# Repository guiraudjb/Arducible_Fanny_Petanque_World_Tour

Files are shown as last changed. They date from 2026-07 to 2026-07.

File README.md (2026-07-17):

# Fanny Pétanque World Tour

*An #ARDUCIBLE pétanque game.*

Borne d'arcade de pétanque en Python/Pygame : le joueur vise trois cibles
physiques à capteurs à effet Hall (pilotées par un Arduino Leonardo en
clavier), pendant qu'une webcam avec suivi de pose (MediaPipe) vérifie qu'il
reste dans la zone de tir. Tour du monde à travers 115 pays, chacun avec son
hymne, son portrait et sa réplique.

## Comment ça marche

- **Les cibles sont physiques**, montées sur un socle et équipées de capteurs
  à effet Hall. Elles sont raccordées à un **Arduino Leonardo**, que
  l'ordinateur reconnaît comme un clavier USB : toucher une cible envoie une
  touche (`E`, `R` ou `T`) au jeu.
- **La webcam ne sert pas à viser.** Couplée à un suivi de pose
  ([MediaPipe](https://ai.google.dev/edge/mediapipe)), elle vérifie juste que
  le joueur est bien positionné dans la zone de tir désignée. S'il en sort,
  les cibles sont inhibées (`zoneinterdite`) jusqu'à ce qu'il y revienne.
- **Tour du monde.** Chaque série de tirs réussis (`hits_per_country` dans
  `config.ini`) fait passer au pays suivant parmi 115 : décor, hymne
  national, portrait et réplique de la compagne de route Fanny changent à
  chaque étape (voir `Scripts/dialogues.py`).
- Le jeu reste jouable sans webcam ni cibles physiques (mode clavier seul).

## Les 4 jeux en un coup d'œil

Un seul châssis physique (3 cibles en ligne) sert au jeu de base, un second
châssis (7 cibles en étoile de David, cochonet au centre) sert à Hardcore et
Round the Clock. Quizz ne tire sur aucun châssis.

| Jeu | Fichier | Chassis | Principe | Touches | Modes | High score |
|---|---|---|---|---|---|---|
| **Fanny World Tour** | `main.py` | 3 cibles en ligne | Solo, contre-la-montre, tour du monde | `E R T` | Tour complet ou par continent | `[Score]` |
| **Hardcore** | `main_hardcore.py` | 7 cibles étoile | Identique à Fanny, cochonet = pays suivant | `E R T Y U I O` | Tour complet ou par continent | `[Hardcore]` |
| **Quizz** | `main_quizz.py` | Aucun (pas de tir) | 5 questions par pays (pétanque + culture générale) | `E R T` (choix) | Tour complet ou par continent | `[Quizz]` |
| **Round the Clock** | `main_round_the_clock.py` | 7 cibles étoile | Multijoueur tour par tour, viser la cible imposée dans l'ordre 1→7 | `E R T Y U I O` (+ `Y`/`U`/`O` pour options/aide/valider) | Nombre de joueurs (1-6) et de manches (3-12) réglables en jeu | Aucun (non persistant, absent de l'original) |

Déroulement commun à Fanny World Tour, Hardcore et Quizz (Round the Clock a
son propre menu à cibles, voir plus bas) : **accueil** (`INSERT COIN` ou
`FREEPLAY`) → **choix du mode** (tour complet ou un seul continent, carrousel
`E`/`T`, validation `R`, ou lancement automatique au bout de 60 s sans choix)
→ **décompte `GAME START IN`** → **partie** → **écran de fin**, puis retour à
l'accueil.

## Installation

```bash
pip install -r requirements.txt
python main.py
```

Un `config.ini` est généré automatiquement au premier lancement s'il
n'existe pas.

## Configuration (`config.ini`)

| Section | Clé | Rôle |
|---|---|---|
| `TimeSetting` | `intro_length`, `game_length`, `ending_length`, `splash_length` | Durées (s) des différents écrans |
| `BonusTime` | `time`, `country_change_time` | Bonus de temps par tir réussi / par changement de pays |
| `WorldTour` | `hits_per_country` | Nombre de tirs pour passer au pays suivant |
| `CamActivation` | `Webcam` | Active/désactive la webcam. Tout ce qui décrit la caméra elle-même (index, résolution, cadrage de la zone de tir, cadence d'analyse) est dans `camera_calibration.json`, pas ici — voir plus bas |
| `Screen` | `Fullscreen`, `CRT` | Plein écran, effet de superposition CRT rétro |
| `Audio` | `Music`, `Effects`, `FadeoutTime` | Musique de menu, effets sonores, fondu |
| `Resolution` | `Resolution` | `1080`, `720`, `360`, `240` (sinon 1024x768) |
| `Debug` | `DebugLine`, `FPS`, `ShowFps`, `DebugCam`, `Credit`, `FreePlay` | Grille de repérage, FPS cible/affiché, superposition du squelette MediaPipe sur l'image caméra réelle (au lieu d'un fond noir), crédits de départ, mode freeplay (voir ci-dessous) — section partagée par les 3 jeux |
| `Score` | `high_score` | Meilleur score de Fanny World Tour (jeu de base), sauvegardé automatiquement |
| `Hardcore` | `high_score`, `hits_per_country` | Meilleur score et rythme du tour du monde propres au mode Hardcore (7 cibles) |
| `Quizz` | `high_score` | Meilleur score du Quizz (bonnes réponses sur 575), sauvegardé automatiquement |
| `RoundTheClock` | `targets`, `default_players`, `min_players`, `max_players`, `default_rounds`, `min_rounds`, `max_rounds`, `shots_per_turn`, `hit_cooldown_ms`, `menu_cooldown_ms`, `banner_duration_s` | Réglages propres à Round the Clock (pas de high score persistant) |

### Crédits / mode freeplay

Comportement identique sur les 3 jeux (Fanny World Tour, Hardcore, Round the
Clock) : par défaut, l'écran d'accueil affiche **INSERT COIN** et le nombre
de crédits (`[Debug] Credit`) en bas à droite tant qu'aucun crédit n'est
disponible ; la touche `C` en ajoute un (borne réelle : pièce détectée par
l'Arduino). Sur Hardcore et Round the Clock, les 7 touches de cible
`E R T Y U I O` occupent déjà tout l'alphabet utile du chassis étoile, d'où
le choix de `C`, libre sur les 3 jeux.

Avec `[Debug] FreePlay = True` : "INSERT COIN" et le compteur de crédits
sont remplacés par **"PRESS A TARGET TO PLAY"** / **FREEPLAY**. Presser
n'importe quelle cible physique équivaut alors à insérer un crédit fictif —
Fanny/Hardcore/Quizz lancent leur écran de choix du mode (voir ci-dessous),
Round the Clock débloque directement son menu (`O` pour démarrer).

### Choix du mode (tour complet ou par continent)

Sur Fanny World Tour, Hardcore et Quizz, un crédit disponible ouvre un écran
de sélection avant que la partie ne démarre : un mode à la fois au centre
(tour complet des 115 pays, ou un seul continent), avec le nombre de pays
qu'il contient. Navigation au carrousel — `E` précédent, `T` suivant, `R`
valider — matérialisée par les 3 boules physiques du socle (gauche/centre/
droite), le joueur n'ayant pas de clavier sous les yeux sur la borne. Sans
choix au bout de **60 secondes**, la partie démarre automatiquement sur le
mode affiché (comme un appui sur `R`). Seul le mode "Tour complet" alimente
le high score de sa section (`[Score]`/`[Hardcore]`/`[Quizz]`) — un score sur
un seul continent, moins long, n'est pas comparable et s'affiche à part.

## Contrôles clavier

| Touche | Action |
|---|---|
| `E` / `R` / `T` | Cible gauche / centre / droite (normalement envoyées par l'Arduino) |
| `C` | Ajoute un crédit |
| `M` | Coupe / relance la musique |
| `S` | Active / coupe les effets sonores |
| `Échap` | Quitte le jeu |

## Structure du projet

```
main.py                        Fanny World Tour : boucle de jeu et logique d'écran
main_hardcore.py                Hardcore (7 cibles), fork de main.py
main_quizz.py                   Quizz (sans tir), fork de main.py
main_round_the_clock.py         Round the Clock (7 cibles, multijoueur), indépendant
Scripts/init.py                 Config.ini, polices, couleurs, canaux audio
Scripts/Sprites.py               Sprites (cibles, fonds, Fanny, bulles de dialogue)
Scripts/opencvcam.py             Capture webcam + détection de pose MediaPipe
Scripts/camera_calibration.py    Lecture/écriture camera_calibration.json
Scripts/dialogues.py             Données des 115 pays (généré automatiquement)
Scripts/quiz_questions.py        Questions du quizz par pays (voir main_quizz.py)
Scripts/quiz_audio.py            Retrouve le mp3 TTS correspondant à un texte de quizz
Scripts/round_the_clock/         État et sprites propres à Round the Clock
assets/                          Images, sons, fonts, modèle MediaPipe
```

## Calibration de la caméra

`calibrate_camera.py` est un script autonome (indépendant des deux jeux) pour
régler la webcam et la zone de tir qu'elle analyse : index de la caméra,
résolution de capture (réglage manuel pixel par pixel, ou menu déroulant
"Preset resolution" listant les résolutions courantes — la caméra détectée
est automatiquement sondée pour ne proposer que celles qu'elle supporte
réellement), taille et position (décalage) de la zone recadrée envoyée à
MediaPipe. Deux fenêtres live — l'image caméra complète avec la zone en
surbrillance, et exactement ce que le jeu voit (recadrage + squelette
détecté + statut "ZONE OK"/"HORS ZONE") — permettent d'ajuster les curseurs
jusqu'à ce que le cadrage corresponde à la zone marquée au sol.

```bash
python3 calibrate_camera.py
# ou
./run_calibrate_camera.sh
```

Réglages enregistrés dans `camera_calibration.json` (à la racine du dépôt,
**pas** `config.ini`) : un profil complet par index de caméra, pour ne pas
perdre le calibrage d'une caméra en en recalibrant une autre — changer de
caméra dans le script recharge automatiquement son profil déjà sauvegardé.
`config.ini` garde seulement l'interrupteur `[CamActivation] Webcam`.

Sauvegarde : bouton **SAUVEGARDER** cliquable en haut à gauche de la fenêtre
"Camera complete" (vert = modifications non sauvegardées, gris = déjà à
jour), ou touche `s` — les deux font la même chose : sauvegardent le profil
de la caméra courante et en font la caméra active pour les jeux.

Autres touches : `r` réinitialise aux valeurs sauvegardées, `p` ressonde les
résolutions supportées, `q`/Échap quitte.

## Round the Clock (chassis à 7 cibles)

`main_round_the_clock.py` est un **second jeu**, indépendant de Fanny World
Tour, pour un chassis différent équipé de **7 cibles physiques disposées en
étoile de David** (6 boules sur les pointes de l'étoile, un **cochonet** au
centre). Même principe électronique (capteurs à effet Hall → Arduino →
clavier USB, touches `E R T Y U I O` pour les cibles 1 à 7), mais un jeu très
différent : un **multijoueur au tour par tour (1 à 6 joueurs, 3 à 12
manches)**, porté fidèlement depuis la version Lua/Defold d'origine
(`ressources/Petanque-challenge-Round-the-clock/`).

- Chaque joueur dispose de 3 tirs par passage et doit toucher les cibles
  dans l'ordre 1 à 7 (au-delà, cible aléatoire).
- Toucher une autre cible que celle désignée compte comme un raté — c'est
  aussi le seul moyen de comptabiliser un tir qui n'a touché aucune cible
  physique (pas de capteur dédié à "l'échec total").
- Jouable sans matériel physique : flèches gauche/droite simulent
  respectivement un tir réussi / raté sur la cible active (pas de bouton
  affiché à l'écran, c'est un raccourci clavier discret).
- Reprend le suivi de zone par webcam (MediaPipe) comme Fanny World Tour
  (absent du jeu Defold d'origine, ajouté lors du portage) : même position à
  l'écran (caméra et anneau rouge/vert centrés en haut) et même système de
  double fond par pays (variante `.jpg` pleine si pas de webcam, variante
  `.png` à découpe ovale transparente si webcam active, à travers laquelle
  la caméra apparaît).
- Le décor change de pays (parmi les fonds de `assets/Images/BackgroundWorldTour/`
  déjà utilisés par Fanny World Tour) après chaque tir réussi.
- Menu et écran de fin reprennent l'illustration de fin de Fanny World Tour
  (`assets/Images/EndingScreenWorldTour.jpg`).

```bash
python3 main_round_the_clock.py
# ou
./run_round_the_clock.sh
```

Partage le même `config.ini` que Fanny World Tour (sections `Screen`,
`Audio`, `CamActivation`, `Debug`, `Resolution` communes), avec sa propre
section `[RoundTheClock]` (nombre de joueurs/manches par défaut, tirs par
passage, anti-rebond).

## Hardcore (chassis à 7 cibles)

`main_hardcore.py` est un **troisième jeu** : le principe exact de Fanny
World Tour (solo, contre-la-montre, tour du monde à travers 115 pays, Fanny
en compagne de route) mais joué sur le chassis à **7 cibles en étoile de
David** de Round the Clock, au lieu des 3 cibles en ligne du jeu d'origine.
Réutilise directement `Scripts/init.py` et `Scripts/Sprites.py` (mêmes
fonds, portraits, hymnes, webcam) — seule la gestion des cibles change.

- 7 cibles, touches `E R T Y U I O`. Le tir qui fait passer au pays suivant
  (score+1 multiple de `hits_per_country`) vise systématiquement le
  **cochonet**, au centre de l'étoile ; tous les autres tirs visent une
  boule périphérique tirée au hasard (jamais deux fois de suite la même).
- Pas d'annonce vocale de cible ("gauche/centre/droite" ne correspond plus
  à rien en étoile) : seul le son d'impact joue.
- `high_score` et `hits_per_country` (rythme du tour du monde) propres à
  Hardcore, dans leur propre section `[Hardcore]` de `config.ini`,
  indépendants du jeu de base.

```bash
python3 main_hardcore.py
# ou
./run_hardcore.sh
```

## Quizz (tour du monde + culture générale, sans tir)

`main_quizz.py` est un **quatrième jeu**, quizz uniquement : pas de cibles,
pas de webcam, pas de chrono de partie. Après avoir inséré un crédit, le
joueur enchaîne directement les **115 quizz** (un par pays du tour, 5
questions chacun) dans l'ordre, en répondant avec les touches `E R T`
(choix gauche/centre/droite). Le score final est le nombre total de bonnes
réponses sur l'ensemble du tour (sur 575).

- Décor, hymne et portrait de Fanny changent à chaque pays, comme dans
  Fanny World Tour, mais pilotés directement par pays plutôt que par un
  score de tir.
- Questions dans `Scripts/quiz_questions.py` (généré à partir de
  `Scripts/dialogues.py` + une table de métadonnées pays) : 1 question sur
  la pétanque dans le pays (reconnaître la bonne réplique de Fanny parmi 3),
  4 questions de culture générale (capitale, continent, langue, monnaie).
  Chaque mauvaise réponse est toujours un vrai fait — juste celui d'un
  *autre* pays de la liste — jamais une donnée inventée.
- Questions et réponses affichées à l'écran avec une police pleine à
  accentuation complète (`assets/RoundTheClock/Fonts/DejaVuSans.ttf`) —
  Alfa Slab One n'a pas les glyphes accentués (é, à, ç...) nécessaires en
  français — et **narrées en voix de synthèse** (gTTS) : un mp3 par texte
  unique dans `assets/Sounds/QuizzTTS/`, généré hors-ligne par
  `ressources/utils/generate_quiz_audio.py` et retrouvé à l'exécution via
  `Scripts/quiz_audio.py` (silencieux si un fichier manque plutôt que de
  planter).
- `high_score` propre à Quizz (nombre de bonnes réponses sur 575), dans sa
  propre section `[Quizz]` de `config.ini`, indépendant des autres jeux.

```bash
python3 main_quizz.py
# ou
./run_quizz.sh
```

## Licence

CC BY 4.0 — voir [`LICENSE`](LICENSE).

Fanny Pétanque World Tour © Jean-Baptiste Guiraud. Vous êtes libre de
partager et d'adapter ce travail, y compris à des fins commerciales, à
condition de créditer l'auteur.

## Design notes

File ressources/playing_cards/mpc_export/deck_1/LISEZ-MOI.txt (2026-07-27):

Fanny Pétanque World Tour — Volume 1 (54 cartes)
Export pour MakePlayingCards.com

1. Aller sur makeplayingcards.com -> Design & Print -> Game / Custom Cards
   -> choisir le produit "Custom Game Cards (63 x 88mm)".
2. Quantité : 54 cartes uniques, 1 exemplaire de chaque (1 jeu).
3. Verso ("Card Back") : choisir l'option "same image for all cards" /
   "one card back for the whole deck" et uploader back.png.
4. Recto ("Card Front") : uploader les 54 fichiers du
   dossier fronts/ EN GARDANT L'ORDRE NUMÉRIQUE du préfixe (01_, 02_, ...) -
   c'est l'ordre A,2,3...K de Coeur, Carreau, Trèfle, Pique puis les Jokers.
5. Les fichiers sont déjà au bon format (fond perdu + marge de sécurité
   inclus, 300 dpi) : ne pas les recadrer ni les redimensionner sur le site.

Fichiers : 54 images dans fronts/ + back.png (verso unique).
Tout est aussi disponible pré-zippé : deck_1.zip

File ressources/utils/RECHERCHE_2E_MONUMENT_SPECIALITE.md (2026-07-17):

# Recherche du 2e monument / site touristique / spécialité par pays

Registre des recherches menées pour trouver, pour chacun des 112 pays du
tour (`Scripts/dialogues.py`), un **second** monument, site touristique ou
spécialité locale réel et vérifiable, DIFFÉRENT de celui déjà utilisé dans
`quiz_monuments_facts.py` (question 2 du quizz). Ce second fait remplace
la question "sur quel continent ?" (question 5), jugée trop facile, sans
jamais révéler dans l'énoncé qu'il s'agit d'un monument ou d'une
spécialité (voir `ressources/utils/build_quiz_questions.py`).

Données dans `ressources/utils/quiz_second_monuments_facts.py`
(`SECOND_MONUMENTS`), catégorisées dans
`ressources/utils/quiz_monument_categories.py`
(`SECOND_MONUMENT_CATEGORIES`) pour permettre des distracteurs de la même
catégorie (château face à château, etc.), comme pour la question 2.

**112/112 pays documentés**, aucun "aucune information trouvée".

## Europe

0 Allemagne : la porte de Brandebourg — fr.wikipedia.org/wiki/Porte_de_Brandebourg
1 Andorre : la Casa de la Vall — museus.ad/fr/monuments/casa-de-la-vall2, en.wikipedia.org/wiki/Casa_de_la_Vall
2 Angleterre : Big Ben — fr.wikipedia.org/wiki/Big_Ben
4 Autriche : le Sachertorte — fr.wikipedia.org/wiki/Sachertorte
5 Belgique : l'Atomium — fr.wikipedia.org/wiki/Atomium
6 Bulgarie : la vallée des Roses — fr.wikipedia.org/wiki/Vallée_des_Roses_(Bulgarie)
7 Danemark : les jardins de Tivoli — fr.wikipedia.org/wiki/Jardins_de_Tivoli
8 Écosse : le château d'Édimbourg — fr.wikipedia.org/wiki/Château_d'Édimbourg
9 Espagne : l'Alhambra de Grenade — fr.wikipedia.org/wiki/Alhambra
10 Estonie : le Laulupidu — estonianworld.com, en.wikipedia.org/wiki/Estonian_Song_Festival
11 Finlande : la forteresse de Suomenlinna — fr.wikipedia.org/wiki/Suomenlinna
12 France : le Mont-Saint-Michel — fr.wikipedia.org/wiki/Mont-Saint-Michel
13 Guernesey : Hauteville House — fr.wikipedia.org/wiki/Hauteville_House
14 Hongrie : les bains Széchenyi — fr.wikipedia.org/wiki/Bains_Széchenyi
15 Irlande : Newgrange — fr.wikipedia.org/wiki/Newgrange
16 Italie : la tour de Pise — fr.wikipedia.org/wiki/Tour_de_Pise
17 Jersey : le château de Mont Orgueil — fr.wikipedia.org/wiki/Château_de_Mont_Orgueil
18 Lettonie : la vieille ville de Riga (Art nouveau) — whc.unesco.org/en/list/852
19 Lituanie : la colline des Croix — fr.wikipedia.org/wiki/Colline_des_Croix
20 Luxembourg : le palais grand-ducal — fr.wikipedia.org/wiki/Palais_grand-ducal_(Luxembourg)
21 Monaco : le Grand Prix de Monaco — fr.wikipedia.org/wiki/Grand_Prix_automobile_de_Monaco
22 Norvège : les stavkirker — fr.wikipedia.org/wiki/Stavkirke
23 Pays-Bas : le parc floral de Keukenhof — fr.wikipedia.org/wiki/Keukenhof
24 Pays de Galles : Llanfairpwllgwyngyll... — en.wikipedia.org/wiki/Llanfairpwllgwyngyll
25 Pologne : les mines de sel de Wieliczka — fr.wikipedia.org/wiki/Mine_de_sel_de_Wieliczka
26 Portugal : le palais de Pena — fr.wikipedia.org/wiki/Palais_national_de_Pena
27 Roumanie : le palais du Parlement — en.wikipedia.org/wiki/Palace_of_the_Parliament
28 Russie : la cathédrale Saint-Basile-le-Bienheureux — fr.wikipedia.org/wiki/Cathédrale_Basile-le-Bienheureux
29 Saint-Marin : les timbres-poste saint-marinais — en.wikipedia.org/wiki/Postage_stamps_and_postal_history_of_San_Marino
30 Serbie : le monastère de Studenica — fr.wikipedia.org/wiki/Monastère_de_Studenica
31 Slovaquie : le château de Spiš — fr.wikipedia.org/wiki/Château_de_Spiš
32 Slovénie : les grottes de Postojna — fr.wikipedia.org/wiki/Grottes_de_Postojna
33 Suède : l'Icehotel de Jukkasjärvi — fr.wikipedia.org/wiki/Icehotel
34 Suisse : le Jungfraujoch — fr.wikipedia.org/wiki/Jungfraujoch
35 Tchéquie : l'horloge astronomique de Prague — fr.wikipedia.org/wiki/Horloge_astronomique_de_Prague
37 Ukraine : le bortsch ukrainien — ich.unesco.org/fr/USL/la-culture-de-la-preparation-du-bortsch-ukrainien-01852

## Asie

3 Arménie : le monastère de Guéghard — whc.unesco.org/en/list/960
36 Turquie : Pamukkale — en.wikipedia.org/wiki/Pamukkale
65 Afghanistan : le Minaret de Jam — whc.unesco.org/en/list/211
66 Bangladesh : les Sundarbans — en.wikipedia.org/wiki/Sundarbans
67 Brunei : Kampong Ayer — en.wikipedia.org/wiki/Kampong_Ayer
68 Cambodge : le temple de Preah Vihear — whc.unesco.org/en/list/1224
69 Chine : l'Armée de terre cuite de Xi'an — fr.wikipedia.org/wiki/Armée_de_terre_cuite
70 Corée du Sud : le palais Gyeongbokgung — en.wikipedia.org/wiki/Gyeongbokgung
71 Inde : le Fort Rouge de Delhi — en.wikipedia.org/wiki/Red_Fort
72 Indonésie : le temple de Prambanan — en.wikipedia.org/wiki/Prambanan
73 Iran : la place Naghsh-e Jahan — en.wikipedia.org/wiki/Naqsh-e_Jahan_Square
74 Japon : le château de Himeji — en.wikipedia.org/wiki/Himeji_Castle
75 Kazakhstan : le mausolée de Khoja Ahmed Yasavi — whc.unesco.org/en/list/1103
76 Kirghizistan : le lac Issyk-Koul — islands.com
77 Laos : la Plaine des Jarres — en.wikipedia.org/wiki/Plain_of_Jars
78 Malaisie : les grottes de Batu — en.wikipedia.org/wiki/Batu_Caves
79 Mongolie : le monastère d'Erdene Zuu — en.wikipedia.org/wiki/Erdene_Zuu_Monastery
80 Myanmar : Bagan — en.wikipedia.org/wiki/Bagan
81 Népal : Lumbini — en.wikipedia.org/wiki/Lumbini
82 Pakistan : la mosquée Badshahi — en.wikipedia.org/wiki/Badshahi_Mosque
83 Philippines : les Chocolate Hills — en.wikipedia.org/wiki/Chocolate_Hills
84 Singapour : Gardens by the Bay — en.wikipedia.org/wiki/Gardens_by_the_Bay
85 Taïwan : le bubble tea — taipeitimes.com
86 Thaïlande : le parc historique d'Ayutthaya — en.wikipedia.org/wiki/Ayutthaya_Historical_Park
87 Turkménistan : le cheval Akhal-Teke — en.wikipedia.org/wiki/Akhal-Teke
88 Vietnam : la vieille ville de Hoi An — en.wikipedia.org/wiki/Hoi_An

## Afrique

38 Algérie : Timgad — whc.unesco.org/en/list/194
39 Bénin : la Porte du Non-Retour d'Ouidah — en.wikipedia.org/wiki/Door_of_No_Return,_Ouidah
40 Burkina Faso : la Grande Mosquée de Bobo-Dioulasso — en.wikipedia.org/wiki/Grand_Mosque_of_Bobo-Dioulasso
41 Cameroun : le mont Cameroun — en.wikipedia.org/wiki/Mount_Cameroon
42 Comores : la Grande Mosquée du Vendredi de Moroni — fr.wikipedia.org/wiki/Mosquée_de_Moroni
43 Congo : la basilique Sainte-Anne-du-Congo — fr.wikipedia.org/wiki/Basilique_Sainte-Anne-du-Congo_de_Brazzaville
44 Côte d'Ivoire : Grand-Bassam — whc.unesco.org/en/list/1322
45 Djibouti : le lac Abbé — cityzeum.com
46 Égypte : le temple d'Abou Simbel — fr.wikipedia.org/wiki/Abou_Simbel
47 Gabon : le parc national de Loango — en.wikipedia.org/wiki/Loango_National_Park
48 Guinée : le mont Nimba — whc.unesco.org/en/list/155
49 Libye : la vieille ville de Ghadamès — whc.unesco.org/en/list/362
50 Madagascar : les Tsingy de Bemaraha — whc.unesco.org/en/list/494
51 Mali : la falaise de Bandiagara (pays Dogon) — whc.unesco.org/en/list/516
52 Maurice : Le Morne Brabant — whc.unesco.org/en/list/1259
53 Mauritanie : la structure de Richat — en.wikipedia.org/wiki/Richat_Structure
54 Maroc : le Jardin Majorelle — en.wikipedia.org/wiki/Majorelle_Garden
55 Niger : la réserve naturelle de l'Aïr et du Ténéré — whc.unesco.org/en/list/573
56 Ouganda : les tombeaux des rois du Buganda à Kasubi — whc.unesco.org/en/list/1022
57 République Centrafricaine : le parc national Manovo-Gounda St Floris — whc.unesco.org/en/list/475
58 RD Congo : la réserve de faune à okapis — whc.unesco.org/en/list/718
59 Sénégal : le lac Rose — fr.wikipedia.org/wiki/Lac_Rose
60 Seychelles : l'atoll d'Aldabra — whc.unesco.org/en/list/185
61 Tchad : le parc national de Zakouma — africanparks.org
62 Togo : le marché des féticheurs d'Akodessewa — fr.wikipedia.org/wiki/Marché_des_féticheurs
63 Tunisie : la médina de Tunis — whc.unesco.org/en/list/36
64 Zambie : le parc national de South Luangwa — southluangwa.com

## Amérique

89 Argentine : le glacier Perito Moreno — en.wikipedia.org/wiki/Perito_Moreno_Glacier
90 Bolivie : Tiwanaku — whc.unesco.org/en/list/567
91 Canada : le sirop d'érable — thecanadianencyclopedia.ca
92 Chili : Torres del Paine — en.wikipedia.org/wiki/Torres_del_Paine_National_Park
93 Colombie : Carthagène des Indes — whc.unesco.org/en/list/285
94 Costa Rica : Monteverde — en.wikipedia.org/wiki/Monteverde_Cloud_Forest_Reserve
95 Cuba : La Havane Vieille — whc.unesco.org/en/list/204
96 Équateur : le chapeau « Panama » de Montecristi — ecuadorianhands.com
97 États-Unis : le Grand Canyon — en.wikipedia.org/wiki/Grand_Canyon
98 Guatemala : Antigua Guatemala — whc.unesco.org/en/list/65
99 Haïti : le Palais Sans-Souci — whc.unesco.org/en/list/180
100 Mexique : la tequila — en.wikipedia.org/wiki/Tequila
101 Paraguay : le barrage d'Itaipu — en.wikipedia.org/wiki/Itaipu_Dam
102 Pérou : les lignes de Nazca — whc.unesco.org/en/list/700
103 République Dominicaine : le larimar — en.wikipedia.org/wiki/Larimar
104 Uruguay : Colonia del Sacramento — whc.unesco.org/en/list/747
105 Venezuela : les éclairs du Catatumbo — en.wikipedia.org/wiki/Catatumbo_lightning

## Océanie

106 Australie : la Grande Barrière de Corail — whc.unesco.org/en/list/154
107 Nouvelle-Calédonie : le lagon de Nouvelle-Calédonie — whc.unesco.org/en/list/1115
108 Nouvelle-Zélande : le Hobbiton Movie Set — en.wikipedia.org/wiki/Hobbiton_Movie_Set
109 Tahiti : le marae Taputapuatea — whc.unesco.org/en/list/1529
110 Vanuatu : le saut du Gol — fr.wikipedia.org/wiki/Saut_du_gol_(Vanuatu)
111 Wallis-et-Futuna : le site de Talietumu — easyvoyage.com, archeodyssee.fr

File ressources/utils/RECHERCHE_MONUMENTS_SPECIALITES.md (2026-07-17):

# Recherche monuments / sites touristiques / spécialités locales par pays

Registre des recherches menées pour documenter, pour chacun des 112 pays du
tour (`Scripts/dialogues.py`), un monument, site touristique ou spécialité
locale réel, précis et reconnaissable — utilisé pour la question 3 du
quizz (`Scripts/quiz_questions.py`, voir
`ressources/utils/build_quiz_questions.py` et
`ressources/utils/quiz_monuments_facts.py`).

Contrairement à la recherche pétanque (voir `RECHERCHE_PETANQUE_PAYS.md`),
la plupart de ces faits relèvent de la culture générale bien établie
(Tour Eiffel, Taj Mahal, Machu Picchu...) et n'ont pas nécessité de
recherche web poussée ; une recherche ciblée a été faite pour les pays
moins immédiatement connus (marquée "à vérifier" ci-dessous, avec sources).

**112/112 pays documentés** — aucun "aucune information trouvée" cette
fois (contrairement à la recherche pétanque, la culture générale/tourisme
offre toujours au moins un point d'ancrage réel pour chaque pays).

## Europe

Allemagne : château de Neuschwanstein · Andorre : escudella (à vérifier —
routard.com, grandvalira.com) · Angleterre : Stonehenge · Arménie :
monastère de Khor Virap (à vérifier — nomadays.fr, voyagearmenie.com) ·
Autriche : château de Schönbrunn · Belgique : Manneken-Pis · Bulgarie :
monastère de Rila · Danemark : la Petite Sirène · Écosse : Loch Ness ·
Espagne : Sagrada Família · Estonie : vieille ville de Tallinn (UNESCO,
whc.unesco.org) · Finlande : le sauna · France : tour Eiffel · Guernesey :
la vache Guernesey (à vérifier — fr.wikipedia.org, la-viande.fr) · Hongrie :
Parlement de Budapest · Irlande : falaises de Moher · Italie : Colisée ·
Jersey : la Jersey Royal (à vérifier — en.wikipedia.org, jersey.com) ·
Lettonie : Monument de la Liberté à Riga (à vérifier — cestee.fr,
routard.com) · Lituanie : château de Trakai · Luxembourg : Casemates du
Bock · Monaco : Casino de Monte-Carlo · Norvège : Geirangerfjord · Pays-Bas :
moulins de Kinderdijk · Pays de Galles : château de Caernarfon · Pologne :
château du Wawel · Portugal : tour de Belém · Roumanie : château de Bran ·
Russie : le Kremlin · Saint-Marin : Tre Torri du Mont Titano (vérifié —
whc.unesco.org/en/list/1245/) · Serbie : forteresse de Belgrade
(Kalemegdan) · Slovaquie : château de Bratislava (vérifié —
fr.wikipedia.org) · Slovénie : lac de Bled (vérifié — fr.wikipedia.org) ·
Suède : le Vasa · Suisse : le Cervin · Tchéquie : château de Prague ·
Turquie : Sainte-Sophie · Ukraine : Laure des Grottes de Kiev.

## Afrique

Algérie : Casbah d'Alger · Bénin : palais royaux d'Abomey · Burkina Faso :
ruines de Loropéni (à vérifier — whc.unesco.org/en/list/1225/) · Cameroun :
palais royal de Foumban (à vérifier — ayilaa.com) · Comores : le Karthala
(à vérifier — habarizacomores.com) · Congo : parc national d'Odzala-Kokoua
(à vérifier — fr.wikipedia.org) · Côte d'Ivoire : basilique Notre-Dame de
la Paix de Yamoussoukro · Djibouti : lac Assal (à vérifier —
guide.visitdjibouti.dj) · Égypte : pyramides de Gizeh · Gabon : parc
national de la Lopé (à vérifier — fr.wikipedia.org) · Guinée : massif du
Fouta Djalon (à vérifier — jeuneafrique.com) · Libye : Leptis Magna ·
Madagascar : allée des Baobabs · Mali : Grande Mosquée de Djenné · Maurice :
Terres des Sept Couleurs de Chamarel · Mauritanie : Chinguetti (à vérifier
— voyagemauritanie.com) · Maroc : médina de Fès · Niger : Grande Mosquée
d'Agadez (en.wikipedia.org/wiki/Agadez_Mosque) · Ouganda : parc national
impénétrable de Bwindi · République Centrafricaine : réserve de
Dzanga-Sangha (à vérifier — ambition-journal.org) · République
Démocratique du Congo : parc national des Virunga (fr.wikipedia.org) ·
Sénégal : île de Gorée · Seychelles : Vallée de Mai · Tchad : Guelta
d'Archei (à vérifier — chadvisit.com) · Togo : Koutammakou · Tunisie :
amphithéâtre d'El Jem · Zambie : chutes Victoria.

## Asie

Afghanistan : Bouddhas de Bamiyan (à vérifier — spherama.com) · Bangladesh :
le Jamdani · Brunei : mosquée Sultan Omar Ali Saifuddien (à vérifier —
bruneitourism.com) · Cambodge : Angkor Vat · Chine : Grande Muraille ·
Corée du Sud : le kimchi · Inde : Taj Mahal · Indonésie : Borobudur · Iran :
Persépolis · Japon : Mont Fuji · Kazakhstan : tour Baïterek · Kirghizistan :
tour Bourana (à vérifier — voyagekirghizistan.com) · Laos : That Luang ·
Malaisie : tours Petronas · Mongolie : statue équestre de Gengis Khan (à
vérifier — fr.wikipedia.org) · Myanmar : pagode Shwedagon · Népal :
l'Everest · Pakistan : ruines de Mohenjo-daro · Philippines : rizières de
Banaue · Singapour : le Merlion · Taïwan : Taipei 101 · Thaïlande : Wat
Arun · Turkménistan : Porte de l'Enfer (à vérifier —
fr.wikipedia.org/wiki/Porte_de_l'Enfer_(Turkménistan)) · Vietnam : baie
d'Halong.

## Amérique

Argentine : chutes d'Iguazu · Bolivie : Salar de Uyuni (à vérifier —
voyage-bolivie.com) · Canada : chutes du Niagara · Chili : Moaï de l'île
de Pâques · Colombie : cathédrale de Sel de Zipaquirá · Costa Rica : volcan
Arenal · Cuba : cigares cubains (Habanos) · Équateur : îles Galápagos ·
États-Unis : Statue de la Liberté · Guatemala : Tikal · Haïti : Citadelle
Laferrière (à vérifier — fr.wikipedia.org) · Mexique : Chichén Itzá ·
Paraguay : ruines jésuites de Trinidad (à vérifier — en.wikipedia.org) ·
Pérou : Machu Picchu · République Dominicaine : Zone coloniale de
Saint-Domingue · Uruguay : « La Mano » à Punta del Este · Venezuela : Salto
Ángel.

## Océanie

Australie : Opéra de Sydney · Nouvelle-Calédonie : le bougna (à vérifier —
nouvellecaledonie.travel) · Nouvelle-Zélande : Milford Sound · Tahiti : le
poisson cru au lait de coco (tahititourisme.com) · Vanuatu : volcan Yasur
(vérifié — vanuatu.travel) · Wallis-et-Futuna : cathédrale Notre-Dame de
l'Assomption de Mata-Utu (à vérifier — source unique, cyriljarnias.com).

## Données complètes

Le fait complet (nom + description) pour chaque pays est dans
`ressources/utils/quiz_monuments_facts.py` (dict `MONUMENTS`, clé = index
du pays dans `Scripts/dialogues.py`).

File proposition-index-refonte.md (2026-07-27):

# Fanny Pétanque World Tour

## Tapez la boule. Partez pour le tour du monde.

Posez-vous devant la borne, prenez la boule en main, et lancez. C'est ça, Fanny Pétanque World Tour : les vraies sensations de la pétanque, sur une vraie borne d'arcade — trois cibles physiques à toucher, pas un écran tactile à effleurer.

Chaque tir réussi vous fait avancer un peu plus loin sur la carte. Le décor change, l'hymne national retentit, et Fanny — votre partenaire de route — troque sa tenue pour celle du pays suivant. Un tir, un pays. 115 pays à parcourir, de la France au Japon en passant par Madagascar et les Fidji.

---

### Une vraie borne, de vraies sensations

Oubliez la manette. Ici, on joue avec de vraies boules de pétanque, sur de vraies cibles montées sur ressort. Chaque impact est encaissé, amorti, et transformé en score à l'écran. Le geste est le même que sur le boulodrome — la précision, la force, le petit ajustement du poignet au dernier moment.

### 115 pays, un seul jeu

À chaque série de tirs gagnée, le monde défile sous vos yeux. Nouveau décor, nouvel hymne, nouveau portrait de Fanny — et un petit mot d'histoire sur la pétanque locale, glissé au passage. On dit *petanca* en Espagne, *petong* en Thaïlande : le jeu se souvient de tout.

### Un arbitre numérique toujours à l'œil

Une caméra veille discrètement pendant la partie. Son seul rôle : vérifier que vous restez bien dans votre zone de tir, comme le ferait un arbitre sur un vrai terrain. Sortez de la zone, et le jeu patiente sagement que vous reveniez — jamais de triche possible.

### Les bonus du voyage

Le tour du monde laisse des souvenirs : une collection de cartes postales illustrées pour chacun des 115 pays, un jeu de cartes à l'effigie de Fanny en tenue traditionnelle, et trois petits classiques — solitaire, poker, blackjack — jouables directement dans le navigateur pour patienter entre deux parties.

---

## Sous le capot : construire sa propre borne

Vous avez aimé jouer ? Vous pouvez construire la vôtre. Fanny Pétanque World Tour est un projet **100&nbsp;% open source**, publié sous licence **Creative Commons BY&nbsp;4.0** : plans de découpe, modèles 3D, schémas électroniques et code source, tout est en libre accès — réutilisation libre, y compris commerciale, à condition de citer l'auteur.

La suite de cette page s'adresse aux makers, ingénieurs et bricoleurs curieux de savoir ce qui se cache derrière chaque tir détecté. On y descend d'un cran technique.

---

## Le laboratoire

### Architecture matérielle

Toute la borne repose sur un châssis en tôle pliée : les plis de la tôle lui donnent, à eux seuls, la rigidité nécessaire pour porter les trois articulations sans renfort supplémentaire ni surépaisseur.

Chaque cible encaisse l'impact grâce à une chaîne mécanique pensée pour absorber le choc avant qu'il n'atteigne le châssis :

- **L'axe principal** — une vis à tête creuse **M8×70** — porte l'ensemble du mécanisme et fixe l'amplitude de bascule au moment de l'impact.
- **La rotule GE8C** sert de point de pivot : elle permet au support de basculer librement dans toutes les directions autour d'un seul point fixe.
- **Le tampon en caoutchouc (polychloroprène, dureté 60 SHA)** encaisse l'essentiel du choc par compression, puis restitue l'énergie pour ramener le mécanisme en position — c'est ce mouvement de va-et-vient qui écarte puis réaligne l'aimant face au capteur, déclenchant la détection.

**Notes d'atelier — le choix de la boule :** deux alternatives à la boule en acier standard (∅70&nbsp;mm, ~680&nbsp;g) ont été testées pour un usage en intérieur. La boule souple **Al'Comm** (PVC rempli de microbilles d'acier) reprend exactement le poids et le diamètre d'une boule traditionnelle : elle s'installe sans rien changer au montage. La boule **La Schmolle** (plastique léger, 280&nbsp;g) transmet un impact nettement plus faible à l'axe — un tampon de dureté SHA inférieure au 60 standard est recommandé pour conserver une détection fiable avec ce modèle.

### Électronique

Le signal de chaque cible remonte à une carte **Pro Micro** (puce **ATmega32U4**, brochage compatible Arduino Leonardo — reconnue nativement comme un clavier USB par l'ordinateur). Le firmware embarqué est volontairement minimal : trois entrées numériques lues en boucle, retranscrites en pression/relâchement de touches via la bibliothèque `Keyboard`.

La détection elle-même repose sur un réseau de **capteurs à effet Hall** : chaque cible embarque son propre capteur magnétique, qui détecte le passage d'un aimant sans aucun contact électrique avec la boule. Le câblage suit une topologie simple et robuste : un câble réseau **RJ45** (Cat5/6) par cible ramène signal et alimentation jusqu'à la carte contrôleur, avant une liaison Micro-USB unique vers l'ordinateur.

### Logiciel & vision

Le moteur de jeu est écrit en **Python**, avec **Pygame** pour la boucle de jeu et l'affichage. L'ensemble des paramètres — résolution, plein écran, durées, bonus de temps, nombre de tirs par pays — se règle dans un unique fichier `config.ini`, sans toucher au code.

Le suivi du joueur s'appuie sur **OpenCV** et **MediaPipe Pose Landmarker** : un suivi de posture en temps réel via webcam, utilisé exclusivement pour valider la position du joueur dans sa zone de tir désignée.

Le code source complet est disponible sur un **dépôt Git public**. Sa gestion reste volontairement **manuelle** : pas de pipeline de mise à jour ou de déploiement automatisé — chaque évolution est relue et poussée à la main, au fil des sessions d'atelier.

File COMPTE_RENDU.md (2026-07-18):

# Compte rendu — sessions du 15-18 juillet 2026

Résumé pour reprendre le travail à un autre poste (rappel : la mémoire Claude Code
n'est pas synchronisée entre machines, seul ce dépôt git l'est - voir aussi
`.claude/` pour la config de session). La skill FreeCAD headless mentionnée
plus bas (`~/.claude/skills/freecad-headless/`) est en revanche **locale à
cette machine** : à recréer sur un autre poste si besoin, voir sa description
ci-dessous.

## ✅ Tout est commité et poussé (au 18 juillet)

`git status` est propre sur `main`, à jour avec `origin/main`
(`github.com/guiraudjb/Arducible_Fanny_Petanque_World_Tour` - **dépôt
renommé** depuis `Fanny_P-tanque_World_Tour` le 17 juillet, voir plus bas).
Seuls restent volontairement non versionnés (trop lourds, régénérables, ou
sensibles) :
- `ressources/social_videos/` (~9,6 Go de rendus vidéo), `ressources/playing_cards/`
  (~250 Mo), `ressources/quizz_pdf/_postcards_cache/` (cache d'images
  téléchargées) — tous régénérables via les scripts de `ressources/utils/`.
- `ressources/Petanque-challenge-Round-the-clock/.../.internal/` et
  `x86_64-linux/` (cache/build Defold), `manifest.private.der`/`.public.der`
  (vraie clé privée RSA - **ne jamais commiter**), `social_videos_build.log`.

## Session du 15-16 juillet 2026 (+ suite du 16)

### 1. Écran de choix du continent repositionné
Avant : le décompte "GAME START IN" tournait avant l'écran de choix de mode.
Maintenant : accueil → **choix du continent** → décompte "GAME START IN" →
partie. Nouvel état `start_pregame_countdown()` dans les 3 jeux (gamestate 4
pour `main.py`/`main_hardcore.py`, gamestate 5 pour `main_quizz.py`).

### 2. Police "Neon Glow" abandonnée → Alfa Slab One
Neon Glow n'avait pas les glyphes accentués (« Amérique », « Océanie »
illisibles) et jurait avec le nouveau style. Remplacée partout par **Alfa
Slab One** (`assets/fonts/AlfaSlabOne-Regular.ttf`, licence OFL), choisie
avec l'utilisateur parmi 7 candidats après un vote sur la direction
stylistique (affiche de voyage vintage). `draw_text()` dans les 3 jeux garde
exactement la même signature/dispatch (`fnt`, `col`) : seul le rendu change
(ombre portée au lieu du halo néon superposé), donc aucun site d'appel à
toucher. Les 8 fichiers `NEON GLOW*.otf` ont été supprimés de
`assets/fonts/`.

### 3. Timeout + musique + boules physiques sur l'écran de choix du continent
- **Timeout 60s** : `CONTINENT_SELECT_TIMEOUT` - si le joueur ne choisit pas,
  la partie démarre automatiquement sur le mode affiché (comme un appui sur
  R).
- **Musique de menu maintenue** : le fondu (`channel1.fadeout(9000)`) ne se
  déclenche plus à l'insertion du crédit mais seulement quand le choix est
  validé (`start_pregame_countdown()`) - avant, la musique s'éteignait
  pendant que le joueur choisissait encore.
- **Boules du socle physique au lieu de lettres E/T/R** : le joueur n'a pas
  de clavier sous les yeux. `init_mode_select_cibles()` affiche 3 boules
  (gauche=E, centre=R, droite=T) avec légendes "PRÉCÉDENT/VALIDER/SUIVANT" -
  même principe que les boules déjà utilisées dans l'écran de quizz.

### 4. Palette de couleurs du HUD réajustée
Les couleurs (rouge/orange/jaune/bleu/vert dans `Scripts/init.py`) étaient
calibrées pour l'ancienne police néon - trop vives, elles juraient avec le
nouveau style. Désaturées/réchauffées vers les tons sépia/terracotta de
l'illustration elle-même (échantillonnés par k-means sur les images de
titre/fin), tout en gardant assez de contraste pour rester lisibles sur les
fonds de pays très variés. Choisi avec l'utilisateur parmi 3 options
rendues côte à côte. Un seul point de changement (`Scripts/init.py`), partagé
par les 3 jeux.

**Non touché volontairement** : `Scripts/round_the_clock/state.py` a sa
propre copie indépendante des anciennes couleurs néon (contexte visuel
différent - planches de bois, pas l'affiche vintage) - à voir si l'utilisateur
veut harmoniser un jour.

### 5. Vérification score final / high score + bug trouvé
Vérification demandée par l'utilisateur : la correspondance affichée entre
"YOUR SCORE" et "HIGH SCORE" était **déjà correcte** dans les 3 jeux (testé
cas record et non-record, avec captures d'écran en mode headless). Mais la
vérification a mis en évidence un vrai bug à côté : le test
"score >= high_score → sauver" tournait à **chaque frame** de l'écran de fin
(~10s) au lieu d'une seule fois - mesuré à **283 appels** à
`save_high_score()` pour un seul écran de fin. Corrigé en déplaçant le test
dans `next_gamestate()` (transition 1→2, `main.py`/`main_hardcore.py`) ou
`finish_quiz_tour()` (`main_quizz.py`), au moment exact où le score devient
définitif. Vérifié : 1 seul appel désormais, résultat affiché inchangé.

### 6. Chevauchements HUD corrigés dans `main_hardcore.py`
Sur le chassis à 7 cibles (étoile de David), plusieurs éléments de texte
chevauchaient les sprites des billes/cochonet à l'écran :
- **Score ("POINTS" + valeur)** : décalé de `x=4/20` (chevauchait la cible I,
  la plus haute) → `x=2/20` (rognait le bord gauche de l'écran, trop loin) →
  **`x=LARGEUR_ECRAN/8`**, le compromis qui évite les deux.
- **Temps restant** : recentré à **`(LARGEUR_ECRAN/3, HAUTEUR_ECRAN/3)`** -
  cette position correspond exactement au milieu entre la cible 6/I (la plus
  haute de l'étoile) et la cible 7/O (cochonet, cible centrale), qui
  partagent le même x (`TARGET_LAYOUT` dans `main_hardcore.py`).
- **"Go to the shooting zone"** : d'abord réduit de taille et calé dans
  l'étroit espace libre entre le cochonet et la rangée E/T/R (police custom
  `fnt=3`), mais l'utilisateur a préféré un texte **plus grand** repositionné
  **à droite du cochonet**, dans la zone libre à droite de l'étoile
  (`LARGEUR_ECRAN*4/5`, même hauteur que le cochonet via
  `TARGET_LAYOUT[COCHONET_INDEX][1]`) - la police custom `fnt=3` a été
  retirée (redevenue inutile) et `fnt=2` (Fontsize2) réutilisée telle quelle.
- **"CHOISIS TON MODE"** (écran de choix du continent) : remonté de `y=4/20`
  à `y=2/20`.
- **"GAME START IN" + décompte** (écran d'intro) : bloc des 3 lignes
  recentré verticalement sur l'écran - "GAME START" à `y=8/20`, "IN" pile au
  centre (`y=10/20`), le décompte à `y=12/20` (avant : `6/20`, `8/20`,
  `10/20`, décalé vers le haut de l'écran).

Méthode de vérification : script Python autonome (hors dépôt, dans le
scratchpad de session) import direct de `Scripts.init`/`Scripts.Sprites`
avec `SDL_VIDEODRIVER=dummy`, qui recrée les 7 cibles + le texte aux
nouvelles coordonnées et sauvegarde un PNG (`pygame.image.save`) - permet de
vérifier au pixel près l'absence de chevauchement sans lancer le vrai jeu
(webcam/Arduino absents de ce poste). Différent de la technique
d'exec-injection habituelle ([[feedback_headless_testing_technique]]) : ici
pas besoin de faire tourner `main_hardcore.py` lui-même, juste reproduire le
rendu des éléments concernés.

### 7. Sensibilité de la détection MediaPipe réduite
Signalé : la détection de pose (utilisée pour vérifier que le joueur reste
dans la zone de tir) détectait parfois des "corps" qui n'en étaient pas
(faux positifs). Deux correctifs dans `Scripts/opencvcam.py` (module caméra
partagé par les 3 jeux à cibles) :
- Seuils de confiance MediaPipe relevés de **0.5 à 0.7**
  (`min_pose_detection_confidence`, `min_pose_presence_confidence`,
  `min_tracking_confidence`).
- **Filtre de visibilité par point** : les 6 repères de pied (index 27 à 32,
  chevilles/talons/orteils) ne sont désormais pris en compte pour la
  décision "dans/hors zone" que si `landmark.visibility >= 0.5` chacun ; si
  aucun n'est fiable, la zone est considérée interdite (comportement
  conservateur, identique au cas "aucune pose détectée du tout"). Avant, la
  position d'un point était utilisée même quand MediaPipe n'était pas sûr de
  le voir.

**Non testé en conditions réelles** (pas de caméra sur ce poste) - à valider
sur la borne physique, et à retoucher le seuil 0.7 (à la hausse ou à la
baisse) selon ce qui est observé sur place.

### 8. Textes de post TikTok (hors code, pas dans le dépôt)
Rédaction de légendes/hashtags pour un post TikTok présentant le jeu, angle
final retenu : **refonte graphique + gameplay, premiers essais, appel aux
retours des viewers** (pas un simple teaser hardware). Texte fourni dans la
conversation Claude Code, pas encore posté, pas enregistré dans le dépôt (à
redemander si besoin - non conservé ailleurs que dans l'historique de
session).

## Session du 17-18 juillet 2026

### 1. Tout commité et poussé (9 commits par sujet)
Le vrac non commité des sessions précédentes a été trié en 9 commits
thématiques (licence, CAD/BOM matériel, calibration caméra, Round the Clock,
Quizz, Hardcore + système crédit/freeplay partagé, pays ajoutés, outils
marketing, docs) puis poussé. Au passage : identité git configurée sur ce
poste (`guiraudjb <guiraudjb@gmail.com>`), remote basculé en SSH (HTTPS sans
identifiants stockés ne fonctionnait pas). Plusieurs pièges évités en cours
de route : un dépôt git imbriqué (`ressources/Petanque-challenge-Round-the-clock/`
avait son propre `.git` pointant vers un repo GitHub séparé - `.git` retiré,
contenu vendored tel quel), 251 Mo de cache de build Defold, une vraie clé
privée RSA (`manifest.private.der`), et 9,6 Go de vidéos render exclus du
dépôt (bien trop gros, régénérables).

### 2. Dépôt GitHub renommé
`Fanny_P-tanque_World_Tour` → `Arducible_Fanny_Petanque_World_Tour` (correction
du nom du projet, cohérent avec #ARDUCIBLE partout ailleurs). Fait via un
renommage GitHub classique (historique/stars/issues conservés, redirect
automatique sur les pages du dépôt et les remotes git) plutôt qu'un nouveau
dépôt vide. **Piège** : ce redirect ne couvre PAS GitHub Pages - l'ancienne
URL (`guiraudjb.github.io/Fanny_P-tanque_World_Tour/`) renvoie un 404 pur et
simple. Nouvelle URL : `guiraudjb.github.io/Arducible_Fanny_Petanque_World_Tour/`.
Toutes les références internes (`index.html`, `robots.txt`, `sitemap.xml`,
`README.md`) mises à jour et vérifiées à la fois en local et sur le site
déployé.

### 3. Référencement Google (SEO) de `index.html`
La page n'avait **aucune structure HTML réelle** (pas de `<!doctype>`, `<html>`,
`<head>`, `<body>` - juste des balises nues) ni de `<h1>` nulle part sur toute
la page (tout partait de `<h2>`). Corrigé, plus canonical/Open
Graph/Twitter Card/JSON-LD (`schema.org/VideoGame`), `robots.txt` et
`sitemap.xml` créés (n'existaient pas). Ajout mots-clés multilingues
réfléchis (pas de bourrage) : `alternateName` JSON-LD + une phrase visible
citant les noms locaux vérifiés de la pétanque (Petanque, Petanca,
Petong/เปตอง, петанк - sourcés depuis les recherches déjà faites sur
l'écosystème pétanque, pas inventés). Volontairement **pas** de
`hreflang`/`og:locale:alternate` : la page n'existe qu'en français, en
ajouter aurait été factuellement faux.

### 4. Corrections diverses trouvées en vérifiant le contenu
- 3 mentions "111 pays" oubliées dans `index.html` lors du passage à 115
  (README avait déjà été corrigé une session plus tôt).
- `main.py`/`main_quizz.py` : écran "CHOISIS TON MODE" et bloc "GAME START
  IN" pas alignés sur les positions déjà réajustées dans `main_hardcore.py`
  - synchronisés.
- README enrichi d'un tableau récapitulatif des 4 jeux et d'une section
  "Choix du mode" qui n'était documentée nulle part ; découverte au passage
  que la narration TTS du Quizz (`assets/Sounds/QuizzTTS/`) est bien câblée
  alors que le README affirmait encore "aucun fichier audio".
- PCB détection v3 (ajout d'un connecteur JST-XH) : fichiers de commande
  JLCPCB récupérés depuis `ressources/archives/PCB pour détection/last pcb/`,
  copiés dans `hardware/pcb/`, liés depuis `index.html`/`BOM.md`.

### 5. Vérifications high-score et score Round the Clock
Revérifié (technique headless habituelle, voir plus bas) que
`save_high_score()`/`_hardcore()`/`_quizz()` ne s'exécutent bien qu'une
seule fois par partie pour les 3 jeux à score, et que le score de Round the
Clock (sans persistance, volontairement fidèle à l'original) s'accumule
correctement en session et repart bien à zéro entre deux parties. Aucun bug
trouvé cette fois - juste une re-confirmation après les changements
récents.

### 6. FreeCAD piloté en headless (nouvelle capacité, voir la skill)
Nouveaux rendus 3D (plusieurs angles) de l'articulation complète et de ses
3 plaques (`hardware/renders/articulation/`), et export des **plans cotés**
qui existaient déjà dans les `.FCStd` mais n'avaient jamais été exportés
(`hardware/plans/plaque-{sup,inf,milieu}.pdf`, liés depuis `index.html` et
`BOM.md`). Deux bugs trouvés dans les fichiers CAD sources (pas introduits
cette session) :
- Cartouches copiés-collés sans être renommés : `plaque-inf.FCStd` affichait
  "Plaque supérieure", `plaque-milieu.FCStd` affichait "Plaque inférieure" -
  **corrigés**.
- 3 cotes corrompues sur le plan de `plaque-inf` (2D references corrompues/
  pointant vers une ligne au lieu d'un cercle) - **les 3 corrigées et
  vérifiées** (session suivante) :
  - Diamètre : rattaché au cercle du 4ᵉ trou du losange central, affiche
    Ø4,5 comme les 3 autres trous identiques.
  - Les 2 cotes d'espacement X/Y : une première tentative (référencer les
    arêtes de 2 cercles directement) donnait 7,32 mm pour les deux au lieu
    des 14 mm attendus - en creusant, TechDraw mesure entre le **bord** des
    cercles référencés, pas leurs centres (confirmé par un test sur une
    paire de trous alignés : 28 mm de centre à centre, 23,5 mm mesurés =
    28 − 2×2,25 de rayon). Solution : référencer les **Vertex** du centre de
    chaque cercle plutôt que les Edge du cercle lui-même (chaque cercle a un
    vertex de centre discret dans la vue TechDraw, en plus de son edge de
    circonférence - repéré en comparant aux coordonnées du sketch). Donne
    bien 14 mm pour les deux, confirmé par export.

Toute la démarche (AppImage, Xvfb, piège `freecadcmd` qui corrompt les
fichiers avec pages TechDraw, attente réelle nécessaire après `recompute()`,
addon A2plus...) est documentée dans une skill réutilisable :
`~/.claude/skills/freecad-headless/SKILL.md` (locale à cette machine, à
recréer ailleurs si besoin - son contenu peut servir de base).

## Repères utiles pour la suite

- Numéros de gamestate : `main.py`/`main_hardcore.py` — 0 accueil, 3 choix du
  continent, 4 décompte, 1 partie, 2 fin. `main_quizz.py` — 0 accueil, 4 choix
  du continent, 5 décompte, 3 quizz, 2 fin.
- Technique de test headless utilisée tout du long : lancer une copie du
  script avec `SDL_VIDEODRIVER=dummy`/`SDL_AUDIODRIVER=dummy`, état injecté
  directement dans une copie du fichier (pas le vrai `main*.py`), captures
  via `pygame.image.save()`. Toujours restaurer `config.ini` après (des
  écrans de fin de partie y écrivent le high score).
- Détails complets, choix de conception et justifications : voir la mémoire
  Claude Code (memory) de ce projet - fichiers `project_continent_select_*`,
  `project_neon_glow_replaced`, `project_hud_palette_muted`,
  `project_score_highscore_verification`, `project_hardcore_hud_layout`,
  `project_mediapipe_sensitivity_fix`, `reference_site_and_repo_urls`,
  `reference_freecad_headless_skill`. Ce compte-rendu en est un résumé
  condensé, pensé pour être lisible sans Claude Code (autre poste, autre
  outil).
- Nouvelle URL du dépôt/site : voir section "Dépôt GitHub renommé" plus haut.

## Points de vigilance pour une prochaine session

- `index.html` (page marketing) embarque toujours "Neon Glow" en base64 pour
  le style décoratif des compteurs de stats (typo volontairement différente
  du HUD du jeu, une police vintage néon pour l'affiche) - ce n'est **pas**
  un oubli du remplacement par Alfa Slab One, juste un choix graphique
  distinct pour cette page marketing ; à ne pas "corriger" par réflexe.
- Le correctif de sensibilité MediaPipe (session du 15-16) n'a toujours pas
  été testé avec une vraie caméra sur ce poste - à vérifier en priorité sur
  la borne physique à la reprise.
- L'ancienne URL GitHub Pages (`.../Fanny_P-tanque_World_Tour/`) est morte
  (404 permanent, pas de redirect) - si elle traîne quelque part en externe
  (bio TikTok, post, favori...), il faut la mettre à jour à la main.
- Gros dossiers volontairement non versionnés (voir section "Tout est
  commité et poussé" en haut) - ne pas s'étonner de leur absence après un
  clone frais, ils sont régénérables via `ressources/utils/`.

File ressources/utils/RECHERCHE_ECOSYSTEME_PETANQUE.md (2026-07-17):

# Recherche : écosystème pétanque — influenceurs, sponsors, événementiel, fabricants

Registre de recherches web menées pour cartographier l'écosystème commercial/médiatique autour de la pétanque en France : influenceurs, sponsors/partenaires des instances officielles, sociétés d'événementiel (team building, animations d'entreprise), fabricants de boules de compétition, et fabricants de boules souples/mousse pour le loisir en intérieur. Utile pour d'éventuels partenariats, sponsoring ou opérations de communication autour de Fanny Pétanque World Tour.

Principe : chaque fait doit être vérifiable et sourcé. Recherche menée le 2026-07-15, non exhaustive (écosystème mouvant, vérifier les infos avant tout contact commercial).

---

## Influenceurs pétanque

**Tanguy Penin** — se présente comme "le premier influenceur pétanque au monde", freestyleur et organisateur d'événements. Fait notamment un enchaînement de 19 tirs en une minute, vidéos virales sur TikTok/Instagram (32K abonnés Instagram, revendique 720M+ vues cumulées dans 37 pays) — sources : tanguypenin.fr ; instagram.com/tanguypenin ; actu.orange.fr (portrait "à 21 ans, il cartonne sur TikTok et devient influenceur... pétanque")

**Findly (plateforme d'influence marketing)** — liste 20 comptes Instagram taggés "pétanque" (18,6K à 204,6K abonnés : @florian.bompan, @eskimo.one, @eleonore_lluna, @cedric_schell, @cinqalaventure, @astegiano.remi, @les_compagnons_explorateurs, @voyagesfetiches, @labengale, @florian.roc, @lio_steel_legendary, @decathlon_outdoor, @maxime_lullo, @lemondedechloe.974, @auvergnedamour, @clolenae, @explora_project, @thesunnyblondie, @vert_de_gris, @leroutard). **Mise en garde** : la liste sent le tag automatique peu fiable — plusieurs comptes sont manifestement des influenceurs voyage/lifestyle génériques (@leroutard "le routard" 204K abonnés, @explora_project, @voyagesfetiches, @auvergnedamour = tourisme régional) ou une marque (@decathlon_outdoor), probablement tagués "pétanque" pour une seule story/publication de vacances plutôt que par spécialisation. À vérifier compte par compte avant tout contact — source : findly.co/meilleurs-influenceurs/instagram/petanque

Correction (voir cluster Royal Fodera / Le Roi Solaire ci-dessous, ajouté après une relecture manuelle du 2026-07-15) : **Tanguy Penin est représenté par l'agence Royal Fodera Events**, qui gère aussi l'image de Dylan Rocher — les deux plus gros noms médiatiques de la discipline sont donc liés à la même agence, un point de contact unique potentiellement stratégique.

### Chaînes YouTube pétanque (contenu/enseignement, pas influenceurs individuels au sens réseaux sociaux)
**Petanque Academy** — chaîne pédagogique complète (formations en ligne payantes aussi via petanqueacademy.fr), stages officiels filmés — source : youtube.com/@petanqueacademy

**Petanque Coach** — par un coach à 42 ans d'expérience compétitive (prénom Kevin), conseils technique/stratégie — source : youtube.com/@PetanqueCoach

**Horizon Pétanque** — émissions, compétitions, championnats, contenu régulier façon "magazine" — source : youtube.com/@horizonpetanque

**FF Pétanque et Jeu Provençal (FFPJP officiel)** — chaîne institutionnelle de la fédération, retransmissions en direct — source : youtube.com/@ffpjpofficiel

**PPF Pétanque** — chaîne officielle du circuit Passion Pétanque Française (cf. cluster ci-dessous) — source : youtube.com/channel/UCyQAL0ZOE9YLXfkndhlgJMQ

Nombres d'abonnés non trouvés via recherche (nécessite de visiter chaque chaîne directement pour un chiffre à jour).

### Autres figures/comptes notables (TikTok)
**Génézio Hoarau ("Hoarau Pétanque")** — triple champion du monde de pétanque en fauteuil électrique (pétanque assise) en 2017, 2018 et 2022, présent sur TikTok. Angle intéressant pour Fanny World Tour : représentation du handisport, sous-exploré dans le reste de cette recherche — source : recherche TikTok "Hoarau Petanque"

**Atelier Pétanque** (@atelierpetanque.familly) — compte familial actif sur TikTok (entraînement au tir pour débutants, souvenirs d'événements 2023) et sur Facebook (facebook.com/atelierpetanque). Profil plus modeste que Tanguy Penin mais contenu régulier et pédagogique — sources : tiktok.com/@atelierpetanque.familly ; facebook.com/atelierpetanque

**Autres comptes TikTok pétanque repérés** (audience/activité non qualifiées, à explorer si besoin d'une liste plus large) : @live.ptanque ("Live pétanque"), @petanquefans, @rachid.petanque (contenu compétition, ex. "Philippe Suchaud"), @kadour.petanque (contenu ciblant explicitement le public maghrébin : Maroc/Algérie/Tunisie, hashtag #creatorsearchinsights) — piste intéressante si Fanny World Tour vise une audience nord-africaine, cohérent avec les pays du tour (Algérie, Tunisie déjà dans `Scripts/dialogues.py`).

### Notre propre compte : @arducible (TikTok)
**Ce projet a déjà une présence active sur TikTok sous `#arducible`**, compte `@arducible` : au moins 2 vidéos repérées, dont "je construis un jeu de pétanque électromécanique, un stand de tir pour défier tes amis" (hashtags multilingues #pétanque #เปตอง #bocce #петанк #petanca #bocceball #boccia — ciblage clairement international/multi-marché) et une vidéo taguée **#alcomm** (la marque de boules souples Al'Comm déjà identifiée plus haut dans ce document — contact ou usage produit déjà établi ?). Impossible d'extraire abonnés/nombre total de vidéos via recherche (TikTok bloque le scraping simple) — à vérifier en se connectant directement sur le compte — sources : tiktok.com/@arducible/video/7479818387380522262 ; tiktok.com/@arducible/video/7476149384380665110 ; create.arduino.cc/projecthub/guiraudjb/arducible-a4a337 (projet Arduino Hub associé)

---

## Cluster Royal Fodera Events / Le Roi Solaire / PPF

Ensemble d'acteurs liés entre eux, découvert après une recherche manuelle ciblée (absent des recherches génériques précédentes) — regroupe à lui seul de l'événementiel, du sponsoring et des influenceurs, donc probablement le point d'entrée le plus stratégique de tout l'écosystème pour Fanny World Tour.

**Royal Fodera Events** — agence événementielle haut de gamme spécialisée pétanque ("création d'expériences uniques et fédératrices autour de la pétanque"), conçoit/produit des événements sur-mesure pour entreprises, institutions, collectivités et marques. Gère notamment l'image de **Tanguy Penin** (freestyleur/influenceur) et travaille avec **Dylan Rocher** (meilleur joueur mondial actuel, cf. `RECHERCHE_ATHLETES_PETANQUE.md`) comme ambassadeur. Existence légale vérifiée : SAS, SIREN 921 086 955, créée le 20/10/2022, siège 70 Impasse de la Zone Artisanale, 26790 Suze-la-Rousse (Drôme), code NAF 82.30Z — sources : royalfodera.com ; annuaire-entreprises.data.gouv.fr/entreprise/royal-fodera-events-921086955

**Le Roi Solaire** — entreprise familiale de panneaux photovoltaïques/énergies renouvelables, basée elle aussi à Suze-la-Rousse (Drôme) — même commune que Royal Fodera Events, +50 salariés, 6 agences dans le Sud-Est. Entrée remarquée dans la pétanque : a d'abord sponsorisé Dylan Rocher (invité au 1er Trophée des Célébrités en 2021), puis est devenu **sponsor titre du circuit Passion Pétanque Française (PPF)** et partenaire des Championnats du Monde (Dijon 2024). Dirigeant : **Damien Fodera**, qui a pris la tête de l'association du circuit PPF en février 2024 — le nom "Fodera" reliant directement Le Roi Solaire à Royal Fodera Events (probablement la même famille/groupe) — sources : leroisolaire.fr/Actualites/petanque ; leroisolaire.fr/notre-histoire ; sportmag.fr/le-roi-solaire-met-la-petanque-en-lumiere ; sportmag.fr/petanque-le-roi-solaire-et-ppf-main-dans-la-main ; petanque-dijon2024.fr/le-roi-solaire-devient-partenaire-des-championnats-du-monde ; linkedin.com/in/damien-fodera-17a6a917b

**Passion Pétanque Française (PPF)** — circuit national créé en 2013 à Draguignan, aujourd'hui un rendez-vous incontournable reconnu internationalement : 17 étapes masculines, 12 féminines, 9 vétérans en 2026, de mai à novembre partout en France, culminant à la Grande Finale (48 meilleurs joueurs de l'année, ouverte aux femmes depuis 2017). Structuré en association (PASSION PETANQUE FRANÇAISE, statut loi 1901 via HelloAsso) — sources : petanquefrancaise.com/a-propos-de-ppf ; sportmag.fr/petanque-17-villes-au-menu-le-circuit-ppf-2026-fait-son-tour-de-france ; helloasso.com/associations/passion-petanque-francaise-p-p-f

**Piste à explorer** : Royal Fodera Events (agence) + Le Roi Solaire (sponsor/famille Fodera) + PPF (circuit) forment un pôle unique très actif et médiatisé — un contact avec Royal Fodera Events pourrait potentiellement ouvrir sur l'ensemble du cluster (influenceurs, sponsor, circuit officiel) en un seul point d'entrée.

---

## Sponsors / partenaires officiels

### FFPJP (Fédération Française de Pétanque et Jeu Provençal)
- **OBUT** — partenaire historique, 1er fabricant de boules, associé à tous les événements fédéraux (Championnats de France, Coupe de France, Pétanque Tour) et aux tenues des Équipes de France.
- **MMA** — assureur officiel de la FFPJP (partenariat historique, couverture de 310 000 licenciés), lié jusqu'à fin 2025.
- **ELDERA** — équipementier officiel des Équipes de France et de la FFPJP pour les saisons 2025 à 2028.
- **Crédit Mutuel** — partenaire bancaire de la FFPJP.
- **MS Pétanque** — fabricant 100% français, partenaire officiel de la FFPJP (annoncé partenaire 2026).
- **King Matériaux** — partenaire officiel FFPJP et Équipe de France, fournisseur de sable pour terrains de pétanque.
- sources : home.ffpjp.org/partenariats/nos-partenaires ; home.ffpjp.org (article "MS Pétanque partenaire 2026") ; facileacomprendre.fr/zoom-sur-les-partenaires-de-la-ffpjp

### Mondial la Marseillaise à pétanque (65e édition)
- **TGV INOUI** — transporteur officiel (liaison directe Marseille depuis 43 gares France/Europe).
- Autres partenaires cités : CPMM, Colas, Villa M, Rent a Car, Tesla, Azur et Constructions, Groupe Pernod Ricard France.
- source : mondiallamarseillaiseapetanque.com/partenaires

### Contexte marché
Un article franceinfo souligne que **la pétanque manque de sponsors** malgré un fort nombre de licenciés et une reconnaissance croissante — signal que le secteur est probablement plus ouvert/accessible à de nouveaux partenariats que des sports plus saturés en sponsoring — source : franceinfo.fr/sports/petanque/la-petanque-fait-le-plein-de-licencies-et-de-reconnaissance-mais-manque-de-sponsors

---

## Sociétés d'événementiel / team building pétanque

**Les PétanCœurs** — anime événements d'entreprise (team building, séminaires, soirées, salons pro) avec terrains éphémères et animateurs professionnels partout en France, y compris déclinaisons locales (ex. Lille) — source : lespetancoeurs.fr

**Autour d'un But** — animations team building pétanque en indoor ou outdoor via boulodromes éphémères, intervient à Lyon, Paris, Marseille, Cannes — source : autourdunbut.com

**TREIZECINQ** — animation pétanque entreprise clé en main, intervient partout en France — source : treizeetcinq.com/petanque

**La Pause Pétanque** — basée en Nouvelle-Aquitaine à l'origine, sollicitée dans toute la France et jusqu'en Espagne — source : lapause-petanque.fr

**Creashow** — location de terrain de pétanque événementiel sur Paris — source : animation-evenement-entreprise.fr/projet/location-terrain-petanque

**Madiba** — propose l'activité incentive "apéro pétanque" — source : madiba.fr/activite-incentive-196-Apero-Petanque

**Locarcade** — article/prestataire sur l'activité pétanque en team building — source : locarcade.fr/articles/activite-petanque-team-building

**Sportcom Consulting** — créateur d'événements pétanque ET rugby pour entreprises/CE, fondée par 3 passionnés (Rémy Galleau, Thierry Louvet, Aubin Hueber), basée à Toulon (83000). Existence légale vérifiée à l'Annuaire officiel des entreprises (SIREN 881011522) — sources : sportcom-consulting.com ; annuaire-entreprises.data.gouv.fr/entreprise/sportcom-consulting-881011522

**Envol** — location de terrain de pétanque éphémère, montage/démontage par équipe dédiée — source : envol-fr.com/catalogue-envol/animation-petanque

**Comptoir du Mobilier** — location de boulodrome mobile (davantage location de mobilier événementiel généraliste que spécialiste pétanque) — source : comptoirdumobilier.fr/product/terrain-de-petanque

**Boogle** — location de terrain de pétanque (Belgique) — source : boogle.eu/location

**La Boulisterie** — location de terrain de pétanque longue — source : laboulisterie.com/location-terrain-de-petanque-longue

**Boutae Events** — pétanque éphémère en Haute-Savoie (74), positionnement régional — source : boutaeevents.fr/fr/petanque-mobile

**KV Events** (Lyon) — location de matériel événementiel généraliste, cité en lien avec les recherches boulodrome mobile mais spécialisation pétanque non confirmée — source : kvevents.fr

Argument commercial récurrent chez ces prestataires : la pétanque est accessible à tous niveaux/âges/conditions physiques, et un terrain éphémère s'adapte à de nombreux lieux (intérieur, terrasses, rooftops, cours d'hôtel particulier) — utile pour un angle de pitch si Fanny World Tour approche ces sociétés.

### Couverture géographique (recherche croisée par ville)
**Les PétanCœurs** — spécialiste communication événementielle pétanque depuis 2017 pour de grandes marques françaises, présent à Paris, Lyon, Marseille, Bordeaux, Lille, Strasbourg, Nantes, Toulouse — sources : lespetancoeurs.fr/page/animation-petanque-bordeaux ; jai-un-pote-dans-la.com/petanque-outil-marketing-evenements-les-petancoeurs

**Autour d'un But** — antennes à Paris, Lyon, Bordeaux, Toulouse, Marseille — source : autourdunbut.com

**TREIZECINQ** — intervient partout en France et jusqu'au Maroc — source : treizeetcinq.com/petanque

**La Pause Pétanque** — basée à Saint-Vincent-de-Tyrosse, active sur Bordeaux/Mérignac/Pessac/Arcachon et au-delà — source : lapause-petanque.fr

### Outils de recherche annuaire officiels (pour vérifications futures)
**annuaire-entreprises.data.gouv.fr** — annuaire officiel gratuit (données Sirene/INPI), permet de vérifier l'existence légale, le SIREN et l'activité (code NAF) de toute entreprise française avant contact commercial. Codes NAF pertinents identifiés : **82.30Z** (organisation de foires, salons professionnels et congrès — inclut agences événementielles) et **93.29Z** (autres activités récréatives et de loisirs — inclut animation d'événements culturels/festifs) — sources : annuaire-entreprises.data.gouv.fr ; sidecare.com/code-ape-naf/9329z-autres-activites-recreatives-et-de-loisirs ; pole-autoentrepreneur.com/liste-code-ape/activite/evenementiel

**societe.com** / **Kompass** / **Infogreffe** — annuaires professionnels complémentaires (RCS, Kbis, bilans) utiles pour qualifier un prospect avant approche commerciale — sources : societe.com ; fr.kompass.com ; infogreffe.fr

---

## Fabricants de boules de compétition

**Obut** — leader du marché (~80% de part de marché sur les boules de compétition), fondé en 1955 à Saint-Bonnet-le-Château (Loire), gamme la plus complète du marché — sources : universpetanque.com/blogs/infos/obut-et-ms-petanque-2-fabricants-francais-de-boules-de-petanque ; gazette-petanque.com/zoom-sur-les-marques-de-boules-de-petanque

**La Boule Bleue** — créée en 1903 à Marseille (berceau de la pétanque), doyenne des marques (100+ ans), boules en acier inoxydable ou carbone toujours fabriquées à Marseille — source : laboulebleue.fr

**MS Pétanque** — créée en 1995 (à l'origine "VMS Plot") par MM. Marles, Henri Salvador (le chanteur) et Vartan Barberian ; seule marque utilisant un procédé de fabrication par forgeage ; 100% fabriqué en France ; partenaire officiel FFPJP 2026 — sources : ms-petanque.com ; universpetanque.com (article cité ci-dessus)

**JB Pétanque** — longtemps principal concurrent d'Obut, également basé à Saint-Bonnet-le-Château — source : boulipedia.com/marque (recherche croisée)

**Géologic** — marque Decathlon créée en 2008, boules fabriquées en Thaïlande, gamme grand public/loisir-compétition via Decathlon — sources : synonyme-du-mot.com/les-articles/qui-fabrique-les-boules-de-petanque-geologic ; decathlon.fr/tous-les-sports/petanque/boules-de-petanque-geologic

**Boulenciel** — marque née en 2008 près de Turin (Italie), pionnière des boules de pétanque colorées homologuées compétition, précision d'équilibrage revendiquée ≤0,1% du poids de la boule — source : boulipedia.com/marque/boulenciel

Autres marques citées en recherche croisée mais non détaillées ici : Okaro, JOKO — à creuser si besoin (source générale : petanquestock.com, revendeur multimarques).

---

## Fabricants de boules souples / mousse pour loisir en intérieur

**Bon Tir** — 10 ans de R&D pour reproduire les caractéristiques d'une boule classique (diamètre et poids moyens équivalents) en version souple — source : petanqueshop.com (page produit Bon Tir)

**Al'Comm** — jeu de pétanque souple développé sur 10 ans par Jean-Pierre Albertini (Carpentras), adapté à tous types de sols — source : alcommpetanque.fr

**La Schmolle** — boules de pétanque molles fabriquées en France, positionnement "jouer à la pétanque toute l'année" (usage intérieur) — source : laschmolle.com

**Les PétanCœurs Store** — vend aussi des boules souples en marque propre (pack de 6), probablement du marquage/revente plutôt que fabrication — source : lespetancoeurs.store/product-page/6-boules-souples

Caractéristiques générales du segment : intérieur PVC amortissant les chocs, pas de traces d'impact sur mobilier, certains modèles en mousse ou tissu rempli de granulés pour un usage enfant sans risque de casse — pertinent pour un futur produit dérivé "boules souples Fanny World Tour" si envisagé — source : petanquestock.com/76-boules-de-petanque-d-interieur-et-souple-molle-jeu-de-boule-plastique ; agoralude.com/125-boules-de-petanque-d-interieur

---

## Asie — approfondissement réseaux sociaux (2026-07-15)

La pétanque est massivement implantée en Asie du Sud-Est (héritage colonial français), au point d'être un sport populaire à part entière dans plusieurs pays du tour (`Scripts/dialogues.py`) — angle stratégique fort pour Fanny World Tour au-delà de la seule France. Aucun contact pris, recherche seulement.

### Instance régionale officielle
**Asian Petanque and Sports Boules Confederation (APSBC / ABSC)** — fondée en 1997, 10 pays membres fondateurs : Cambodge, Israël, Japon, Laos, Malaisie, Maurice, Seychelles, Singapour, Thaïlande, Vietnam (la plupart déjà présents dans le tour). Reconnue par l'Olympic Council of Asia (OCA). Page Facebook "Asian Boules Sport Confederation" (~3 864 mentions J'aime), site officiel asianboulessport.org — sources : ocasia.org/sports/federations/94-asian-petanque-and-sports-boules-confederation.html ; facebook.com/AsianBoulesSportConfederation ; asianboulessport.org

### Thaïlande
Décrite comme **"l'un des plus grands pays de pétanque au monde"**. Événement majeur à venir : la **52e édition du Championnat du Monde de pétanque (triplette hommes)** se tiendra à **Khon Kaen, Thaïlande, du 20 au 25 novembre 2026**, organisée par l'Université de Khon Kaen — site officiel kkupetanqueworld2026.com, page Facebook "KKU2026.Pétanque World Championship" — sources : kkupetanqueworld2026.com ; facebook.com/KKU2026PetanqueWorldChampionship ; siambeyond.com/petanque-en-thailande-pourquoi-le-mondial-2026-en-novembre-est-un-evenement-a-ne-pas-rater

Comptes TikTok thaïlandais repérés (niche, non qualifiés en audience) : @marathonpetanqueofficial, @patanque8 ("PETANQUE CHRRT THAI"), @thanpicha.choowong — contenu autour du hashtag #เปตองไทย ("pétanque thaïlandaise") et de l'équipe nationale #เปตองทีมชาติ — source : recherche TikTok croisée "เปตอง"

**Piste calendrier** : le Mondial de novembre 2026 à Khon Kaen est probablement le meilleur point d'ancrage temporel pour toute opération de communication Fanny World Tour ciblant l'Asie (couverture médiatique garantie sur la période).

### Cambodge
Le Cambodge est une **véritable puissance mondiale de la pétanque** : près de 400 médailles internationales au compteur. Fédération officielle **FBPC (Fédération de Boules et de Pétanque du Cambodge)**, créée en 1992, reconnue FIPJP en 1993, membre fondateur de l'APSBC (1997), basée à Phnom Penh. Plusieurs pages Facebook actives : FBPC officielle (facebook.com/Campetanque), "Pétanque Cambodia" (facebook.com/petanque.cam), "Global Petanque Cambodia" (facebook.com/cambodiapetanqueclub) — sources : cambodiasportsreview.com/global-petanque-powerhouse ; phnompenhpost.com/post-in-depth/fbpc-revitalising-boules-and-petanque ; facebook.com/Campetanque

### Laos
La pétanque (localement **"Petong"**) est l'un des sports les plus populaires du Laos, avec un terrain devant quasiment chaque école/bâtiment public — source : aseantourism.travel/petong-sports-heritage-in-laos ; en.wikipedia.org (article Pétanque, section pays francophones/ex-coloniaux)

### Vietnam
Présence confirmée comme membre fondateur de l'APSBC (1997) ; pas de compte social media dédié identifié lors de cette recherche — **AUCUNE INFORMATION SUPPLÉMENTAIRE TROUVÉE** au-delà de l'appartenance à la confédération régionale.

### Tanguy Penin déjà actif en Asie
Confirmation que **Tanguy Penin (cf. cluster Royal Fodera Events plus haut) tourne déjà en Asie** : reportage "Tanguy Penin à Hong Kong : je fais rayonner la pétanque dans le monde". Chiffres d'audience trouvés dans cette recherche complémentaire : jusqu'à 400M de vues cumulées et ~300K abonnés tous réseaux confondus (TikTok/Facebook/Instagram) selon millavois.com — légèrement différent des chiffres trouvés précédemment (720M+ vues/37 pays selon tanguypenin.fr, 32K abonnés Instagram seuls) : sources non alignées entre elles, chiffres à re-vérifier directement auprès de l'intéressé/agence avant tout usage commercial — sources : lepetitjournal.com/hong-kong/tanguy-penin-hong-kong-je-fais-rayonner-la-petanque-dans-le-monde-434195 ; millavois.com/2021/07/29/tanguy-penin-linfluenceur-petanque-le-plus-connu-au-monde

**Piste à explorer** : Tanguy Penin/Royal Fodera Events ayant déjà une stratégie de tournée en Asie, un contact avec cette agence (déjà identifiée comme point d'entrée stratégique) pourrait aussi couvrir l'angle Asie du projet, plutôt que de démarcher séparément chaque pays.

---

## Océanie — approfondissement réseaux sociaux (2026-07-15)

Aucun contact pris, recherche seulement. Les pays du tour en Océanie (Australie, Nouvelle-Calédonie, Nouvelle-Zélande, Tahiti, Vanuatu, Wallis-et-Futuna) correspondent quasi exactement aux membres de la confédération régionale ci-dessous — bon signe de cohérence pour une éventuelle opération ciblée sur cette zone.

### Instance régionale officielle
**Confédération de Pétanque de l'Océanie (CPO)** — regroupe Australie (PFA), Nouvelle-Calédonie, Nouvelle-Zélande, Polynésie (Tahiti & Îles) et Wallis-et-Futuna. Site oceaniapetanque.com — source : oceaniapetanque.com/index.php/fr/membres/federation-de-la-polynesie-tahiti-iles

### Tahiti / Polynésie française
**Fédération Polynésienne de Pétanque** — membre FIPJP depuis 2004, **2 181 licenciés** (1 067 à Tahiti répartis sur 13 clubs + 1 114 dans 38 autres clubs des îles) — chiffres qui en font une des fédérations les plus actives de toute la zone Pacifique rapporté à la population. Page Facebook active, rattachée au Comité Olympique de Polynésie Française (COPF) — sources : copf-tahiti.com/federations-3/petanque ; facebook.com/p/Fédération-Polynésienne-de-Pétanque-100068697894059 ; fipjp.org/images/pdf/nations/tahiti.pdf

### Nouvelle-Calédonie
**Ligue Calédonienne de Pétanque et de Jeu Provençal** — organise la discipline sur tout le territoire selon les règles FFPJP ; existe aussi un **Comité de Pétanque de la Province des Îles Loyauté** dédié à la détection/formation des jeunes licenciés. Un article de La 1ère (France Info Nouvelle-Calédonie) évoque les ambitions calédoniennes pour les "Océanias" (jeux régionaux) — sources : assoce.fr/departement/988/NOUVELLE-CALEDONIE/categorie/11035 ; la1ere.franceinfo.fr/nouvellecaledonie/province-sud/mont-dore/petanque-les-oceanias-dans-le-viseur-des-boulistes-caledoniens-1608414.html

### Wallis-et-Futuna
**Ligue de pétanque de Wallis-et-Futuna** (aussi référencée comme "Comité de pétanque du département Wallis et Futuna") — promeut la pétanque et le jeu provençal sur le territoire selon les règles FFPJP — source : petanque-generation.fr/club/comite-petanque-departement/986

### Vanuatu
**Fédération de Pétanque du Vanuatu** — présidée par **M. Jerry Moli**, basée à Port-Vila — source : fipjp.org/images/pdf/nations/vanuatu.pdf (fiche officielle FIPJP)

### Australie
**Petanque Australia** — organisme national reconnu par l'Australian Sports Commission, page Facebook "Petanque Australia" (1 600+ abonnés) — sources : petanqueaustralia.org.au ; facebook.com/PetanqueAustralia ; asf.org.au/campaigns/petanque-federation-australia

### Nouvelle-Zélande
**Petanque New Zealand (PNZ)** — site petanque.nz, page Facebook dédiée — source : facebook.com/PetanqueNZ ; petanque.nz

**AUCUNE INFORMATION TROUVÉE** sur des comptes TikTok/Instagram dédiés (influenceurs individuels) pour la zone Océanie lors de cette recherche — présence essentiellement institutionnelle (fédérations sur Facebook), contrairement à l'Asie où quelques comptes TikTok niche existent déjà.

---

## Amériques — approfondissement réseaux sociaux (2026-07-15)

Aucun contact pris, recherche seulement.

### Instance régionale officielle
**Pan American Confederation of Pétanque (Pan-Am Petanque)** — couvre Argentine, Brésil, Bolivie, Canada, Colombie, Chili, États-Unis, Haïti, Mexique, Paraguay, Pérou, République Dominicaine, Uruguay, Venezuela. **Correspondance quasi parfaite avec la liste des pays "Amériques" du tour** (`Scripts/dialogues.py`) à l'exception du Costa Rica et du Guatemala, non listés comme membres trouvés. Chaque pays membre a une page dédiée sur le site avec liens vers site web national et réseaux sociaux — sources : panampetanque.org ; panampetanque.org/mexico.html ; panampetanque.org/canada.html

### États-Unis
**FPUSA (Federation of Petanque USA)** — organisme à but non lucratif, **plus de 50 clubs** (~56), environ **2 100 membres** à travers le pays. Présence sociale : Facebook "FPUSA Federation of Petanque USA" (3 404 mentions J'aime), compte Instagram **@petanqueamerica** (517 abonnés) — pas de compte TikTok dédié trouvé — sources : usapetanque.org/about-us.html ; facebook.com/FPUSA.Official ; instagram.com/petanqueamerica

### Canada / Québec
**Pétanque Canada** et **Fédération de Pétanque du Québec** — organismes à but non lucratif dédiés à la promotion/organisation de la pétanque. La communauté la plus forte est à **Montréal/Québec**, portée par l'héritage culturel francophone. Présence Facebook : "Pétanque Canada" (4 593 mentions J'aime), "Pétanque Québec" (2 036 mentions J'aime) — sources : petanquecanada.ca ; petanque.qc.ca ; facebook.com/p/Pétanque-Canada-100021537022585 ; facebook.com/p/Pétanque-Québec-100063767314806

Plus de 100 clubs/terrains ouverts recensés à travers les États-Unis, le Canada et le Mexique combinés — source : petanquecentral.com

### Mexique / Argentine / autres pays d'Amérique du Sud
**AUCUNE INFORMATION DÉTAILLÉE TROUVÉE** sur des comptes réseaux sociaux nationaux spécifiques pour le Mexique ou l'Argentine au-delà de leur page dédiée sur le site Pan-Am Petanque (panampetanque.org/mexico.html) — à consulter directement pour les liens sociaux à jour si besoin d'aller plus loin.

**Constat général zone Amériques** : écosystème très institutionnel (fédérations nationales rattachées à Pan-Am Petanque), aucun influenceur individuel de type Tanguy Penin identifié sur le continent lors de cette recherche — la pétanque y reste une pratique de niche/communauté (souvent liée à l'héritage francophone : Québec, Louisiane potentiellement) plutôt qu'un phénomène médiatique.

---

## Afrique — approfondissement réseaux sociaux (2026-07-15)

Aucun contact pris, recherche seulement. La pétanque est un sport majeur dans plusieurs pays africains du tour, avec un paysage institutionnel plus disputé/politisé qu'ailleurs (à noter avant tout contact officiel).

### Instances régionales officielles — attention, gouvernance disputée
**Confédération Africaine de Pétanque (CAP)**, aussi référencée **CASP (Confédération Africaine du Sport de la Pétanque)** — basée à Rabat, Maroc. Nouveau président élu en mai 2026 lors d'une Assemblée Générale à Abidjan : **Mahmoud Archane**, ex-président de la Fédération Royale Marocaine de Pétanque (FRMP) — sources : facebook.com/p/Confédération-Africaine-de-Pétanque-CAP-100066932258484 ; maroc-hebdo.com/article/mahmoud-archane-elu-president-de-la-confederation-africaine-du-sport-de-la-petanque ; afriquinfos.com/la-federation-panafricaine-de-petanque-bientot-en-afrique-du-nord-avec-un-nouveau-patron

**Point d'attention** : en mai 2019, **15 pays (dont Côte d'Ivoire, Sénégal, Algérie, Mali) ont annoncé la création d'une confédération africaine concurrente**, jugeant la gouvernance de la CASB (l'instance historique) "autoritaire et non-démocratique". La structure panafricaine de la pétanque a donc connu une scission/tentative de dissidence — à vérifier laquelle des instances est aujourd'hui reconnue par la FIPJP avant tout contact officiel — sources : fipjp.org/index.php/fr/8-informations-fr/222-tentative-de-dissidence-en-afrique ; fipjp.org/index.php/fr/federations/confederation-afrique

**10e Championnat d'Afrique de pétanque** — tenu à Nouakchott, Mauritanie, du 22 au 28 novembre 2025, sous l'égide de la FIPJP — source : fipjp.org (10e Championnats d'Afrique 2025)

### Madagascar
Pays présenté comme une véritable **"terre de champions du monde de pétanque"**, en croissance rapide, porté par la qualité de ses artisans bouliers et une communauté passionnée. Fédération officielle : **Fédération Sport Boules Malagasy (FSBM)**, organise les championnats nationaux (triplette, doublette, tête-à-tête) et la Coupe de Madagascar (270 doublettes engagées lors d'une récente édition) — page Facebook active (FSBMalagasy). Existe aussi un site vitrine communautaire, **AS Pétanque Gasy** (as-petanquegasy.com) — sources : midi-madagasikara.mg/madagascar-terre-de-champions-du-monde-de-petanque ; midi-madagasikara.mg/petanque-championnat-de-madagascar-270-doublettes-lancent-la-course-au-titre ; facebook.com/FSBMalagasy ; as-petanquegasy.com

Note de prudence : je n'ai trouvé aucun nom vérifié de champion du monde individuel malgache lors de cette recherche (mes premières pistes de noms se sont révélées être des athlètes d'autres disciplines) — à re-creuser spécifiquement si un ambassadeur malgache est envisagé, plutôt que de supposer un nom.

### Maghreb (Maroc, Algérie, Tunisie)
Les trois pays sont des poids lourds historiques de la pétanque africaine : en 2011, **Algérie et Maroc comptaient chacun plus de 10 000 licenciés**, parmi les plus grosses fédérations au monde. Le **Maroc a été sacré champion d'Afrique** à plusieurs reprises (dont une édition avec l'Algérie sur le podium), et la **Tunisie détient le meilleur palmarès historique** en championnat d'Afrique. Championnat d'Afrique 2025 tenu à Tunis (16-22 juin) avec participation marocaine — sources : franceinfo.fr/monde/afrique/societe-africaine/la-petanque-se-porte-bien-en-afrique ; h24info.ma/petanque-le-maroc-sacre-champion-dafrique ; afrik.com/petanque-le-maroc-champion-d-afrique-l-algerie-sur-le-podium ; faapa.info/blog/le-championnat-dafrique-de-petanque-du-16-au-22-juin-a-tunis-avec-la-participation-du-maroc

### Autres pays du tour actifs en championnat continental
Sénégal, Côte d'Ivoire, Bénin, Mali confirmés comme participants réguliers aux championnats d'Afrique de pétanque (ex. Bénin et Madagascar dans la même poule lors d'une récente édition) — source : fraternitebj.info/sport/article/championnat-d-afrique-de-petanque-6732 ; faapa.info/en/petanque-16-pays-au-championnat-dafrique-a-ouagadougou-pour-le-ticket-du-mondial (16 pays au championnat à Ouagadougou, Burkina Faso)

**AUCUNE INFORMATION TROUVÉE** sur des influenceurs individuels (TikTok/Instagram) dédiés à la pétanque en Afrique lors de cette recherche — comme pour l'Océanie et les Amériques, l'écosystème africain identifié est presque exclusivement institutionnel (fédérations, confédération continentale, championnats), pas média/influence. Le contraste avec l'Asie du Sud-Est (qui a au moins quelques comptes TikTok niche) est net.

---

## Moyen-Orient — approfondissement réseaux sociaux (2026-07-15)

Aucun contact pris, recherche seulement. Zone où la pétanque reste clairement de niche (aucun pays du tour n'y est directement rattaché à l'exception de l'Iran, présent côté Asie dans `Scripts/dialogues.py`), mais quelques structures réelles existent.

**Iran** — **Boules & Pétanque Association of Iran (BPAI)**, basée à Hamedan, membre FIPJP ; opère aussi sous son nom persan (انجمن بولس و پتانك ج.ا.ايران) ; organise les championnats nationaux et sert de centre de détection/développement de talents pour l'Asie centrale et occidentale. Page Facebook active (facebook.com/PETANQUEIRAN) — sources : fipjp.org/images/pdf/nations/iran.pdf ; facebook.com/PETANQUEIRAN

**Liban** — **Fédération Libanaise de Pétanque**, ~400 membres et 11 clubs à travers le pays (Beyrouth, Deir el-Qamar, Aïntoura el-Metn, Beit Chabab, Feytroun, Sin el-Fil, Abbassiyé, Cana, Deir Yahoun) ; joueurs libanais ayant représenté le pays en France, Madagascar, Laos, Bangkok, Tunisie, Turquie, Thaïlande — profil international actif malgré la taille modeste de la fédération — sources : lorientlejour.com/article/1130600/quand-des-ferus-libanais-de-petanque-sillonnent-le-monde ; lfldp.com

**Turquie** — confirmée membre FIPJP, mais **AUCUNE INFORMATION DÉTAILLÉE TROUVÉE** sur une présence réseaux sociaux dédiée lors de cette recherche.

**Israël** — cité comme membre fondateur de l'APSBC (confédération asiatique, cf. section Asie) mais **AUCUNE INFORMATION SUPPLÉMENTAIRE TROUVÉE** sur son écosystème national.

---

## Europe de l'Est — approfondissement réseaux sociaux (2026-07-15)

Aucun contact pris, recherche seulement.

### Instance régionale
**Confédération Européenne de Pétanque (CEP)** — couvre toute l'Europe, page Facebook "Confédération Européenne de Pétanque" et compte Instagram actif (@cep.petanque, section Reels) — sources : facebook.com/EuropeanPetanque ; instagram.com/cep.petanque ; cep-petanque.com

### Roumanie — encore Tanguy Penin
**Fait marquant** : la Roumanie est devenue le **102e pays reconnu par la FIPJP le 13 août 2024**, et **Tanguy Penin (cf. cluster Royal Fodera Events, sections précédentes) a directement contribué à cette reconnaissance officielle** en popularisant le sport via ses réseaux sociaux pendant la période Covid — un article le décrit comme "l'influenceur qui a offert à la pétanque son passeport roumain". Ça confirme, pour la troisième région d'affilée (après la France et l'Asie/Hong Kong), que **Royal Fodera Events/Tanguy Penin est un acteur quasi omniprésent dès qu'un pays développe sa pétanque via les réseaux sociaux** — renforce la piste "point de contact unique" déjà notée. Existe aussi une page Facebook locale "Pétanque Romanaise" — sources : france3-regions.franceinfo.fr/occitanie/aveyron/rodez/de-tiktok-a-bucarest-l-influenceur-qui-a-offert-a-la-petanque-son-passeport-roumain-ma-mission-ici-que-le-sport-soit-enfin-reconnu-3201909.html ; facebook.com/p/Pétanque-Romanaise-100008575637399

### Ukraine — angle humanitaire fort
La pétanque est utilisée en Ukraine comme **outil de rééducation officiellement reconnu par le Ministère de la Santé ukrainien depuis 2023** pour les soldats blessés au combat : sport de précision demandant coordination/concentration sans effort physique intense, adapté aux blessures de guerre, avec un bénéfice psychologique documenté (gestion du traumatisme, cadre social structurant). **Plus de 400 soldats blessés** déjà pris en charge dans **10+ hôpitaux ukrainiens**, objectif d'étendre à 50 établissements supplémentaires d'ici fin 2025. Parrain de l'initiative : **Philippe Quintais** (17 fois champion du monde, déjà documenté dans `RECHERCHE_ATHLETES_PETANQUE.md` pour la France). Financement via collecte FIPJP/HelloAsso reversée à la Fédération Ukrainienne de Pétanque — sources : petanquesanteukraine.com/en ; helloasso.com/associations/federation-internationale-de-petanque-et-de-jeu-provencal/collectes/petanque-sante-ukraine ; sportmag.fr/petanque-la-petanque-au-service-des-soldats-ukrainiens-blesses ; france3-regions.franceinfo.fr/provence-alpes-cote-d-azur/bouches-du-rhone/marseille/la-petanque-m-aide-a-mieux-vivre-avec-mon-corps-mutile-des-soldats-ukrainiens-retrouvent-gout-a-la-vie-grace-aux-boules-3180873.html

**Piste à explorer** : cet angle humanitaire ukrainien est un narratif fort et distinct de tout ce qui a été trouvé jusqu'ici dans cette recherche — pourrait justifier une communication dédiée si Fanny World Tour souhaite s'associer à une cause plutôt qu'à du pur marketing/sponsoring.

**Autres pays d'Europe de l'Est du tour** (Arménie, Bulgarie, Estonie, Hongrie, Lettonie, Lituanie, Pologne, Russie, Serbie, Slovaquie, Slovénie, Tchéquie) — **AUCUNE INFORMATION SPÉCIFIQUE SUPPLÉMENTAIRE TROUVÉE** sur leur présence réseaux sociaux individuelle lors de cette recherche, au-delà de leur rattachement à la CEP (déjà documentée dans `RECHERCHE_ATHLETES_PETANQUE.md` pour les résultats sportifs). À creuser pays par pays si un ciblage précis est envisagé.

---

## Sous-continent indien — approfondissement réseaux sociaux (2026-07-15)

Aucun contact pris, recherche seulement. Couvre Inde, Pakistan, Bangladesh, Népal, Afghanistan (tous dans le tour, `Scripts/dialogues.py`).

### ⚠️ Point critique pour la stratégie TikTok du projet
**TikTok est totalement bloqué en Inde, au Bangladesh et en Afghanistan** (interdiction nationale, pas juste une restriction partielle) — donc le compte `@arducible` (cf. recherche précédente) et toute vidéo TikTok Fanny World Tour **ne peuvent tout simplement pas atteindre ces trois publics**, quel que soit le contenu ou le budget. Le Pakistan, en revanche, a un accès TikTok complet en 2026. À anticiper si une stratégie de diffusion par pays est envisagée un jour : privilégier Instagram/YouTube/Facebook pour cibler l'Inde, le Bangladesh et l'Afghanistan — source : demandsage.com/tiktok-banned-countries

### Inde — Pondichéry, un narratif culturel unique
**Pondichéry (Puducherry)**, ancien comptoir colonial français (17e siècle, rétrocédé à l'Inde en 1954), a conservé la pétanque comme véritable institution locale : **plus de 3 000 joueurs ("boulistes")** répertoriés, des pêcheurs qui se retrouvent chaque soir pour jouer. Le sujet a même fait l'objet d'articles académiques ("négociation postcoloniale des identités nationales et culturelles") décrivant la pétanque comme un cas d'étude d'hybridation culturelle post-coloniale plutôt que d'uniformisation — un narratif nettement plus riche que "juste un sport importé", potentiellement un angle de contenu fort pour l'épisode Inde de Fanny World Tour — sources : journals.openedition.org/gc/1362 ; hal.science/hal-01681876v1 ; franceinfo.fr (reportage "Pondichéry conserve la culture française qui l'a façonnée")

**Petanque India Association (PIA)** — organe dirigeant officiel de la pétanque en Inde, basé à Delhi, affilié à la fois à la WPBF, la FIPJP et l'ABSC (confédération asiatique, cf. section Asie). Présence sociale confirmée : Instagram **@indiapetanque** (582 abonnés), page Facebook, compte X/Twitter — sources : instagram.com/indiapetanque ; facebook.com/indiapetanque ; x.com/indiapetanque

### Pakistan, Bangladesh, Népal, Afghanistan
Les quatre confirmés membres FIPJP via la confédération asiatique, référencée ici sous le nom **CASB (Confédération Asiatique du Sport Boule)** — **attention, acronyme homonyme mais organisation différente** de la CASB africaine ("Confédération Africaine de Bowls Sports") mentionnée dans la section Afrique : deux structures continentales distinctes qui partagent par coïncidence le même sigle, à ne pas confondre. La confédération asiatique (CASB/APSBC/ABSC selon les sources — nommage instable, cf. aussi section Asie) regroupe 26 fédérations au total — source : recherche croisée FIPJP/boule-petanque.fr/petanque.wordpress.com/organizations

**AUCUNE INFORMATION TROUVÉE** sur des comptes réseaux sociaux ou influenceurs dédiés pour le Pakistan, le Bangladesh, le Népal ou l'Afghanistan lors de cette recherche — probablement des fédérations existantes mais peu actives en communication digitale, ou simplement en dessous du seuil de visibilité des moteurs de recherche généralistes.

---

## Europe (pays restants)

Recherche complémentaire couvrant les pays d'Europe occidentale/du nord/du sud du tour non encore traités (France, Roumanie et le reste de l'Europe de l'Est sont déjà couverts ailleurs dans ce document). Aucun contact pris, recherche seulement.

### Allemagne, Autriche, Suisse (zone germanophone)
**Deutscher Pétanque Verband (DPV)** — fédération allemande officielle, site deutscher-petanque-verband.de — source : deutscher-petanque-verband.de

**Österreichischer Pétanque Verband** — fédération autrichienne officielle — source : recherche croisée (nom confirmé, pas de détail social media trouvé)

**Fédération Suisse de Pétanque (FSP)** — fédération suisse officielle. La Suisse est un **membre fondateur de la FIPJP** (fondée à Marseille en 1958 par France, Belgique, Italie, Monaco, Espagne, Suisse et Tunisie) — sources : en.wikipedia.org/wiki/P%C3%A9tanque ; recherche croisée FIPJP

**AUCUNE INFORMATION TROUVÉE** sur des comptes Facebook/Instagram/TikTok dédiés pour ces trois fédérations lors de cette recherche — présence en ligne limitée aux sites web institutionnels.

### Belgique, Pays-Bas, Luxembourg (Benelux)
**Belgique** — membre fondateur de la FIPJP (1958, cf. ci-dessus), fédération belge active en compétition (CEP) mais **AUCUNE INFORMATION SOCIAL MEDIA TROUVÉE** spécifiquement.

**Pays-Bas, Luxembourg** — **AUCUNE INFORMATION TROUVÉE** (ni fédération détaillée, ni réseaux sociaux) lors de cette recherche — à re-creuser avec des requêtes en néerlandais/luxembourgeois si besoin d'aller plus loin.

### Angleterre, Écosse, Pays de Galles, Irlande, Guernesey, Jersey (îles britanniques)
Historiquement structurées sous la **British Pétanque Federation (BPF)**, dissoute en 2004 au profit d'associations nationales séparées (Angleterre, Écosse, Pays de Galles, Irlande) ; le **British Pétanque Umpires Board** a été conservé pour uniformiser la formation des arbitres dans toute la Grande-Bretagne — source : petanque.wordpress.com/organizations

**Pétanque England** — fédération active, page Facebook "@petanqueengland" — source : facebook.com/petanqueengland ; petanque-england.uk

**Jersey Pétanque Association** — organe dirigeant de l'île, page Facebook "@Jsypetanque" — source : facebook.com/Jsypetanque ; petanque.je

**Guernsey Pétanque Club** — existe (référencé via guernseysports.com) mais **AUCUNE PAGE RÉSEAU SOCIAL DÉDIÉE TROUVÉE**.

**Compétition régionale** : le **Home Nations Championship**, tournoi annuel de 2 jours organisé en rotation par l'Angleterre, l'Écosse, le Pays de Galles et Jersey ; Jersey affronte aussi Guernesey chaque année lors de l'"Inter-Insular" — source : petanque-england.uk/home-nations-2023

**Écosse, Pays de Galles, Irlande** — fédérations nationales confirmées existantes (cf. dissolution BPF ci-dessus) mais **AUCUNE INFORMATION SOCIAL MEDIA DÉTAILLÉE TROUVÉE** individuellement.

### Espagne — fédération notablement forte
**Federación Española de Petanca** — basée à Madrid, page Facebook **"@feppetanca" avec plus de 41 000 mentions J'aime** — nettement la présence sociale la plus forte trouvée parmi tous les pays de cette recherche complémentaire, à noter comme point d'intérêt — source : facebook.com/feppetanca ; fipjp.org/images/pdf/nations/spain.pdf

**Piste à explorer** : avec 41K+ abonnés Facebook, la fédération espagnole a un rayonnement disproportionné par rapport aux autres pays européens (hors France) traités ici — potentiel relais de visibilité si un contenu Fanny World Tour Espagne est produit.

### Italie, Monaco, Portugal, Saint-Marin
**Italie** et **Monaco** — membres fondateurs de la FIPJP (1958, cf. ci-dessus) — pas de détail social media trouvé au-delà de cette appartenance historique.

**Portugal** — fédération référencée sur petanque-world.com mais **AUCUNE INFORMATION SOCIAL MEDIA TROUVÉE**.

**Saint-Marin** — **AUCUNE INFORMATION TROUVÉE** (ni fédération détaillée ni réseaux sociaux) lors de cette recherche.

### Danemark, Norvège, Suède, Finlande (zone nordique)
Tous les quatre confirmés comme membres de la **Confédération Européenne de Pétanque (CEP)**, participant à la CEP European Cup au niveau clubs : Meadow PC (Danemark), Groruddalen PK (Norvège), Club la Boule de Trix/Skövde (Suède), Riemukaari Kärkölä (Finlande) — source : cep-petanque.com/eurocup.html ; cep-petanque.com/survey.html

Le **Dansk Petanque Forbund** (fédération danoise) est référencé sur la plateforme petanque.world — source : petanque.world/associations/61b7a87937f3416f147bfab1

**AUCUNE INFORMATION SOCIAL MEDIA DÉDIÉE TROUVÉE** (Facebook/Instagram/TikTok propres à chaque fédération nordique) lors de cette recherche — présence essentiellement au niveau clubs locaux, pas de compte national visible.

### Andorre
**AUCUNE INFORMATION TROUVÉE** — ni fédération nommément identifiée, ni présence réseaux sociaux, lors de cette recherche. Pays le moins documenté de tout ce lot ; à re-creuser en catalan/espagnol si besoin.

**Constat général sur ce lot de pays** : contrairement à la France (écosystème riche : influenceurs, sponsors, cluster Royal Fodera) et à l'Espagne (fédération à forte audience Facebook), la plupart des autres pays d'Europe occidentale/du nord/du sud ont un écosystème pétanque **purement institutionnel et peu visible en ligne** — fédérations existantes mais sans stratégie de communication digitale forte identifiable par recherche généraliste. Cohérent avec le constat déjà fait pour l'Afrique et les Amériques dans ce document.

---

## Asie (pays restants)

Recherche complémentaire pétanque/réseaux sociaux pour les pays d'Asie restants du tour (Thaïlande, Cambodge, Laos, Vietnam déjà couverts ailleurs). Aucun contact pris, recherche seulement.

**Chine** — la pétanque (法式滚球, "boule roulante à la française") s'y développe avec championnats nationaux, universitaires, et une compétition "France Méditerranée Ball Rolling Tour" citée. Aucun compte de fédération/réseau social dédié identifié précisément lors de cette recherche — sources : zh.wikipedia.org/zh-cn/法式滚球 ; baike.baidu.com/item/法式滚球/1785161

**Corée du Sud** — **Korea Boules Sport Federation (KBSF)**, seule organisation coréenne affiliée à la WPBF, la FIPJP et l'ABSC. Chaîne YouTube active, page Facebook "Petanque Korea" (565 mentions J'aime) — sources : youtube.com/channel/UCGjoTv9MtQwfkI4U7fi4WpA ; facebook.com/PetanqueKorea ; petanque-world.com/country/federation/south-korea-kr

**Japon** — **CIEP Japan** fait la promotion de la pétanque pour tous âges/milieux sociaux ; a organisé des stages de formation réunissant des candidats de Chine, Thaïlande, Corée du Sud et Malaisie — angle intéressant de hub régional de formation — source : sites.google.com/view/ciepenglish

**Taïwan** — page Facebook "Pétanque Taiwan" active ; fédération également listée au Comité Olympique de Taïwan (滾球, boules incluant pétanque) — sources : facebook.com/p/Pétanque-Taiwan-100010499347127 ; tpenoc.net/sport/boules-petanque

**Indonésie** — **Indonesia Petanque Federation**, Instagram @pbfopiofficial (1 147 abonnés, 78 publications) — source : instagram.com/pbfopiofficial

**Malaisie** — **Persekutuan Petanque Malaysia (PPM)**, présence double : Instagram @persekutuan_petanque_malaysia (1 405 abonnés, 549 publications) et Facebook (2 318 mentions J'aime) — fédération asiatique la plus active en volume de contenu trouvée dans ce lot — sources : instagram.com/persekutuan_petanque_malaysia ; facebook.com/persekutuanpetanquemalaysia

**Singapour** — **Pétanque Singapore**, Instagram @petanquesg_official, se présente comme "the home of pétanque in Singapore" ; plusieurs clubs actifs sur Facebook dont l'Admiralty Pétanque Club (fondé 2005) ; le sport est aussi référencé sur le portail sportif public ActiveSG — sources : instagram.com/petanquesg_official ; facebook.com/SingaporePetanque ; facebook.com/petanquesingapore ; activesgcircle.gov.sg/learn/petanque

**Philippines** — **Philippine National Petanque Team**, basée à Angeles City, supervisée par la Philippine Lawn Bowls Association Inc., page Facebook active — sources : facebook.com/ThePhilippinePetanque

**Brunei** — fédération de pétanque membre FIPJP depuis 2007. **AUCUNE INFORMATION TROUVÉE** sur une présence réseaux sociaux dédiée — source : petanque.wordpress.com/organizations

**Myanmar** — **Myanmar Petanque Federation**, basée à Yangon, page Facebook active avec du contenu vidéo/Reels — source : facebook.com/MyanmarPetanque

**Kazakhstan, Kirghizistan, Turkménistan, Mongolie** — **AUCUNE INFORMATION TROUVÉE** sur une fédération de pétanque ou une présence réseaux sociaux pour ces quatre pays lors de cette recherche (plusieurs requêtes ciblées, y compris en anglais, n'ont renvoyé que du contenu géographique générique sans rapport). Zone d'ombre complète de l'écosystème pétanque identifié jusqu'ici — à re-tenter avec des termes en langue locale (kazakh/kirghize/turkmène/mongol) si une couverture exhaustive est nécessaire.

**Piste à explorer** : la Malaisie et Singapour ressortent comme les deux fédérations asiatiques (hors Thaïlande/Cambodge déjà documentées) avec la présence réseaux sociaux la plus riche et professionnelle de ce lot — candidats naturels si Fanny World Tour cherche un point d'entrée en Asie du Sud-Est au-delà du cluster Royal Fodera Events déjà identifié.

---

## Afrique (pays restants)

Recherche complémentaire couvrant Cameroun, Comores, Congo, Djibouti, Égypte, Gabon, Guinée, Libye, Mauritanie, Niger, Ouganda, RCA, RDC, Maurice, Seychelles, Tchad, Togo, Zambie (Madagascar, Maroc, Algérie, Tunisie, Sénégal, Côte d'Ivoire, Bénin, Mali déjà couverts). Aucun contact pris.

### Championnats du monde 2023 à Cotonou (Bénin) — plusieurs pays du tour engagés
Les Championnats du Monde de pétanque se sont tenus à **Cotonou (Bénin) du 8 au 17 septembre 2023**. Plusieurs pays du tour y ont aligné des joueurs de bon niveau : **Togo** (8 participants, **médaille de bronze en tir de précision**), Burkina Faso, **Congo**, Côte d'Ivoire, Sénégal cités comme ayant présenté des joueurs de "grande classe" — sources : mondial-petanque-benin.fipjp.com ; boulistenaute.com/les-actualites-de-la-petanque-et-du-monde-bouliste/i/75273258/cotonou-changement-d-ere ; republicoftogo.com/toutes-les-rubriques/sport/le-togo-decroche-le-bronze

### Togo
En plus du bronze mondial 2023 ci-dessus, la pétanque est répertoriée comme discipline officielle au **Comité National Olympique du Togo** (page dédiée) — source : cnodutogo.org/petanque

### Cameroun, Congo, Gabon, Tchad
Les quatre confirmés membres FIPJP via la CASB (Confédération Africaine de Bowls Sports). **AUCUNE page Facebook ou compte réseau social fédéral TROUVÉ** pour ces quatre pays — sources : fipjp.org/index.php/en/federations/africa-confederation ; mbolocameroon.com/2020/12/08/petanque-les-presidents-deroulent

### République Centrafricaine (RCA), République Démocratique du Congo (RDC), Guinée, Niger
**AUCUNE INFORMATION TROUVÉE** sur une fédération nommée, un championnat national ou une présence réseaux sociaux dédiée pour ces quatre pays — RDC et Guinée en particulier ne remontent que des résultats hors-sujet (football). Angle mort de cette recherche plutôt qu'absence de pratique confirmée.

### Égypte, Libye, Mauritanie, Ouganda
Les quatre confirmés membres FIPJP via la CASB parmi les 23 fédérations africaines affiliées. **Libye et Mauritanie faisaient partie des 15 pays ayant initié la confédération dissidente en 2019** (cf. section Afrique principale). La **Mauritanie a accueilli le Championnat d'Afrique de pétanque à Nouakchott en novembre 2025** (déjà documenté plus haut). **AUCUNE page Facebook/réseau social fédéral TROUVÉ** pour les quatre pays — sources : fipjp.org/index.php/fr/federations/confederation-afrique ; rimsport.net/node/5757 ; cafonline.com/fr/a-propos-de-la-caf/associations-membres/mauritania

### Maurice, Seychelles
Déjà identifiés dans la section Asie de ce document comme **membres fondateurs de l'APSBC (1997)**. Une **Fédération de Pétanque de Maurice** existe (calendrier de compétitions actif sur petanque-world.com) mais sans présence réseaux sociaux identifiée — source : petanque-world.com/country/federation/mauritius-mu

### Comores, Djibouti, Zambie
**AUCUNE INFORMATION TROUVÉE** sur une fédération, un championnat national ou une présence réseaux sociaux pour ces trois pays — ni sur FIPJP/CASB, ni via recherche générale. Probable pratique existante mais non documentée en ligne dans les sources indexées.

**Constat global (pays restants)** : confirme le diagnostic de la section Afrique principale — écosystème quasi exclusivement institutionnel quand il existe, **aucun influenceur individuel ni compte réseau social actif trouvé** pour aucun des 18 pays de ce lot. Togo (bronze mondial 2023) et Mauritanie (hôte championnat continental 2025) sont les deux points d'ancrage les plus solides pour un futur contenu ; les 8 autres pays restent des angles morts à re-creuser en langue locale si besoin.

---

## Amériques (pays restants)

Recherche complémentaire couvrant Argentine (approfondi), Bolivie, Chili, Colombie, Costa Rica, Cuba, Équateur, Guatemala, Haïti, Mexique (approfondi), Paraguay, Pérou, République Dominicaine, Uruguay, Venezuela (USA/Canada déjà couverts). Aucun contact pris.

**Correction au constat précédent** — confirmation que le **Costa Rica et le Guatemala sont bien membres du Pan American Confederation of Pétanque** : liste complète = Argentine, Brésil, Bolivie, Canada, Colombie, Chili, Costa Rica, États-Unis, Guatemala, Haïti, Mexique, Paraguay, Pérou, République Dominicaine, Uruguay, Venezuela — sources : panampetanque.org ; new.panampetanque.org

**Mexique** — le pays le plus actif de la zone après USA/Canada. **Federación Mexicana de Petanca** (fedmexpetanca.org), basée à Ensenada (Baja California), Facebook et Instagram @federacionmexicanadepetanca (419 abonnés). 2025 décrite comme année historique : première équipe féminine mexicaine à un Championnat du Monde (Thaïlande), une triplette masculine engagée au Bénin. Au moins **7 clubs actifs rien qu'à Mexico** (Petanca Capital, Club Petanca Roma, Club de Petanca Coyoacán...) ; Club Petanca León Haz Hilo (12 terrains) présenté comme "épicentre de la petanca au Mexique" ; Club Mérida Petanca actif sur Instagram (@club_merida_petanca, 1 106 abonnés) — sources : fedmexpetanca.org ; facebook.com/federacionmexicanadepetanca ; instagram.com/federacionmexicanadepetanca ; instagram.com/club_merida_petanca ; petanquecentral.com/petanque-mexico

**Argentine** — **AUCUNE INFORMATION TROUVÉE** sur une fédération ou un compte social dédié lors de cette recherche (piste "FPPBA" écartée : c'est la Fédération de Pelote basque de la Province de Buenos Aires, sport différent, à ne pas confondre). Confirmée uniquement comme membre du Pan-Am Petanque.

**Chili** — a accueilli un événement panaméricain à **Limache** ; aucun compte social dédié trouvé au-delà de cette mention de tournoi.

**Pérou** — doit accueillir la **classification panaméricaine de double senior en novembre 2026** ; aucun compte social dédié trouvé.

**Bolivie, Colombie, Costa Rica, Cuba, Équateur, Guatemala, Haïti, Paraguay, République Dominicaine, Uruguay, Venezuela** — **AUCUNE INFORMATION TROUVÉE** sur une fédération nationale, un club ou un compte réseaux sociaux dédié pour l'un de ces 11 pays, au-delà de leur appartenance déclarée au Pan-American Confederation of Pétanque (Cuba n'apparaît même pas de façon certaine dans la liste des membres confirmés). Zone la moins documentée socialement de toute la recherche menée sur l'écosystème pétanque.

**Piste à explorer** : le Mexique se distingue nettement du reste de l'Amérique latine (fédération active, plusieurs clubs avec présence Instagram propre) — si Fanny World Tour cherche un point d'entrée en Amérique latine hispanophone, c'est clairement le pays le mieux structuré socialement, loin devant les 13 autres pays du sous-groupe.

---

## Bilan de couverture — les 112 pays du tour

Avec les sections ci-dessus, les 112 pays de `Scripts/dialogues.py` ont maintenant tous été passés en revue au moins une fois (fédération et/ou présence réseaux sociaux recherchées), avec un niveau de détail très inégal selon les pays — certains ont un écosystème riche et sourcé (France, Espagne, Mexique, Malaisie, Singapour, Thaïlande, Madagascar...), d'autres n'ont renvoyé **AUCUNE INFORMATION TROUVÉE** malgré la recherche (à ne pas confondre avec "n'existe pas" : angle mort de recherche généraliste en français/anglais, probablement à re-creuser en langue locale si un pays précis devient prioritaire). Ne pas prendre le silence d'un pays dans ce document comme la preuve qu'aucune communauté pétanque n'y existe.

---

## Pays absents du tour à considérer (2026-07-15)

**MISE À JOUR (2026-07-15, plus tard le même jour) : Brésil, Israël et Liban ont été intégrés au tour** (tiers 112-114 dans `Scripts/dialogues.py`, `COUNTRY_MAX_TIER` passé à 114, 115 pays au total). Contenu quiz complet généré (faits pétanque sourcés, monuments, personnalités) et hymnes ajoutés. **Il manque encore les portraits de Fanny** (`assets/Images/FannyWorldTour/113_bresil.png`, `114_israel.png`, `115_liban.png`) — aucun outil de génération d'image disponible pour Claude dans ce projet, à fournir séparément avant que les jeux de cartes/vidéos sociales/PDF puissent inclure ces 3 pays. Voir aussi le choix éditorial : la question quiz "capitale" est volontairement évitée pour Israël (statut disputé de Jérusalem), remplacée par une question pétanque supplémentaire.

En croisant l'ensemble des recherches ci-dessus avec la liste des 112 pays de `Scripts/dialogues.py`, plusieurs nations avec un véritable écosystème pétanque n'y figurent pas. Liste à garder pour une éventuelle extension du tour ou pour du contenu annexe.

### Oublis nets (vraies nations, absentes, écosystème confirmé)

**Brésil** — absent du tour. Membre confirmé du Pan American Confederation of Pétanque (14 territoires listés dans sa direction, dont le Brésil). Structure nationale propre : **Confederação Brasileira de Bocha e Bolão (CBBB)** et **Liga Brasileira de Zerbin, Petanca e Rafa (LBZP)** — la petanca y est pratiquée comme l'une des trois disciplines de bocha reconnues par le CIO (avec zerbin et rafa). Pays le plus peuplé absent du tour, candidat le plus évident à une extension — sources : panampetanque.org/about-us ; cbbocha.com.br ; cbbochas.com.br ; ludopedio.org.br/arquibancada/petanca-voce-ja-ouviu-falar

**Israël** — absent du tour. Membre fondateur de l'**APSBC** (confédération asiatique, 1997), fédération reconnue au Congrès FIPJP de Rome en 1992. ~500 licenciés (dont 75 femmes, 68 jeunes), 26 clubs répartis en 4 secteurs. Financée en partie par le Ministère des Sports israélien et la société AYLET (financement des sports non-olympiques) ; reconnue "sport de haut niveau" avec suivi médical sportif dédié. Décrite par le Times of Israël comme "un sport populaire en Israël" — sources : fipjp.org/images/pdf/nations/israel.pdf ; fr.timesofisrael.com/la-petanque-un-sport-populaire-en-israel ; educnaute-infos.com/article-la-petanque-en-israel-119151668

**Liban** — absent du tour. Fédération Libanaise de Pétanque, ~400 membres, 11 clubs à travers le pays, joueurs ayant représenté le Liban à l'international (France, Madagascar, Laos, Bangkok, Tunisie, Turquie, Thaïlande) — déjà documenté dans la section Moyen-Orient plus haut.

### Cas à trancher consciemment (pas des nations séparées, mais des scènes notables)

**La Réunion, Martinique, Guadeloupe, Guyane** — départements/régions françaises d'outre-mer, rattachées directement à la FFPJP (pas de fédération nationale séparée, donc pas des "pays" au sens où le tour définit ses entrées). Pourtant, **La Réunion compte à elle seule 3 000 licenciés et 97 clubs** — davantage que plusieurs pays déjà présents dans le tour (ex. Nouvelle-Calédonie) — Martinique (1 350 licenciés/45 clubs), Guadeloupe (700/28 clubs), Guyane (150/6 clubs). Chiffres 2019 FFPJP, tendance à la baisse depuis (Covid, exode des jeunes vers la métropole) — sources : gazette-petanque.com/les-chiffres-de-la-petanque-2019 ; blogpetanque.com/lareunion ; la1ere.franceinfo.fr/guadeloupe/les-boulistes-des-antilles-et-de-la-guyane-renouent-avec-la-competition-1291700.html

Différence de traitement avec la Nouvelle-Calédonie/Tahiti/Wallis-et-Futuna (déjà dans le tour) : ces trois territoires ont chacun leur **propre fédération distincte** (Ligue Calédonienne, Fédération Polynésienne, Ligue de Wallis-et-Futuna), rattachées à la confédération régionale Océanie plutôt qu'à la FFPJP directement — c'est ce qui justifie leur statut de "pays" séparé dans la logique actuelle du tour, alors que La Réunion/Martinique/Guadeloupe/Guyane n'ont pas cette autonomie fédérale. Si le critère venait à changer (poids réel de la pratique plutôt que statut fédéral), La Réunion serait le candidat le plus fort du lot.

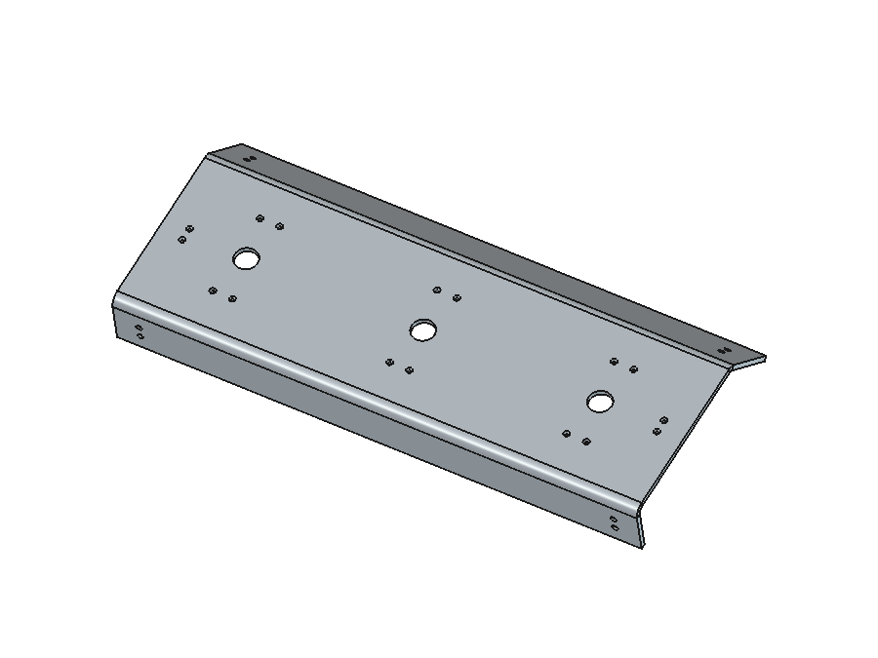
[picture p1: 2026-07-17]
hardware/renders/chassis/plateau-v7.png

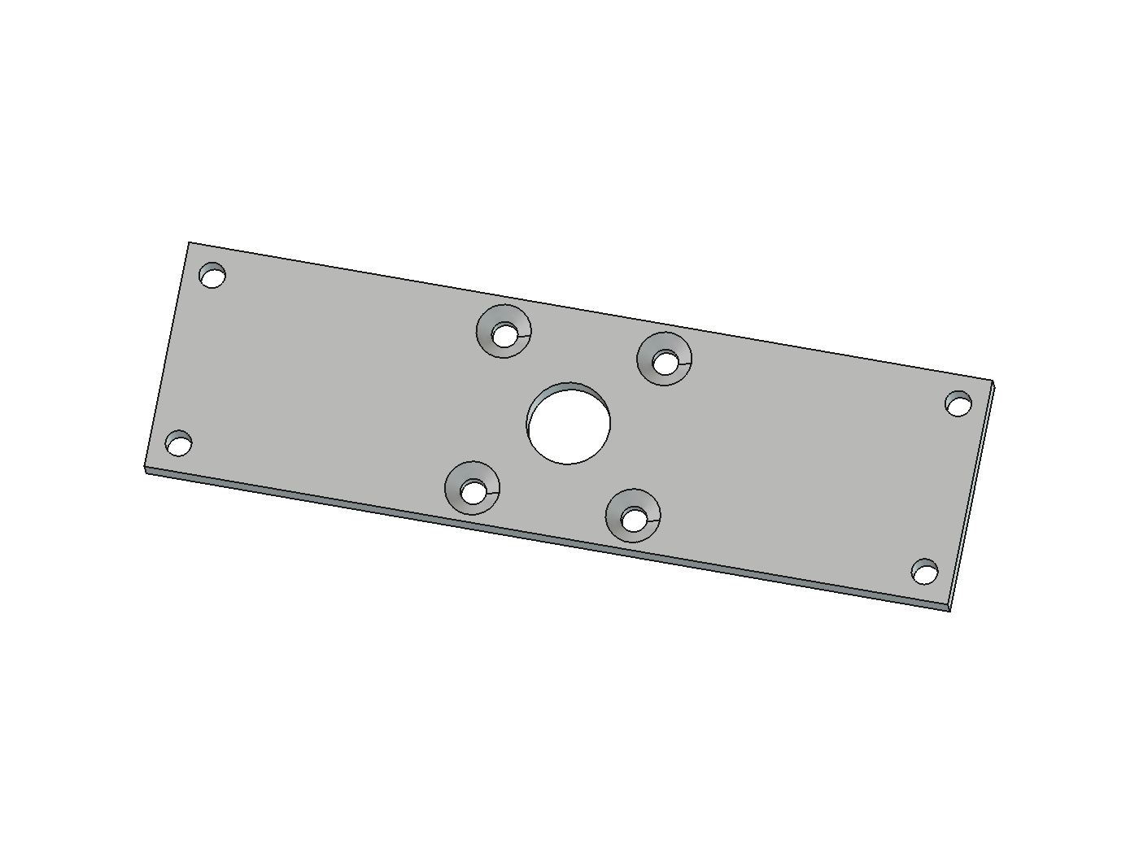
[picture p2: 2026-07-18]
hardware/renders/articulation/vues-supplementaires/plaque-sup-top.png

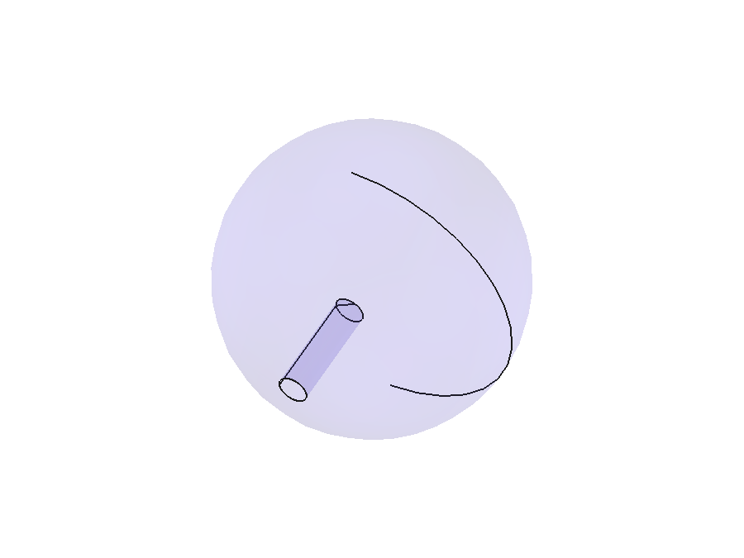
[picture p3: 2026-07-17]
hardware/renders/articulation/boule-petanque-pleine.png

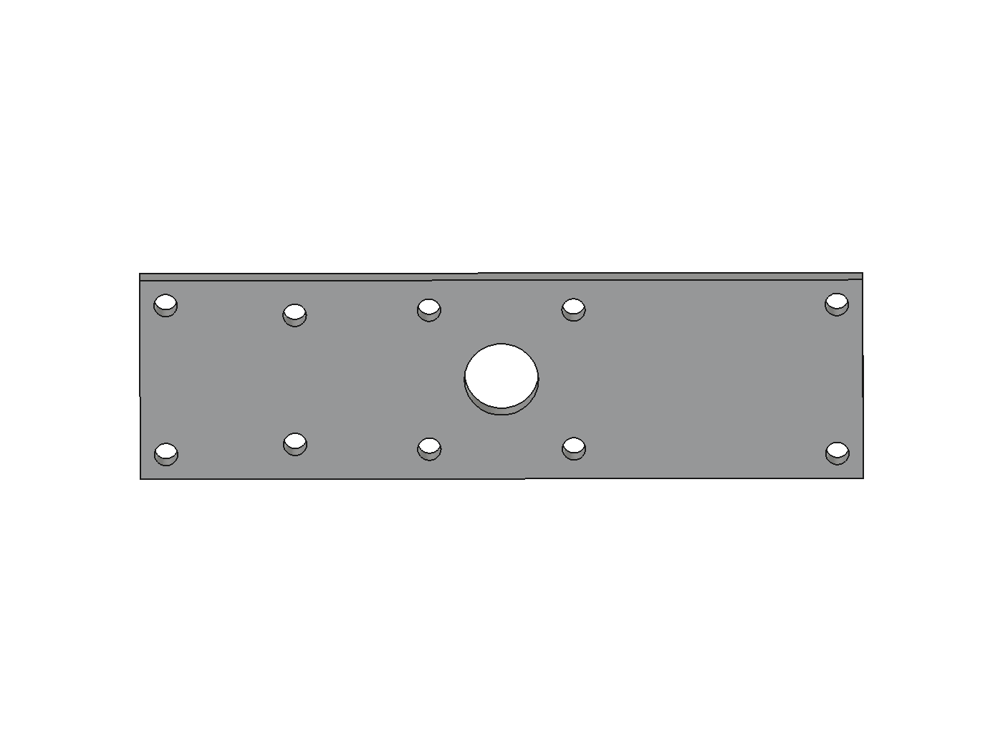
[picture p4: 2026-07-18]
hardware/renders/articulation/vues-supplementaires/plaque-inf-bottom.png

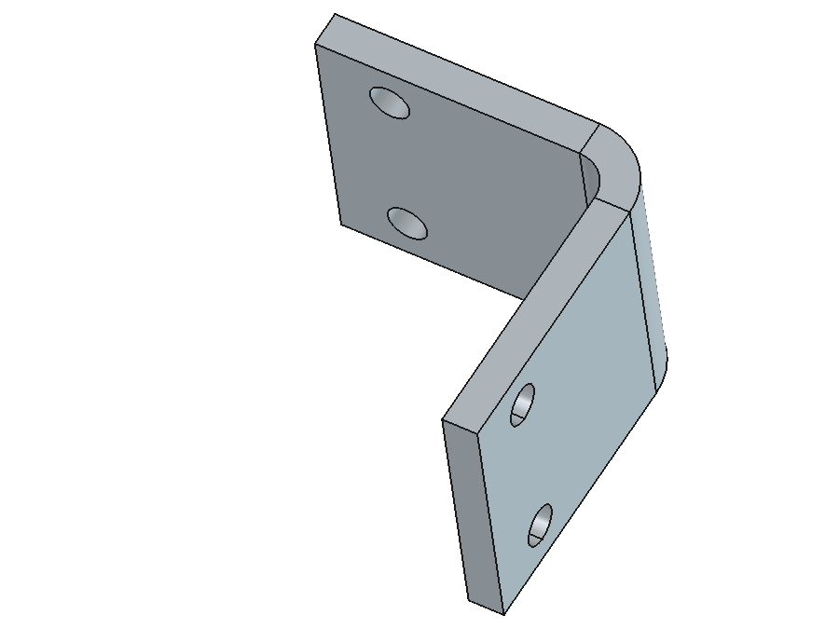
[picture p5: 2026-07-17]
hardware/renders/chassis/equaire-v7.png

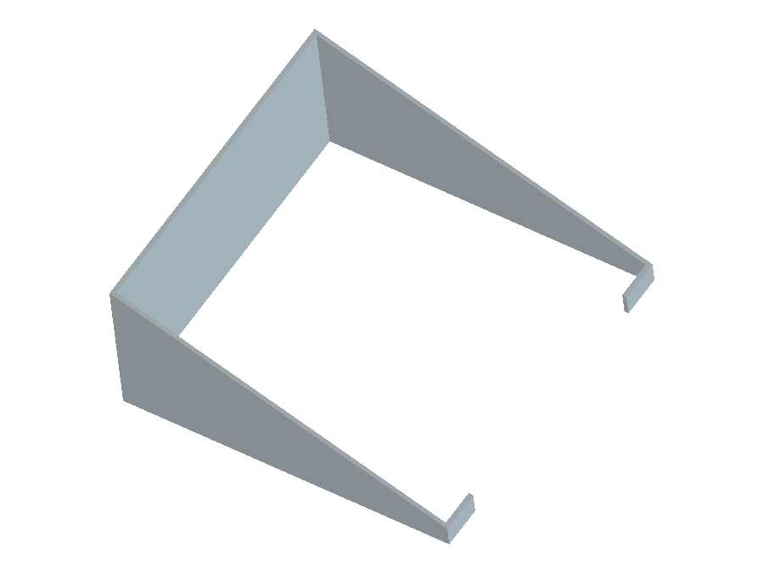
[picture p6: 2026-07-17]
hardware/renders/enclosure/boitier-casquette.png

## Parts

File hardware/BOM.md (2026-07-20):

# Nomenclature (BOM) — Fanny Pétanque World Tour

Borne à 3 cibles physiques. Quantités données **par cible** puis **totales pour
les 3 cibles**, plus les pièces du châssis (non dupliquées) et le contrôleur
central. Les pièces mécaniques et leurs quantités sont extraites directement
de l'assemblage FreeCAD (`ressources/modélisation/Doc final/ChassisV7/`), pas
estimées.

## Électronique — par cible (×3)

| Réf. | Composant | Qté/cible | Qté totale | Fichier |
|---|---|---|---|---|
| U1 | Capteur à effet Hall **OH37** (Nanjing Ouzhuo Tech, SOT-23) | 1 | 3 | [BOM JLCPCB](pcb/bom-jlcpcb-v3.csv) |
| R1 | Résistance **10 kΩ** (CMS 0603) | 1 | 3 | [BOM JLCPCB](pcb/bom-jlcpcb-v3.csv) |
| J1 | Connecteur **JST-XH 3 points** (DATA/-/+, LCSC C2316) | 1 | 3 | [BOM JLCPCB](pcb/bom-jlcpcb-v3.csv) |
| — | PCB détection v3 (Gerber `arduciblesmdv3`, 2 couches) | 1 | 3 | [Gerber](pcb/gerber-pcb-detection-v3.zip) · [BOM](pcb/bom-jlcpcb-v3.csv) · [Pick & Place](pcb/pick-and-place-v3.csv) · [modèle 3D](pcb/OBJ_arduciblesmdv3_2026-07-19.zip) · [FCStd](cad/detection-pcb-v3.FCStd) · [Fritzing](fritzing/PetanqueDetection_Board_v3.fzpz) |
| — | Aimant néodyme cylindrique **∅4×2 mm, grade indiqué N80** (solidaire de la boule, déclenche le capteur) | 1 | 3 | [FCStd](cad/aimant-neodyme-4x2.FCStd) · [Fournisseur](https://www.supermagnete.fr/aimants-disques-neodyme/disque-magnetique-diametre-4mm-hauteur-2mm-neodyme-n45-nickele_S-04-02-N) — voir note grade N80 en section Mécanique — articulation |

*Fichiers de commande JLCPCB (Gerber/BOM/Pick & Place, prêts à l'import)
générés le 2026-07-17, à jour dans `pcb/*-v3.*`. Connecteur JST-XH replacé en
face arrière le 2026-07-19 (voir `pcb/pcb.readme`). Source des
quantités de lot (pas la consommation réelle de 1/cible) : capture
"Bill of Material" JLCPCB (`ressources/archives/PCB pour détection/composantssmd.png`)
— OH37 commandé ×25, résistance 10k ×30.*

## Électronique — contrôleur central (×1)

| Composant | Détail | Fichier |
|---|---|---|
| Carte Pro Micro (ATmega32U4) | Même puce qu'un Arduino Leonardo, dont elle reprend le brochage — reconnue comme tel par l'ordinateur (USB HID natif, clavier). Reçoit les 3 signaux de cible et envoie les touches `E`/`R`/`T`. | [Photo fournisseur](renders/vendor/pro-micro-board.png) · [Pièce Fritzing](fritzing/pro-micro-jeremylee-sparkfun.fzpz) |
| Sketch Arduino | Boucle de lecture des 3 broches cible + retranscription clavier via `Keyboard.h`. | [littlepromicro.ino](firmware/littlepromicro.ino) |
| Boîtier de protection (prototype) | Petit boîtier imprimé en 3D pour la carte nue, antérieur au boîtier de la borne ci-dessous. | [FCStd](enclosure/promicrousbcv1.FCStd) |
| Connecteurs RJ45 (×3) + câble Ethernet Cat5/6 | Un câble réseau par cible ramène le signal du capteur + alimentation vers la carte Pro Micro. | [Schéma Fritzing](schematics/pro-micro-wiring.png) ([source](fritzing/cablage-pro-micro.fzz)) · [Pièce Fritzing RJ45](fritzing/rj45-8-jack-sparkfun.fzpz) (déjà incluse nativement dans Fritzing : Core Parts → « RJ45 Jack ») · [Ancien schéma Leonardo](schematics/arduino-leonardo-rj45-wiring.png) |
| Câble Micro-USB | Liaison Leonardo ↔ PC. | — |
| Boîtier imprimé en 3D (façade, fermeture, casquette, support WS2812) | Réutilise le design du contrôleur Pro Micro, adapté pour loger le Leonardo. | [FCStd](enclosure/boitierJeufreecad020.FCStd) · [Façade STL](enclosure/boitierJeu-facade.stl) · [Fermeture STL](enclosure/boitierJeu-fermeture.stl) · [Casquette STL](enclosure/boitierJeufreecad020-casquette.stl) · [Support WS2812 STL](enclosure/boitierJeu-supportws2812.stl) |

> Le schéma de câblage montre aussi 4 boutons "Key up/left/right/down" :
> **obsolètes**, hérités d'un prototype antérieur — le jeu actuel n'utilise
> que les 3 cibles (`E`/`R`/`T`).

## Mécanique — par cible / articulation (×3)

Nomenclature exacte de `assemblageArticulation.FCStd` :

| Pièce | Qté/cible | Qté totale | Fichier |
|---|---|---|---|
| Plaque d'articulation milieu (découpe laser 140×40×5 mm) | 1 | 3 | [STEP](cad/plaque-milieu.step) · [FCStd](cad/plaque-milieu.FCStd) · [Plan coté](plans/plaque-milieu.pdf) |
| Plaque d'articulation sup (idem) | 1 | 3 | [STEP](cad/plaque-sup.step) · [FCStd](cad/plaque-sup.FCStd) · [Plan coté](plans/plaque-sup.pdf) |
| Plaque d'articulation inf (idem) | 1 | 3 | [STEP](cad/plaque-inf.step) · [FCStd](cad/plaque-inf.FCStd) · [Plan coté](plans/plaque-inf.pdf) |
| Vis métaux tête fraisée TF Pozi M4×50, acier zingué blanc | 2 | 6 | [FCStd](cad/vis-m4x50-tf-pozi.FCStd) · [Fournisseur](https://www.vis-express.fr/vis-metaux-tete-fraisee-tf-pozi-din-965/26698-vis-metaux-tete-fraisee-tf-pozi-2-m4x50-acier-zingue.html) |
| Écrou frein M4 (nylstop, DIN 985, acier zingué blanc) | 6 | 18 | [FCStd](cad/ecrou-frein-m4.FCStd) · [Fournisseur](https://www.vis-express.fr/ecrou-frein-din-985-din-985vs4325/31291-ecrou-frein-m4-acier-zingue.html) |
| Vis métaux M4×30 (tête fraisée Pozi n°2, DIN 965, acier zingué blanc) | 4 | 12 | [FCStd](cad/vis-m4x30.FCStd) · [Fournisseur](https://www.vis-express.fr/vis-metaux-tete-fraisee-tf-pozi-din-965/26679-vis-metaux-tete-fraisee-tf-pozi-n2-m4x30-acier-zingue.html) |
| Rotule radiale **GE8C** (rotule à rotule, alésage 8 mm) | 1 | 3 | [FCStd](cad/rotule-ge8c.FCStd) · variante articulée (chape + bille réelles, utilisée dans l'assemblage) : [FCStd](cad/rotule-ge8-articulee.FCStd) · [Fournisseur](https://www.lebonroulement.com/rotule-serie-ge-gek-gedo-geuk/147702-rotule-radiale-ge8c-kml.html) |
| Entretoise carte électronique (H31, sur-mesure) | 1 | 3 | [FCStd](cad/entretoise-h31.FCStd) |
| Rondelle plate épaisse M8×21×4 série L (DIN 7349) | 2 | 6 | [FCStd](cad/rondelle-epaisse-din7349-m8.FCStd) · [Fournisseur](https://www.vis-express.fr/rondelle-plate-serie-l-large-din-7349/5153-rondelle-plate-m8x21x4-serie-l-large-acier-zingue-blanc.html) |
| Rondelle 8×22×1,5 mm | 1 | 3 | [FCStd](cad/rondelle-8x22x1-5.FCStd) · [Fournisseur](https://www.vis-express.fr/rondelle-plate-l-nfe-25513-nfe-25513vs-nfe25513-grade-c/29545-rondelle-plate-m8x22x15-l-acier-zingue.html) |
| Tampon ressort **polychloroprène (CR) 60 SHA, ∅20, 8,5×15 mm** (amortisseur de rebond) | 1 | 3 | [FCStd](cad/tampon-ressort-cr60.FCStd) · [STL](cad/tampon-ressort-cr60.stl) · variante déformable (utilisée dans l'assemblage) : [FCStd](cad/tampon-ressort-cr60-deformable.FCStd) |
| Vis métaux CHC BTR (clé de 6) M8×70, filetée sur 28, classe 12.9, acier brut | 1 | 3 | [FCStd](cad/vis-chc-m8x70.FCStd) · [Fournisseur](https://www.vis-express.fr/vis-metaux-chc-btr-filetage-total-classe-129-hexagonal-creux-din-912-din-912-iso-4762/14889-vis-metaux-chc-btr-cle-de-6-hc6-m8x70-filetee-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) |
| Écrou frein M8 (nylstop, DIN 985, acier zingué blanc) | 1 | 3 | [FCStd](cad/ecrou-frein-m8.FCStd) · [Fournisseur](https://www.vis-express.fr/ecrou-frein-din-985-din-985vs4325/31317-ecrou-frein-m8-acier-zingue.html) |
| Boule de pétanque (∅70 mm — modélisée pleine par simplification CAO ; une vraie boule est toujours une coque creuse) | 1 | 3 | [FCStd](cad/boule-petanque-pleine.FCStd) · [Ébauche testée (Décathlon)](https://www.decathlon.fr/p/jeu-de-3-boules-de-petanque-100-loisir-lisses/324055/c231c5m8579726) — perçage/taraudage M8 validé malgré la coque fine ; remplissage terre/gravier → corrosion de l'axe, graissage recommandé ; piste non résolue pour une meilleure coque perçable/taraudable : [boule inox ∅60×2 mm insert M8](https://www.metalenstock.fr/boules-et-bagues-en-inox/542-boule-decorative-inox-creuse-diametre-60-epaisseur-2-mm-insert-m8.html) · [boule inox ∅80×2 mm insert M8](https://www.metalenstock.fr/boules-et-bagues-en-inox/543-boule-decorative-inox-creuse-diametre-80-epaisseur-2-mm-insert-m8.html) (non testées) ; recherche d'un ∅70 mm prêt-à-l'emploi (percé+taraudé M8) infructueuse chez les fournisseurs inox spécialisés (Metalenstock, Esse, Oxynov — gamme standard 60→80 mm, rien à 70 mm) ; piste la plus proche : [boule acier brut ∅70×3 mm non taraudée (decoferforge.com)](https://www.decoferforge.com/rubrique/boules-acier/boules-creuses), à percer/tarauder soi-même et non inox (anticorrosion à ajouter) ; Metalenstock propose sinon un devis sur mesure |
| Interface axe-aimant (sur-mesure, ∅4 mm) | 1 | 3 | [FCStd](cad/interface-axe-aimant-4mm.FCStd) |
| Aimant néodyme ∅4×2 mm, grade indiqué N80 | 1 | 3 | *(doublon avec la ligne électronique ci-dessus — même aimant, à ne compter qu'une fois)* · [Fournisseur](https://www.supermagnete.fr/aimants-disques-neodyme/disque-magnetique-diametre-4mm-hauteur-2mm-neodyme-n45-nickele_S-04-02-N) — **N80 n'est pas un grade néodyme standard** (grades réels : N35 à N52), probable confusion avec la température de fonctionnement max. (80 °C) ; la référence la plus proche en ∅4×2 mm est un grade N45 |

Sous-assemblage complet : [assemblage-articulation.FCStd](cad/assemblage-articulation.FCStd).

*Depuis le 2026-07-20, `assemblage-articulation.FCStd` affiche les variantes
articulée/déformable de la rotule GE8 et du tampon ressort (géométrie réelle
en deux corps pour la rotule — chape fixe + bille solidaire de l'axe — et
profil de révolution pour le tampon) au lieu des pièces figées d'origine.
Les objets d'origine (`RotuleGE8_001`, `tamponressort_001`) sont conservés
dans le fichier mais masqués, pour ne pas casser les contraintes A2plus qui
s'y réfèrent. Achat/nomenclature inchangés — même rotule GE8C, même tampon
CR60 du commerce ; seule la représentation CAD change.*

## Mécanique — châssis (×1, non dupliqué)

Nomenclature exacte de `ChassisAssemblageV7.FCStd` :

| Pièce | Dimensions | Qté | Fichier |
|---|---|---|---|
| Plateau V7 (base, tôle pliée) | 800×343×86 mm | 1 | [STEP](cad/plateau-v7.step) |
| Équerre V7 (fixation plateau ↔ supports/articulations) | ~38×30–48×30–48 mm | 6 | [STEP](cad/equaire-v7.step) |
| Support V7 (rail de maintien) | 8×328,7×77,8 mm | 2 | [STEP](cad/support-v7.step) |
| Sous-assemblage articulation (voir tableau ci-dessus) | 70×140×136,3 mm | 3 | [FCStd](cad/assemblage-articulation.FCStd) |

Assemblage complet : [chassis-assemblage-v7.FCStd](cad/chassis-assemblage-v7.FCStd).

## Sources

- Assemblages FreeCAD inspectés directement (FreeCAD 1.0.2, mode console) :
  `ChassisAssemblageV7.FCStd` (82 objets) et `assemblageArticulation.FCStd`
  (110 objets), dans `ressources/modélisation/Doc final/ChassisV7/`.
- BOM électronique : `ressources/archives/PCB pour détection/composantssmd.png`
  (export JLCPCB).
- Schéma de câblage : `ressources/archives/Contrôleurs de jeu/arduino leonardo/arducibleLeonardoschéma_bb.png`.

*Les quantités "hors châssis" (visserie de fixation plateau/équerre/support,
si non modélisée dans l'assemblage) ne sont pas incluses ici : l'assemblage
FreeCAD ne modélise pas de pièce de fixation explicite à ce niveau.*

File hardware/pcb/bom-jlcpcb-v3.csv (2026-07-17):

ID | Name | Designator | Footprint | Quantity | Manufacturer Part | Manufacturer | Supplier | Supplier Part | Price
1 | CONN-TH_XH-3A | DATA/-/+ | CONN-TH_XH-3A | 1 | XH-3A | BOOMELE(博穆精密) | LCSC | C2316 | 0.011
2 | SOT-23-3_L2.9-W1.6-P1.90-LS2.8-BR-CW | OH37 | SOT-23-3_L2.9-W1.6-P1.90-LS2.8-BR-CW | 1 | OH37 | 南京欧卓 | LCSC | C174064 | 0.257
3 | R0603 | 10K | R0603 | 1 | SCR0603J10K | VO(翔胜) | LCSC | C3017715 | 0.001

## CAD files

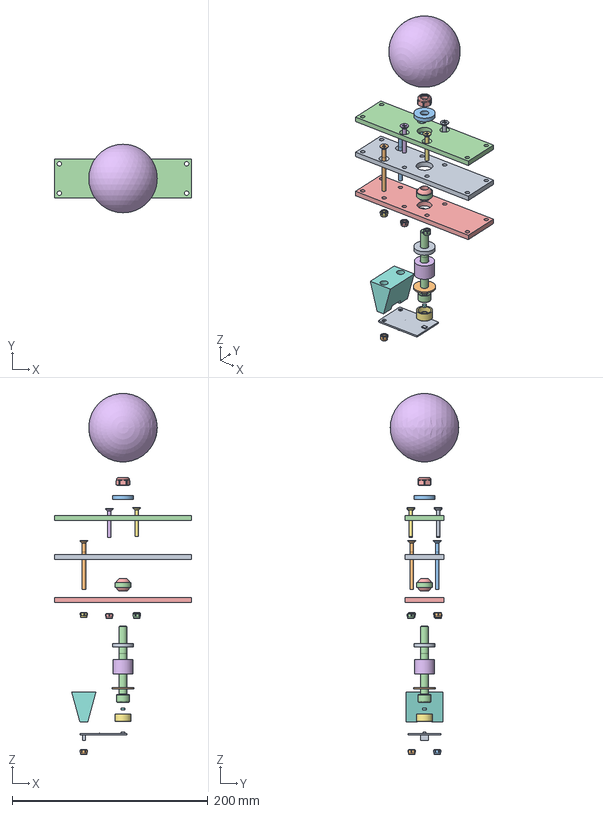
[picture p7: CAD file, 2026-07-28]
hardware/cad/assemblage-articulation-eclate-manuel.FCStd
140.0 x 70.0 x 368.5 mm
plaquearticulationMilieu_001
Vis métaux Tête fraisée TF Pozi 2 M4X50 Acier zingué_001
Vis métaux Tête fraisée TF Pozi 2 M4X50 Acier zingué_002
plaquearticulationsup_001
plaquearticulationINF_001
vis4x30_001
vis4x30_002
vis4x30_003
vis4x30_004
EcrouM4_001
EcrouM4_002
EcrouM4_003
EcrouM4_004
EcrouM4_005
EcrouM4_006
entretoisesV5H31_001
DIN 7349 M8_001
rondelle8x22x1,5_001
DIN 7349 M8_002
Vis métaux CHC BTR Clé de 6 HC6 M8X70 Filetée sur 22 Classe 12.9 Acier brut_001
EcrouM8_001
boulepleineV2_001
interfaceAxeAimant4mm_001
aimant4x2_001
detection-pcb-v3_001
ecrou-frein-m4_001
ecrou-frein-m4_002
Chape exterieure GE8 (fixe)
Bille + axe GE8 (mobile, solidaire du M8)
Tampon ressort CR60 deformable

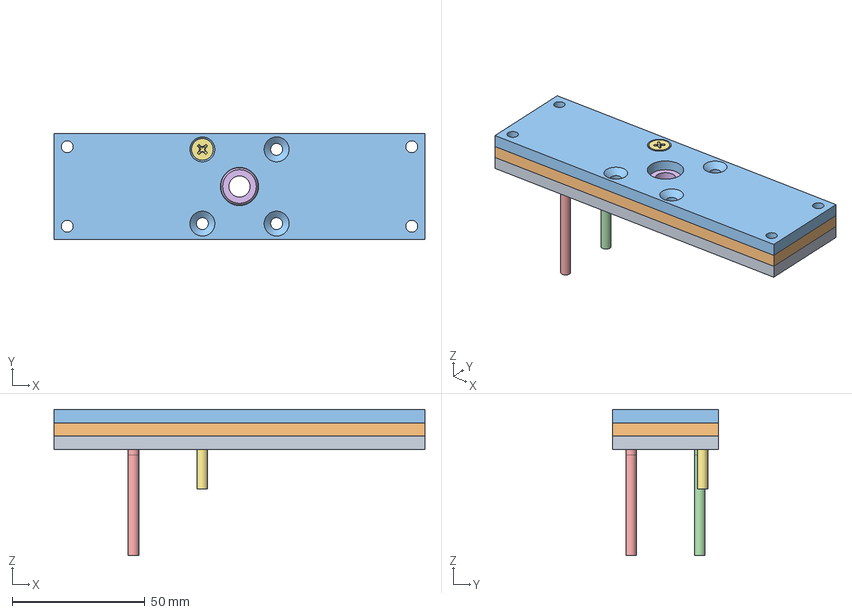
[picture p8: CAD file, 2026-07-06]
ressources/modélisation/Doc final/articulation/assemblage.FCStd
140.0 x 40.0 x 55.2 mm
plaquearticulationINF_001
plaquearticulationMilieu_001
plaquearticulationsup_001
Vis métaux Tête fraisée TF Pozi 2 M4X50 Acier zingué_001
Vis métaux Tête fraisée TF Pozi 2 M4X50 Acier zingué_002
RotuleGE8_001
vis4x30_001

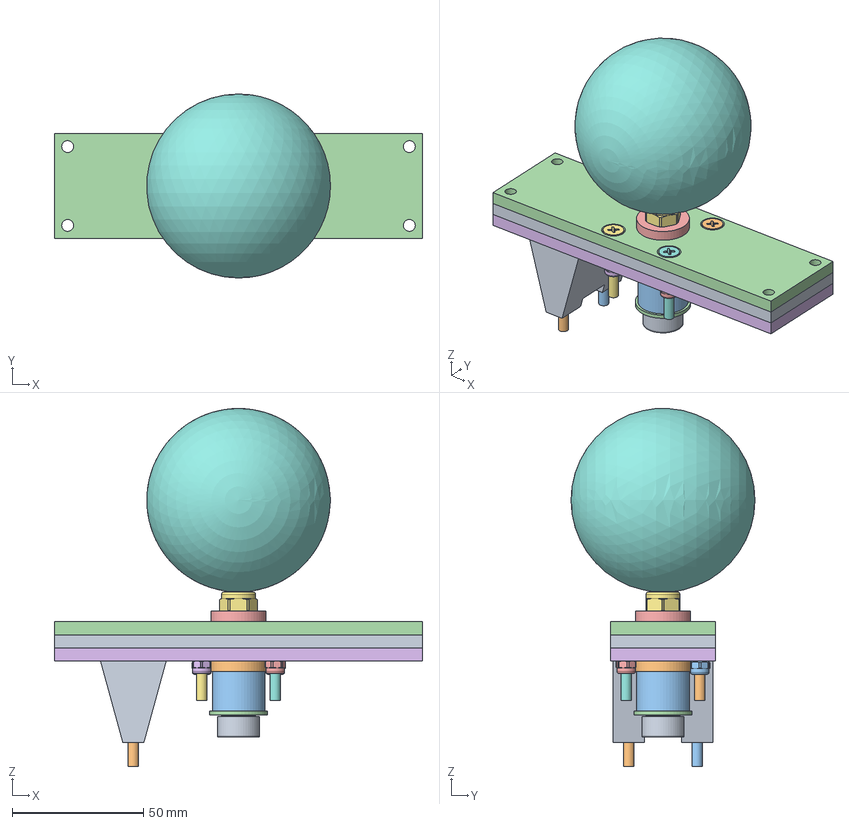
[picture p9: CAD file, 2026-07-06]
ressources/modélisation/Doc final/ChassisV7/assemblageArticulation.FCStd
140.0 x 70.0 x 136.2 mm
plaquearticulationMilieu_001
Vis métaux Tête fraisée TF Pozi 2 M4X50 Acier zingué_001
Vis métaux Tête fraisée TF Pozi 2 M4X50 Acier zingué_002
plaquearticulationsup_001
RotuleGE8_001
plaquearticulationINF_001
vis4x30_001
vis4x30_002
vis4x30_003
vis4x30_004
EcrouM4_001
EcrouM4_002
EcrouM4_003
EcrouM4_004
EcrouM4_005
EcrouM4_006
entretoisesV5H31_001
DIN 7349 M8_001
tamponressort_001
rondelle8x22x1,5_001
DIN 7349 M8_002
Vis métaux CHC BTR Clé de 6 HC6 M8X70 Filetée sur 22 Classe 12.9 Acier brut_001
EcrouM8_001
boulepleineV2_001
interfaceAxeAimant4mm_001
aimant4x2_001

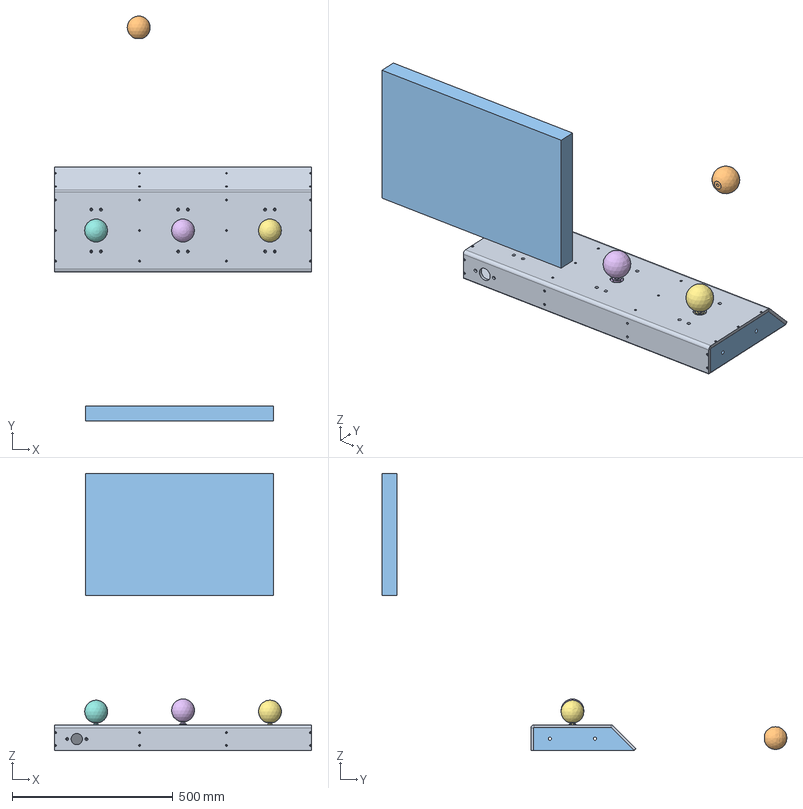
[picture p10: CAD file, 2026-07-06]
ressources/modélisation/modelisation/parts/ASSEMBLAGEGÉNÉRALv4.FCStd
800.0 x 1258.3 x 861.3 mm
ChassisPlateauV4_001
supportvChassisV4_001
supportvChassisV4_002
supportvChassisV4_003
supportvChassisV4_004
AssemblageArticulationV2_001
AssemblageArticulationV2_002
AssemblageArticulationV2_003
plastron chassisV4_001
boulediam70_001
m0510_tv_dvd_combination1_m0510_tv_dvd_combination_PART3_001

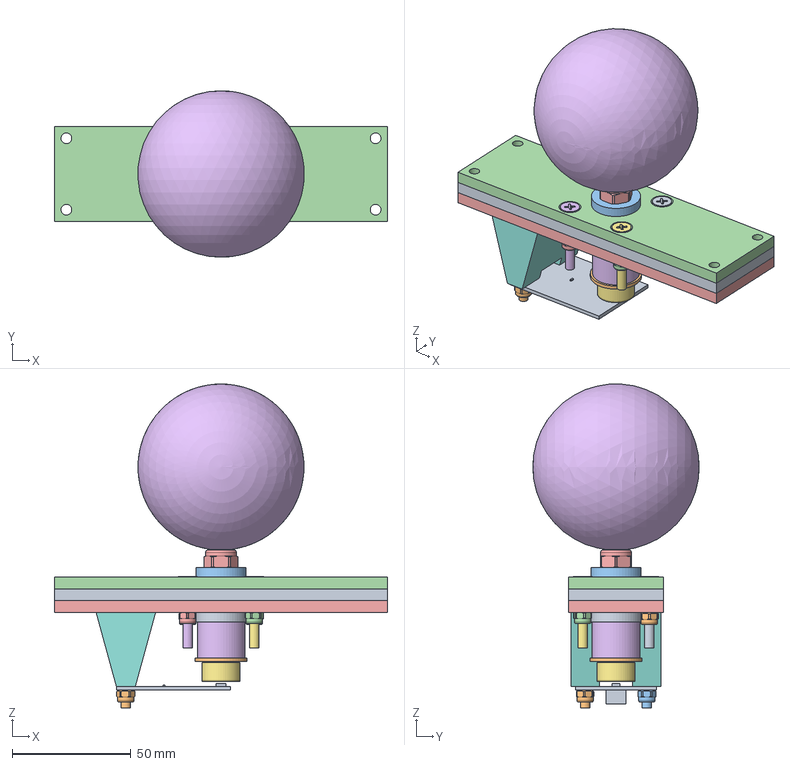
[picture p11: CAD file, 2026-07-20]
hardware/cad/assemblage-articulation.FCStd
140.0 x 70.0 x 136.2 mm
plaquearticulationMilieu_001
Vis métaux Tête fraisée TF Pozi 2 M4X50 Acier zingué_001
Vis métaux Tête fraisée TF Pozi 2 M4X50 Acier zingué_002
plaquearticulationsup_001
plaquearticulationINF_001
vis4x30_001
vis4x30_002
vis4x30_003
vis4x30_004
EcrouM4_001
EcrouM4_002
EcrouM4_003
EcrouM4_004
EcrouM4_005
EcrouM4_006
entretoisesV5H31_001
DIN 7349 M8_001
rondelle8x22x1,5_001
DIN 7349 M8_002
Vis métaux CHC BTR Clé de 6 HC6 M8X70 Filetée sur 22 Classe 12.9 Acier brut_001
EcrouM8_001
boulepleineV2_001
interfaceAxeAimant4mm_001
aimant4x2_001
detection-pcb-v3_001
ecrou-frein-m4_001
ecrou-frein-m4_002
Chape exterieure GE8 (fixe)
Bille + axe GE8 (mobile, solidaire du M8)
Tampon ressort CR60 deformable

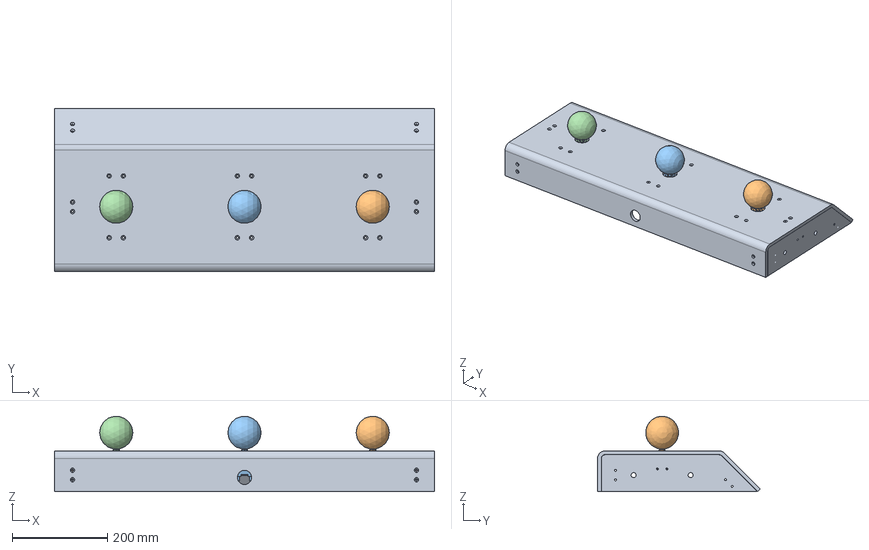
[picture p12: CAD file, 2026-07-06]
ressources/modélisation/Doc final/ChassisV7/ChassisAssemblageV7.FCStd
800.0 x 343.0 x 158.7 mm
plateauV7_001
equairev7_equaire_001
equairev7_equaire_002
equairev7_equaire_003
equairev7_equaire_004
equairev7_equaire_005
equairev7_equaire_006
supportv7_support_001
supportv7_support_002
assemblageArticulation_001
assemblageArticulation_002
assemblageArticulation_003

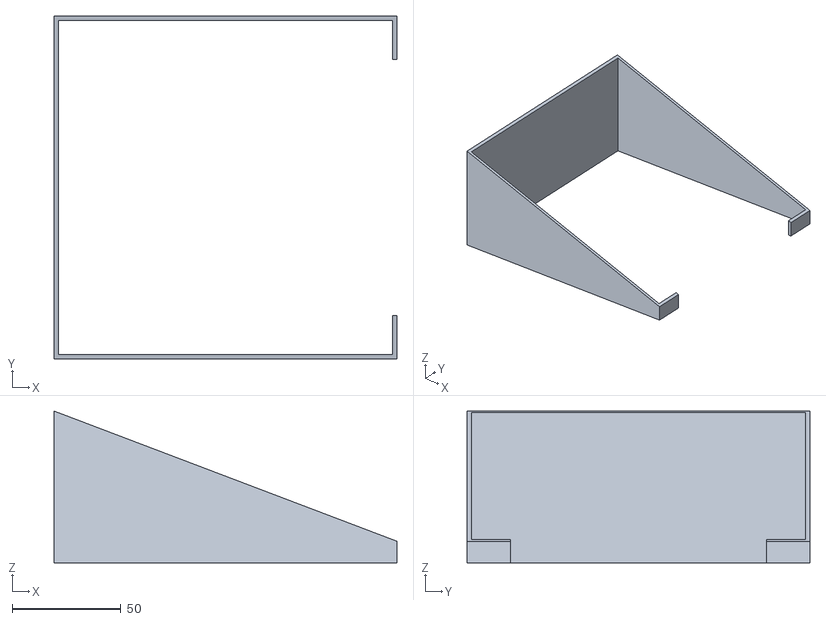
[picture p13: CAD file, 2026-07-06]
hardware/enclosure/boitierJeufreecad020-casquette.stl
158.0 x 158.0 x 70.0

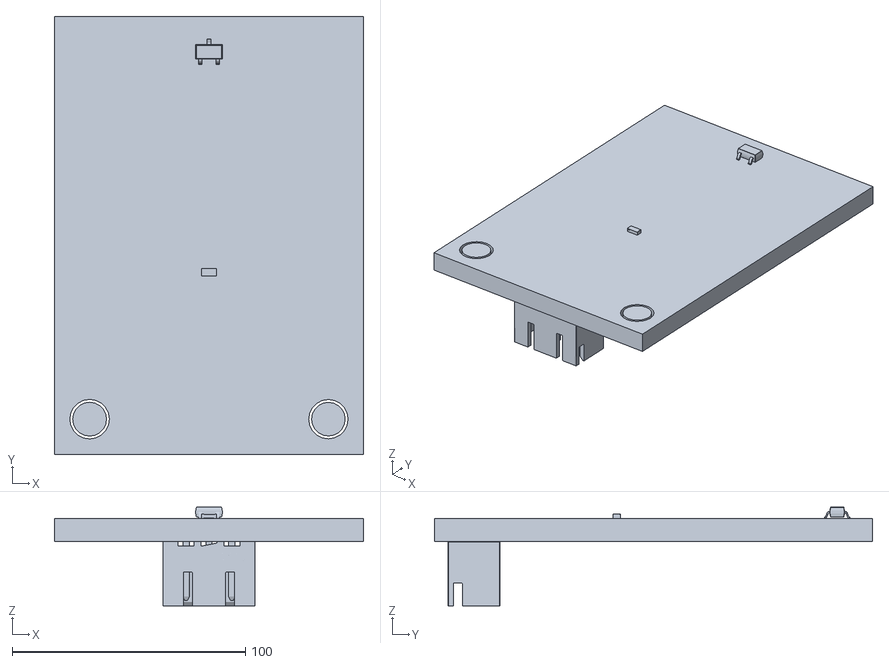
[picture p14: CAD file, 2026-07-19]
hardware/pcb/OBJ_arduciblesmdv3_2026-07-19/OBJ_arduciblesmdv3.obj
132.7 x 187.8 x 42.4

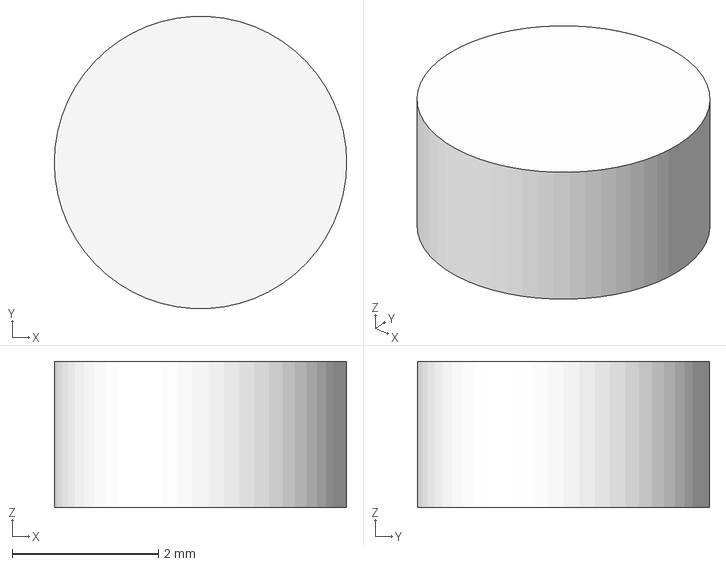
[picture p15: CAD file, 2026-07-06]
ressources/modélisation/Doc final/aimants néodyme 4x2 disque 4mm X 2mm/aimant4x2.FCStd
4.00 x 3.99 x 2.00 mm

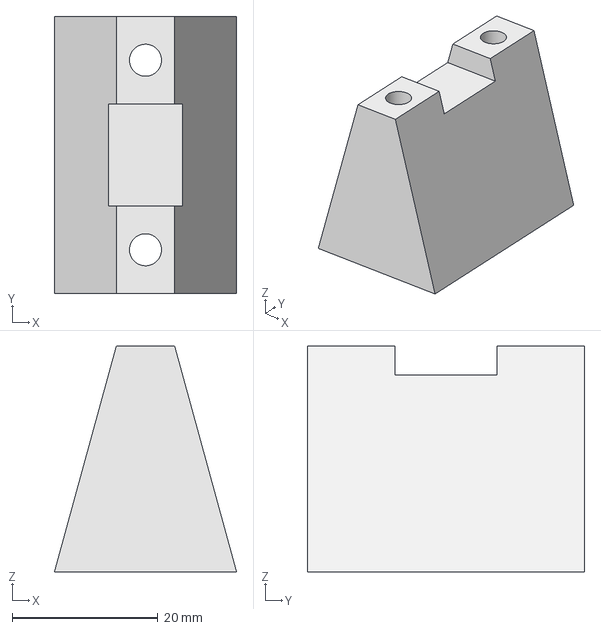
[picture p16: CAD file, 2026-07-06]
ressources/modélisation/Doc final/articulation/EntretoiseCarteElectronique/entretoisesV5H31.FCStd
25.0 x 38.0 x 31.0 mm

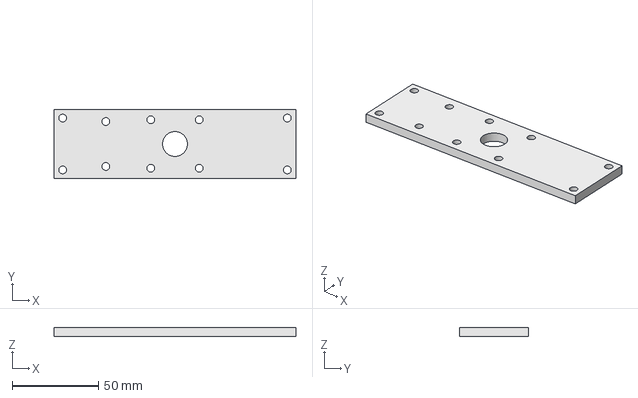
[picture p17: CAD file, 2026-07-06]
ressources/modélisation/Doc final/articulation/PlaqueInférieure/plaquearticulationINF.FCStd
140.0 x 40.0 x 5.00 mm

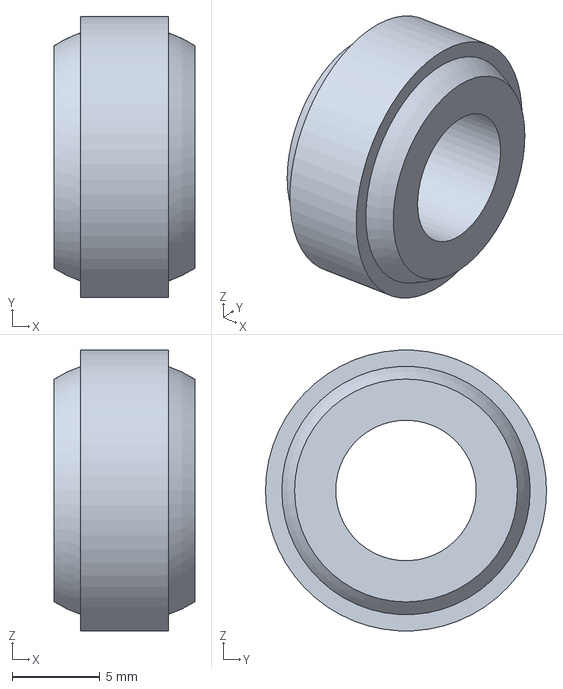
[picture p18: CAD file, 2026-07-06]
ressources/modélisation/Doc final/articulation/RotuleGE8/RotuleGE8.FCStd
8.00 x 16.0 x 16.0 mm

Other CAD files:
ressources/modélisation/Doc final/articulation/AssemblageArticulation.FCStd
ressources/modélisation/modelisation/parts/Chassis/chassisv4/parts/assemblage.FCStd
ressources/modélisation/modelisation/parts/Chassis/chassisv5/assemblage.FCStd
hardware/cad/chassis-assemblage-v7.FCStd
ressources/modélisation/Doc final/articulation/PlaqueMilieu/plaquearticulationMilieu.FCStd
ressources/modélisation/Doc final/articulation/PlaqueSupérieure/plaquearticulationsup-plaqueSup.step
hardware/cad/boule-petanque-pleine.FCStd
hardware/cad/detection-pcb-v3.FCStd
hardware/cad/ecrou-frein-m4.FCStd
hardware/cad/ecrou-frein-m8.FCStd
hardware/cad/equaire-v7.step
hardware/cad/interface-axe-aimant-4mm.FCStd
hardware/cad/interface-noyau-rj45.FCStd
hardware/cad/interface-noyau-rj45.stl
hardware/cad/plaque-inf.FCStd
hardware/cad/plaque-inf.step
hardware/cad/plaque-milieu.FCStd
hardware/cad/plaque-milieu.step
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

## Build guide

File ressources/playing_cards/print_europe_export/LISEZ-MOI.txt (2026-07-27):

Fanny Pétanque World Tour — Export pour Print Europe
(jeuxdecartes.printeurope.fr)

Fichiers : deck_1.pdf (54 cartes), deck_2.pdf (58 cartes).

Structure de chaque PDF (conforme au guide PAO Print Europe, "Option 1 :
dos identique pour toutes les cartes") : page 1 = dos, pages suivantes =
les rectos dans l'ordre A,2,3...K de Coeur, Carreau, Trèfle, Pique puis
les Jokers.

Format : CMJN 300 dpi, 1 carte par page, page = format fini (63x88mm) +
2mm de fond perdu de chaque côté (toile 67x92mm). Marge de sécurité de 3mm
respectée pour tous les textes/badges. Coins arrondis (rayon 4mm) non
matérialisés dans le fichier : c'est Print Europe qui les découpe.

À faire côté site : jeuxdecartes.printeurope.fr -> configurer un jeu de
54 (ou 58) cartes au format Poker 63x88mm, dos identique pour tout le jeu,
uploader le PDF correspondant.

Point d'attention : la conversion RVB->CMJN de ce fichier est une
conversion basique (sans profil ICC calibré). Avant un tirage en quantité,
il est recommandé de commander une épreuve numérique ou papier (proposée
par Print Europe) pour valider les couleurs.

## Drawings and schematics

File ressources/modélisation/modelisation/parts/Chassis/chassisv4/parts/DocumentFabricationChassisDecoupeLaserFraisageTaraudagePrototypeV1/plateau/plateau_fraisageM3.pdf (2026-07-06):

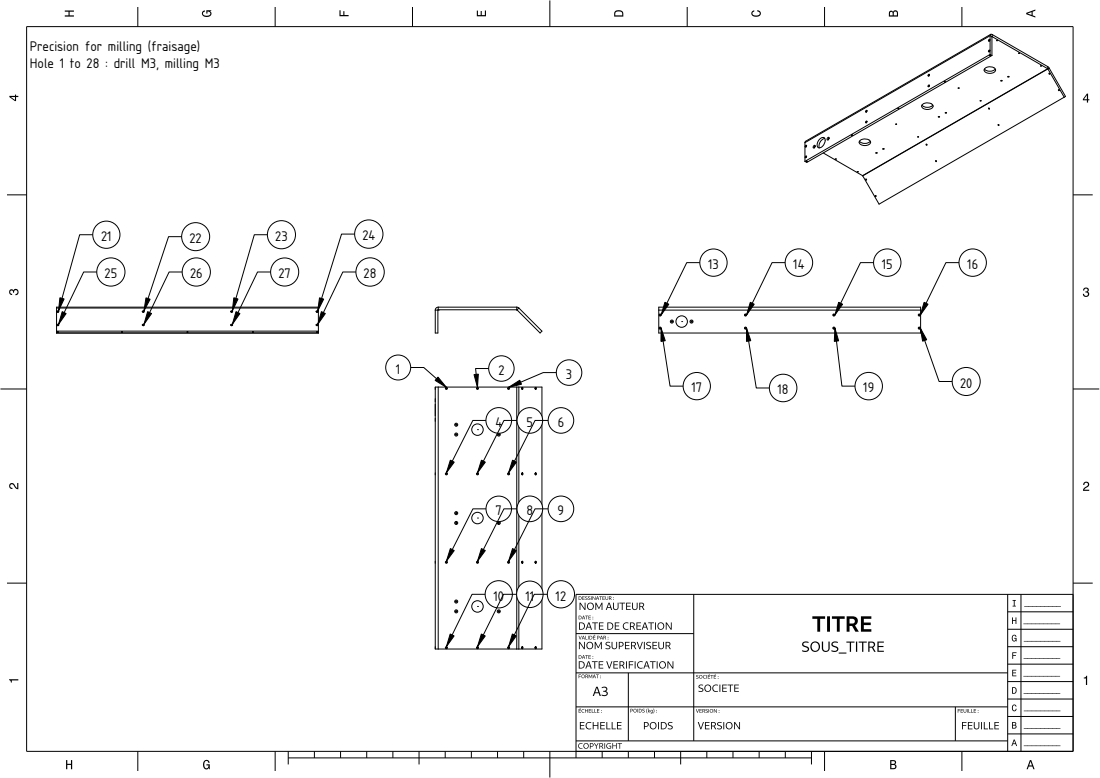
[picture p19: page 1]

Precision for milling (fraisage)
Hole 1 to 28 : drill M3, milling M3

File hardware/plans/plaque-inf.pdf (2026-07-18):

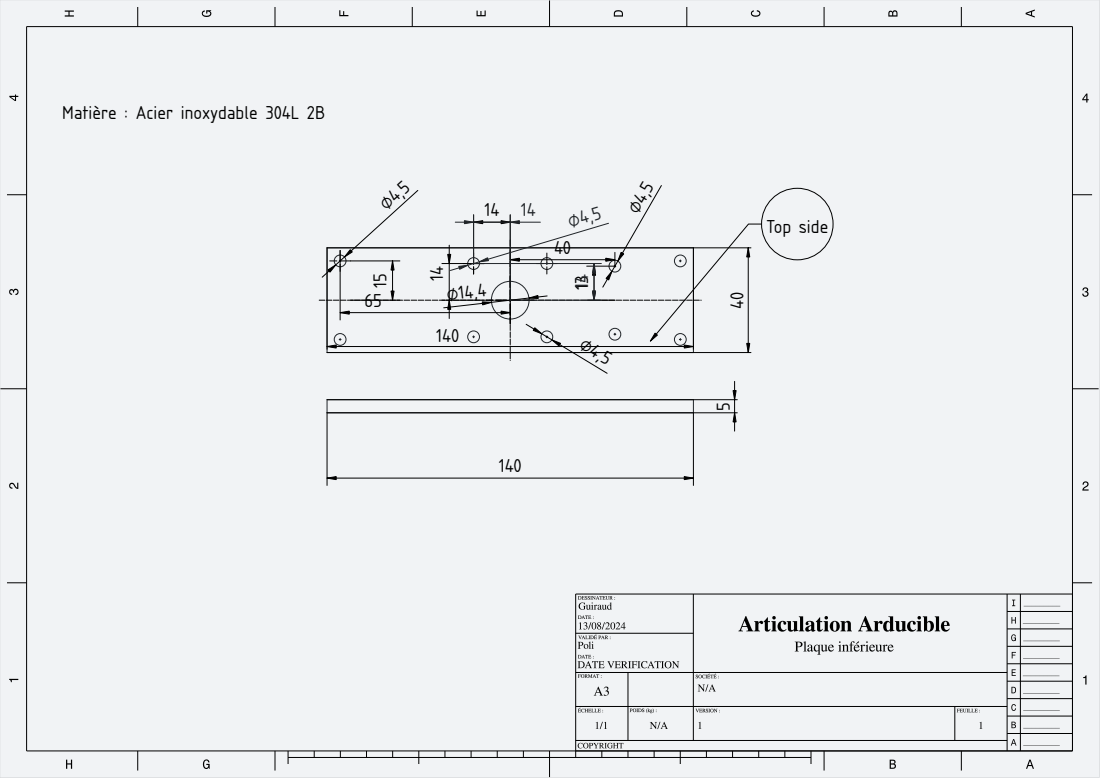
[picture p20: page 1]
Top side

Matière : Acier inoxydable 304L 2B

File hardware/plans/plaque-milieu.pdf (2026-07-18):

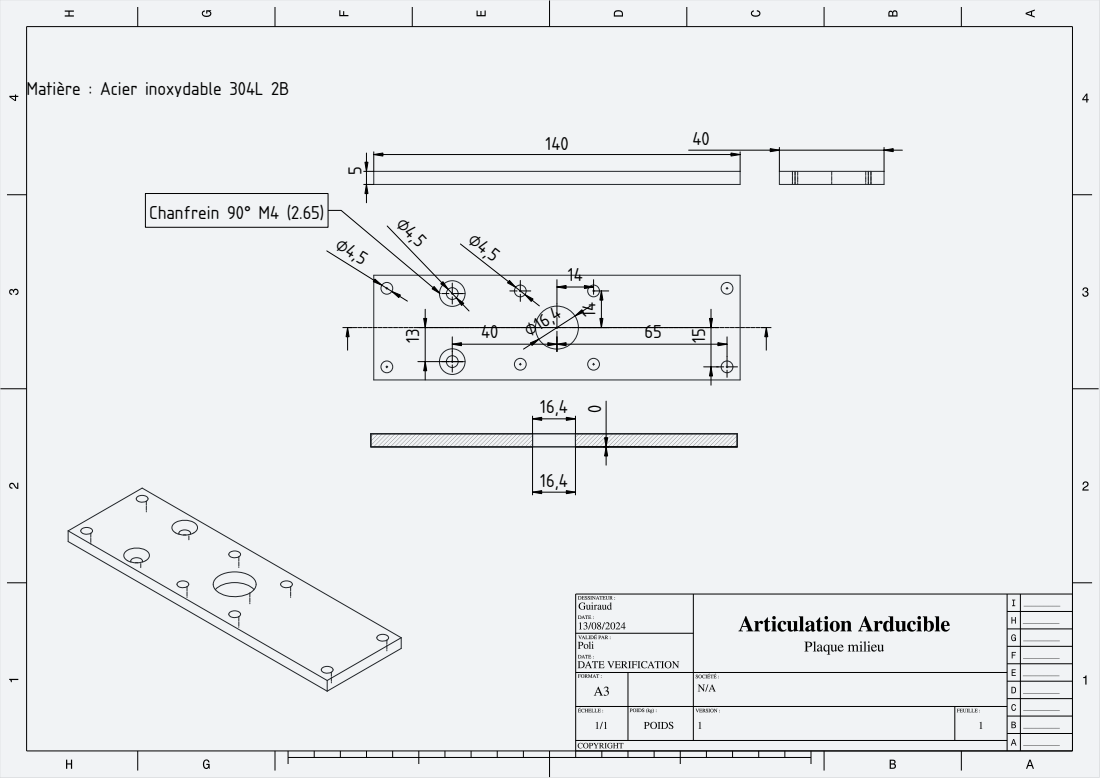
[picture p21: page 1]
Chanfrein 90° M4 (2.65)

Matière : Acier inoxydable 304L 2B

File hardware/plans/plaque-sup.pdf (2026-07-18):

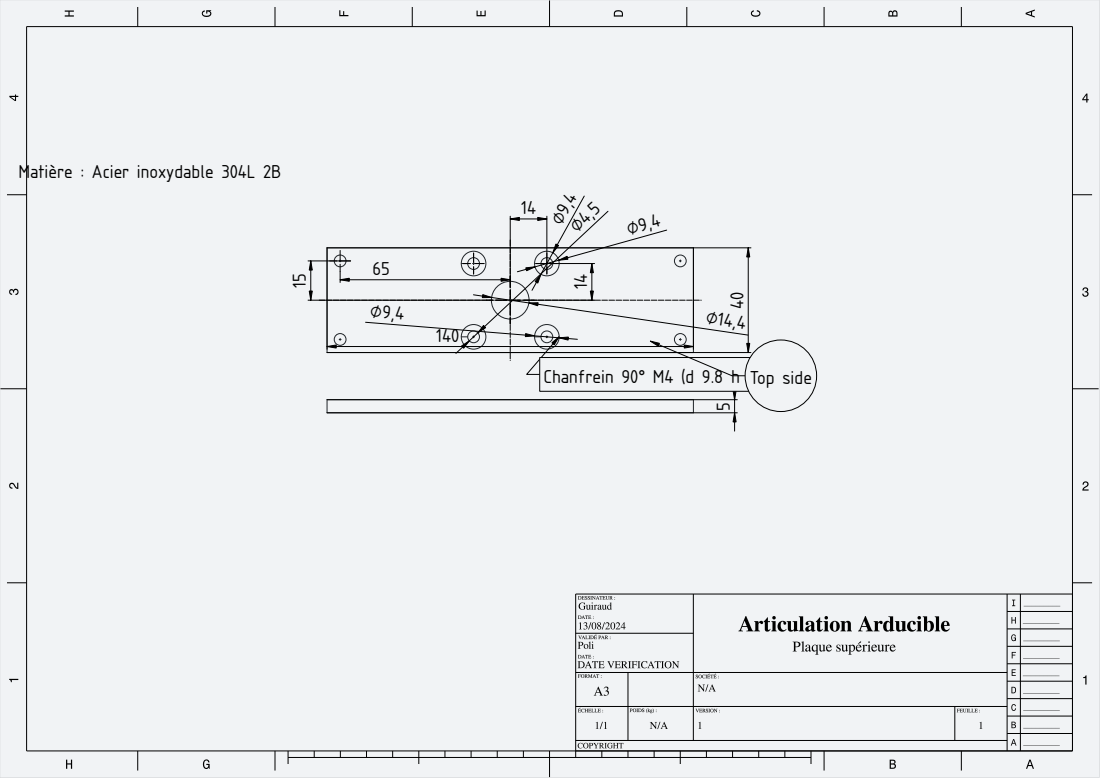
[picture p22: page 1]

atière : Acier in

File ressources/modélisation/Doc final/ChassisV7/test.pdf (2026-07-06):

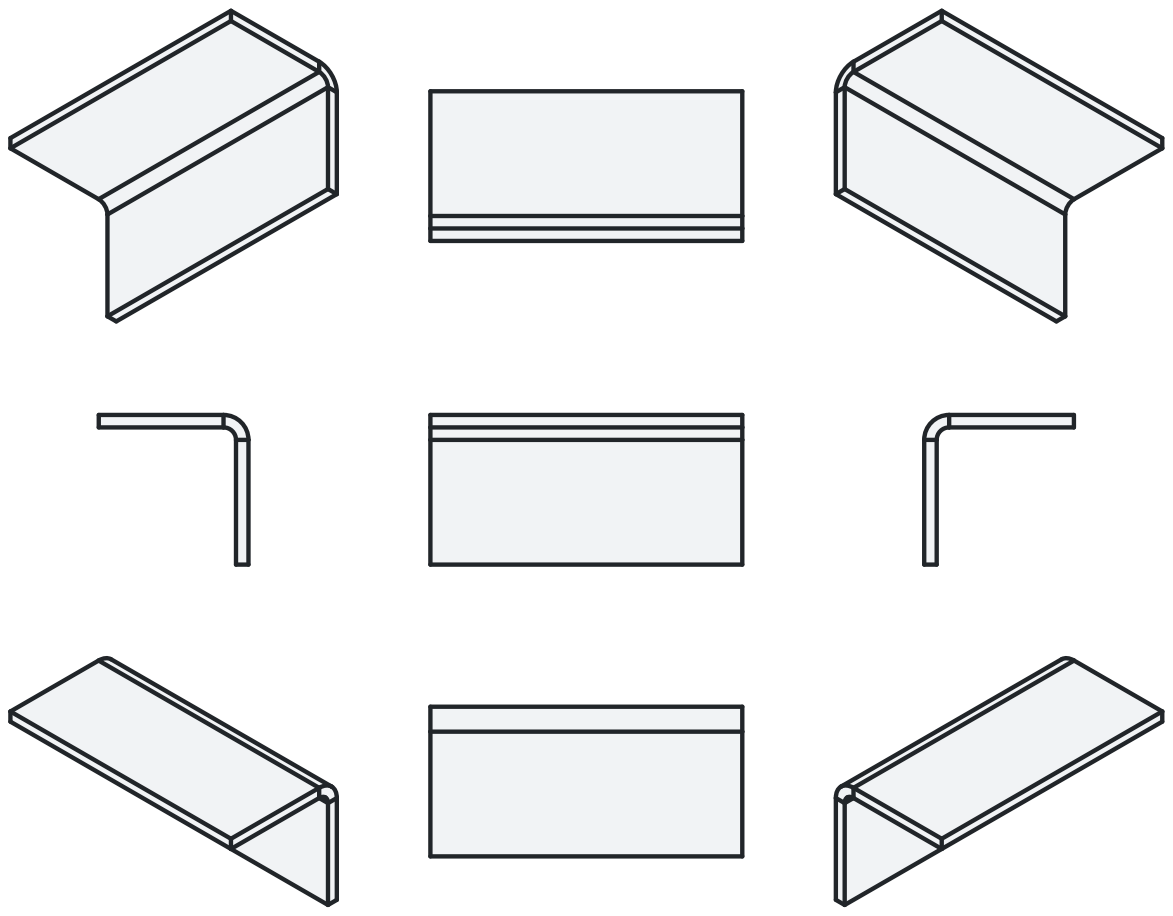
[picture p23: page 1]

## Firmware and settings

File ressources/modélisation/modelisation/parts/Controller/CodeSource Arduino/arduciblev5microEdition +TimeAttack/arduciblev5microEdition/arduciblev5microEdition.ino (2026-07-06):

#include <Wire.h> 
#include <LiquidCrystal_I2C.h>
LiquidCrystal_I2C lcd(0x27,20,4);
#include <Keyboard.h>
#include <Adafruit_NeoPixel.h>
#define PIN        10 // 
#define NUMPIXELS 3 // 
Adafruit_NeoPixel pixels(NUMPIXELS, PIN, NEO_GRB + NEO_KHZ800);
const int reserveLedCible = -1; 
int intensiteLed=255;
int nbCibles=3;
int boutonG = 7;
int boutonD = 8;
int cible1 = 16;
int cible2 = 14;
int cible3 = 15;
int Buzzer = 9;
bool statusBoutonG;
bool statusBoutonD;
bool statusCible1;
bool statusCible2;
bool statusCible3;
bool timeAttack = false;
int Score=0;
int GameTimer = 60;
int currentMillis=0;
int previousMillis=0;

//variables pour la gestion du jeu

int nbJoueurs = 1;
int oldNbJoueurs = 0;
int joueurEnCours = 1;
int tourEnCours = 1;
int nbTours = 3;
int oldCible[] = {0,0,0};
int cibleEnCours = 1;
int cibleTouchee = 0;
int resteEnCours = 3;
int R=0;
int G=0;
int B=0;
int scores[] = {0,0,0,0,0,0};
int tauxReussite[] = {0,0,0,0,0,0};
int oldClassement[] = {0,0,0,0,0,0};
int classement[] = {0,0,0,0,0,0};
int pointBonus[] = {0,0,0,0,0,0};
boolean killer[] = {0,0,0,0,0,0};
int levels[] = {0,0,0,0,0,0};
boolean initialisation = 1;
boolean partieEnCours = 0;
boolean partieFinie = 0;
bool debugMode=false;
int delaiTemporisation = 1000;
String tabScores[5];

uint8_t custChar[8][8] = {
{
  B11111,
  B11111,
  B11111,
  B00000,
  B00000,
  B00000,
  B00000,
  B00000
},// Small top line - 0

{
  B00000,
  B00000,
  B00000,
  B00000,
  B00000,
  B11111,
  B11111,
  B11111
},// Small bottom line - 1


{
  B11111,
  B00000,
  B00000,
  B00000,
  B00000,
  B11111,
  B11111,
  B11111
},// Small lines top and bottom -2


{
  B11111,
  B11111,
  B11111,
  B00000,
  B00000,
  B00000,
  B11111,
  B11111
}, // -3



{
  B11111,
  B11111,
  B11111,
  B11111,
  B11111,
  B11111,
  B01111,
  B00111
},// Left bottom chamfer full - 4

{
  B11100,
  B11110,
  B11111,
  B11111,
  B11111,
  B11111,
  B11111,
  B11111
},// Right top chamfer full -5


{
  B11111,
  B11111,
  B11111,
  B11111,
  B11111,
  B11111,
  B11110,
  B11100
},// Right bottom chamfer full -6

{
  B00111,
  B01111,
  B11111,
  B11111,
  B11111,
  B11111,
  B11111,
  B11111
},// Left top chamfer full -7
 
};

// Define our numbers 0 thru 9
// 254 is blank and 255 is the "Full Block"
uint8_t bigNums[38][6] = {
  {7, 0, 5, 4, 1, 6}, //0
  {0, 5, 254, 1, 255, 1},     //1
  {0, 0, 5, 4, 2, 2},         //2
  {3, 3, 5, 2, 2, 6},         //3
  {4, 1, 5, 254, 254, 255},   //4
  {255, 3, 3, 2, 2, 6},       //5 
  {7, 3, 3, 4, 2, 6},         //6 
  {0, 0, 5, 254, 7, 254},     //7 
  {7, 3, 5, 4, 2, 6},         //8 
  {7, 3, 5, 254, 254, 6},     //9
  {0, 3, 5, 254, 2, 254},//? 10
  {254, 255, 254, 254, 2, 254},//! 11 
 {7, 3, 5, 255, 254, 255}, //A 12
 {255, 3, 6, 255, 2, 5}, //B 13
 {7, 0, 0, 4, 1, 1}, //C 14
 {255, 0, 5, 255, 1, 6}, //D 15
 {255, 3, 3, 255, 2, 2}, //E 16
 {255, 3, 3, 255, 254, 254}, //F 17
 {7, 0, 0, 4, 1, 5}, //G 18
{255, 1, 255, 255, 254, 255},  //H 19
 {0, 255, 0, 1, 255, 1}, //I 20
 {254, 254, 255,1,1, 6}, //J 21
 {255, 1, 6, 255, 254, 5}, //K 22
 {255, 254, 254, 255, 1, 1}, //L 23
 {5,1,7,255,254,255}, //M 24
 {5,1,255,255,0,4}, //N 25
 {7, 0, 5, 4, 1, 6}, //O 26
 {255, 3, 5, 255, 254, 254}, //P 27
 {7,0,5,4,1,255}, //Q 28
 {255, 3, 5, 255, 254,5}, //R 29
 {7, 3, 3, 2, 2,6}, //S 30
 {0, 255, 0, 254, 255, 254}, //T 31
 {255, 254, 255, 4, 1, 6}, //U 32
 {5, 254, 7, 4, 1, 6}, //V 33
 {5, 1, 7, 4,255, 6}, //W 34
 {4, 1, 6, 7, 254, 5}, //X 35
 {4,1,6,254,255,254}, //Y 36
 {0,3,6,7,2,1}, //Z 37
  
};


void setup() {                
    pinMode(boutonG, INPUT_PULLUP);
    pinMode(boutonD, INPUT_PULLUP);
    pinMode(cible1,INPUT);
    pinMode(cible2,INPUT); 
    pinMode(cible3,INPUT);
    pixels.begin();
    pixels.clear();
    pixels.show(); 
    lcd.init();
    lcd.backlight();
    for (int cnt = 0; cnt < sizeof(custChar) / 8; cnt++) {
        lcd.createChar(cnt, custChar[cnt]);
    }
    Serial.begin(9600);
    randomSeed(analogRead(0)); //lier la génération de nombre aléatoire au port analogique 1
	  
   couleurAleatoire();

   credit();
   soundHit();

	if (UDADDR & _BV(ADDEN))
  {
    Keyboard.begin();
  UsbPCGameControler();   // turn the LED on (HIGH is the voltage level)
  }
  
  randomSeed(analogRead(0)); //lier la génération de nombre aléatoire au port analogique 1

	
}


void loop()
{
  AcquisitionCapteurs(); 
 // Serial.println("BoutonG" + String(statusBoutonG) +" BoutonD" + String(statusBoutonD) + " cible1 " + String(statusCible1) + " cible2 " + String(statusCible2) + " cible3 " + String(statusCible3));
  if (initialisation==true){
    pixels.clear();
    pixels.show();
    InitGame();
    if (nbJoueurs == 5) {
      timeAttack = true;
      cibleAleatoire();
    }
    else{
      timeAttack = false;
    }
  }  
    
  if (partieEnCours==true){
    if (timeAttack == true){
		timeAttackMode();
    }
    else{
        trtPartieEnCours();
    }
  }
  
  if ( partieFinie==true ){trtPartieFinie();}
} 

void GererInterruption()
{
  if ( joueurEnCours == nbJoueurs && tourEnCours == nbTours && resteEnCours == 1 ){
    testKiller();
    partieEnCours = false;
    partieFinie = true;
  }
  else if (  joueurEnCours == nbJoueurs && resteEnCours == 1 ){
    testKiller();
    joueurEnCours = 1;
    resteEnCours = 3;
resetHistoriqueCibles();
    pixels.clear();
    pixels.show();
    tourEnCours++;
    EcranScores();
    EcranTourSuivant();
    EcranJoueurSuivant();
  }
  else if ( resteEnCours != 1 ){
    resteEnCours--; 
  }  
  else
  {
    testKiller();
    joueurEnCours++;
    resteEnCours = 3;
resetHistoriqueCibles();
    pixels.clear();
    pixels.show();
    EcranScores();
    EcranJoueurSuivant();
  }
}


void InitGame(){
  tourEnCours = 1;
  joueurEnCours = 1;
  resteEnCours = 3;
  
  for(int i=1; i<=5; i++){
    scores[i] = 0;
    killer[i] = 0;
    levels[i] = 0;
    pointBonus[i] =0;
    oldClassement[i] = 0;
    classement[i] = 0;
    GameTimer=60;
    Score=0;
  }
 
  
  statusBoutonG = digitalRead(boutonG);
  statusBoutonD = digitalRead(boutonD); 
    if (statusBoutonG==LOW){
        while(statusBoutonG==LOW){
          AcquisitionCapteurs();
          delay(100);
        }
        if (nbJoueurs == 5){
          nbJoueurs = 1;
        }
        else
        {
          nbJoueurs++;
        }
    }
    if (nbJoueurs != oldNbJoueurs){
      EcranInitialisation();
      oldNbJoueurs=nbJoueurs;
    }
    if (statusBoutonD==LOW){ 
        for (int i = 1; i <= nbJoueurs ; i++) {
          killer[i] = 1;
        } 
      EcranWait();
      Temporisation();  
      initialisation = false;
      partieEnCours = true;  
    }
}


void trtPartieEnCours(){
    cibleAleatoire();
    EcranWait();
    Temporisation();
    soundReadyToShot();
    pixels.clear();
    pixels.show();   // Mise a jour de la couleur des leds. 
    EcranEnJeu();
      while(statusBoutonG==HIGH && statusBoutonD==HIGH && statusCible1==LOW && statusCible2==LOW && statusCible3==LOW){
        AcquisitionCapteurs();
        //afficherMoniteurSerie();
      }
    determinerCibleTouchee();
      if (cibleTouchee == cibleEnCours){
        scores[joueurEnCours] = scores[joueurEnCours]+1+pointBonus[joueurEnCours];
          if(pointBonus[joueurEnCours] < 2){
          pointBonus[joueurEnCours] = pointBonus[joueurEnCours]+1;
          }
        EcranHit();
        soundHit();
          for (int i=0; i<4;i++){
            pixels.clear();
            pixels.show();
            delay(100);
            pixels.setPixelColor(cibleEnCours+reserveLedCible, pixels.Color(0, intensiteLed, 0));
            pixels.show();   // Mise a jour de la couleur des leds. 
            delay(100);
          }
        pixels.clear();
        pixels.show();
        determinerRang();
          
      }
      else{
        pixels.show();   // Mise a jour de la couleur des leds. 
        EcranMiss();
        soundMiss();
           for (int i=0; i<4;i++){
             pixels.clear();
             pixels.show();
             delay(100);
             pixels.setPixelColor(cibleEnCours+reserveLedCible, pixels.Color(0, 0, intensiteLed));
             pixels.setPixelColor(cibleTouchee+reserveLedCible, pixels.Color(intensiteLed, 0, 0));
             pixels.show();   // Mise a jour de la couleur des leds. 
             delay(100);
           }
         pixels.clear();
         pixels.show();  
         pointBonus[joueurEnCours] = 0;
         killer[joueurEnCours] = 0; 
      }
    GererInterruption();
  }

void trtPartieFinie(){
  //gestion contest
    while(killer[1]==1 || killer[2]==1 || killer[3]==1 || killer[4]==1 || killer[5]==1){
      //Serial.println("KILLER STATUS J1 " + String(killer[1]) + String(killer[2]) + String(killer[3]) + String(killer[4]) + String(killer[5]) );   
        for (int i = 1; i <= nbJoueurs ; i++){
          if (killer[i] == 1){
            joueurEnCours = i;
            extraBall();
          }
        } 
    }
  partieFinie = false;
  partieEnCours = false;
  initialisation = true;
  oldNbJoueurs = 0;
  triclassement();
  //credit();
  AfficheFin();
}

void extraBall(){
  resetHistoriqueCibles();
  cibleAleatoire();
  EcranJoueurSuivant();
  lcd.clear();
  //EcranTirBonus();
  //EcranWait();
  Temporisation();
  EcranGo();
  pixels.clear();
  pixels.show();   // Mise a jour de la couleur des leds. 
  soundReadyToShot();
  EcranEnJeu();
    while(statusBoutonG==HIGH && statusBoutonD==HIGH && statusCible1==LOW && statusCible2==LOW && statusCible3==LOW){
      AcquisitionCapteurs();
      afficherMoniteurSerie();
    }
  determinerCibleTouchee();
    if (cibleTouchee == cibleEnCours){
      scores[joueurEnCours] = scores[joueurEnCours]+1+pointBonus[joueurEnCours];
      EcranHit();
      soundHit();
        for (int i=0; i<4;i++){
          pixels.clear();
          pixels.show();
          delay(100);
          pixels.setPixelColor(cibleEnCours+reserveLedCible, pixels.Color(0, intensiteLed, 0));
          pixels.show();   // Mise a jour de la couleur des leds. 
          delay(100);
        }
      determinerRang();
       
    }
    else{
      EcranMiss();
      soundMiss();
        for (int i=0; i<4;i++){
          pixels.clear();
          pixels.show();
          delay(100);
          pixels.setPixelColor(cibleEnCours+reserveLedCible, pixels.Color(intensiteLed, 0, 0));
          pixels.show();   // Mise a jour de la couleur des leds. 
          delay(100);
        }
      pointBonus[joueurEnCours] = 0;
      killer[joueurEnCours] = 0; 
    }
}

void testKiller(){
  if (killer[joueurEnCours] == 1){
    EcranSansFautes();
  }
}

void triclassement(){
//***********************************************************************************************
// classer classement[] = {0,0,0,0,0};int scores[] = {0,0,0,0,0};
// pour ne pas faire le tri plusieurs fois, sera mis  1  la fin du traitement, remis  0 au dpart de la partie suivante
// remplissage du tableau de classement
classement[1]=1;
classement[2]=2;
classement[3]=3;
classement[4]=4;
classement[5]=5;
// tri  bulle
  do
    { // boucle do/while
    classement[0]=0; // sera utilis dans le tri comme flag de permutation
      for (int i = 1 ; i < 5 ; i++)
        { // on parcourt le tableau
          if (scores[classement[i]]<scores[classement[i+1]])
            { // si le score de l'lment est <  l'lment suivant, on permute
            classement[0]=classement[i];          // on stocke le premier lment
            classement[i]=classement[i+1];          // on remonte le suivant
            classement[i+1]=classement[0];          // on termine la permutation
            classement[0]=1;                // on passe le flag de permutation  1
            } // fin if
          } // fin for
    } 
  while (classement[0]==1); // tant qu'on a fait une permutation, on recommence.
//*******************************************************************************************************   
}

void ScoresStringFin(){
 tabScores[0]=(" 1ER : J" + String(classement[1])+ " SCORE " + String(scores[classement[1]]));
 tabScores[1]=(" 2EM : J" + String(classement[2])+ " SCORE " + String(scores[classement[2]]));
 tabScores[2]=(" 3EM : J"  + String(classement[3])+ " SCORE " + String(scores[classement[3]]));
 tabScores[3]=(" 4EM : J"  + String(classement[4])+ " SCORE " + String(scores[classement[4]]));
 tabScores[4]=(" 5EM : J" + String(classement[5])+ " SCORE " + String(scores[classement[5]]));
}

void AfficheFin(){
  
 // variables pour l'animation
 int indexScrollScore=0;
 unsigned long currentMillis = millis();
 unsigned long previousMillis = millis();
 unsigned long period = 1500;
  
 //EcranWait();
 Temporisation();
 ScoresStringFin(); 
 
 while(statusBoutonD==HIGH){
   
   currentMillis = millis(); // rcupre le temp actuel
   if (currentMillis - previousMillis >= period) { // check si "period" dpasse
     previousMillis = currentMillis;   // sauve
     EcranFinScores(indexScrollScore);
     
     indexScrollScore++;
     if (indexScrollScore>4)
       {indexScrollScore=0;}
   
   }  
  
  AcquisitionCapteurs();
  }
  
  
  delay(500);
  
    while(statusBoutonD==LOW){
      couleurAleatoire();
      delay(200);
      AcquisitionCapteurs();
      tone(Buzzer,450,125);
      delay(125);
      noTone(Buzzer);
    }
}

void determinerRang(){
    if (scores[joueurEnCours] < 1)                               {classement[joueurEnCours]=0;}
    if (scores[joueurEnCours] >0   && scores[joueurEnCours]<3)   {classement[joueurEnCours]=1;}
    if (scores[joueurEnCours] >2   && scores[joueurEnCours]<5)   {classement[joueurEnCours]=2;}
    if (scores[joueurEnCours] >4   && scores[joueurEnCours]<27)  {classement[joueurEnCours]=3;}
    if (scores[joueurEnCours] >26  && scores[joueurEnCours]<42)  {classement[joueurEnCours]=4;}
    if (scores[joueurEnCours] >41  && scores[joueurEnCours]<57)  {classement[joueurEnCours]=5;}
    if (scores[joueurEnCours] >56  && scores[joueurEnCours]<72)  {classement[joueurEnCours]=6;}
    if (scores[joueurEnCours] >71  && scores[joueurEnCours]<87)  {classement[joueurEnCours]=7;}
    if (scores[joueurEnCours] >86  && scores[joueurEnCours]<117) {classement[joueurEnCours]=8;}
    if (scores[joueurEnCours] >116 && scores[joueurEnCours]<147) {classement[joueurEnCours]=9;}
    if (scores[joueurEnCours] >146 && scores[joueurEnCours]<222) {classement[joueurEnCours]=10;}
    if (scores[joueurEnCours] >221 && scores[joueurEnCours]<297) {classement[joueurEnCours]=11;}
    if (scores[joueurEnCours] >296 && scores[joueurEnCours]<447) {classement[joueurEnCours]=12;}
    if (scores[joueurEnCours] >446 && scores[joueurEnCours]<597) {classement[joueurEnCours]=13;}
    if (scores[joueurEnCours] >596 && scores[joueurEnCours]<747) {classement[joueurEnCours]=14;}
    if (scores[joueurEnCours] >746 && scores[joueurEnCours]<897) {classement[joueurEnCours]=15;}
    if (scores[joueurEnCours] >897 && scores[joueurEnCours]<1002){classement[joueurEnCours]=16;}
    if (scores[joueurEnCours] >=1002)                            {classement[joueurEnCours]=17;}
    
    if (classement[joueurEnCours] != oldClassement[joueurEnCours]){
            //desactivation du level up
            //LevelUp(classement[joueurEnCours]);  
            oldClassement[joueurEnCours]=classement[joueurEnCours];
          }
    
}


void LevelUp(int level){
  const char* texteGrade[] = {"Essaye encore","Pas mal","Assez bien","Bien","Tres bien","Excellent","Soldat","Soldat d elite","Soldat d'excellence","Guerrier","Grand guerrier",
"Super guerrier","Guerrier legendaire","Mega guerrier","Hyper guerrier","Ultime guerrier","Ultra instinct","Game Breaker",};
  if (level > 17 or level<1){level=0;}
  String Grade= texteGrade[level];
  lcd.clear();
  lcd.setCursor(6,1);
  lcd.print(F("LEVEL UP"));
  lcd.setCursor((20-Grade.length())/2,2);
  lcd.print(Grade);
    for (int i=0;i<3;i++){
      lcd.noDisplay();
      delay(500);
      lcd.display();
      delay(500);
    }
}

void AcquisitionCapteurs()
{
  statusBoutonG = digitalRead(boutonG);
  statusBoutonD = digitalRead(boutonD);
  statusCible1 = digitalRead(cible1);
  statusCible2 = digitalRead(cible2);
  statusCible3 = digitalRead(cible3);
}

void determinerCibleTouchee(){
    if (statusCible1 ==  HIGH){
      cibleTouchee = 1;  
    } 
    if (statusCible2 ==  HIGH){
      cibleTouchee = 2;  
    } 
    if (statusCible3 ==  HIGH){
      cibleTouchee = 3;  
    } 
    if (statusBoutonD ==  LOW){
      cibleTouchee = 0;  
    }
    if (statusBoutonG ==  LOW){
      cibleTouchee = cibleEnCours;  
    } 
}

void Temporisation(){
  for (int T = 1; T <= 1000 ; T++){
    while(statusBoutonD==LOW || statusBoutonG==LOW || statusCible1==HIGH || statusCible2==HIGH || statusCible3==HIGH){
      AcquisitionCapteurs();
      afficherMoniteurSerie();
        if (statusCible1==HIGH){
          pixels.setPixelColor(reserveLedCible+1, pixels.Color(255, 0, 0));
        }
        else{
          pixels.setPixelColor(reserveLedCible+1, pixels.Color(0, 0, 0));
        }
        if (statusCible2==HIGH){
          pixels.setPixelColor(reserveLedCible+2, pixels.Color(255, 0, 0));
        }
        else{
          pixels.setPixelColor(reserveLedCible+2, pixels.Color(0, 0, 0));  
        }
        if (statusCible3==HIGH){
          pixels.setPixelColor(reserveLedCible+3, pixels.Color(255, 0, 0));
        }
        else{
          pixels.setPixelColor(reserveLedCible+3, pixels.Color(0, 0, 0));
        }  
      pixels.show();
      tone(Buzzer,450,125);
      delay(125);
      noTone(Buzzer);
      delay(delaiTemporisation);
    }
  }
}


void cibleAleatoire(){
if (oldCible[0] == 0 && oldCible[1] == 0){
 //Serial.println("nouvelle série"); 
while(cibleEnCours == oldCible[2])
    {
      cibleEnCours = random(1, 4);
    }
    oldCible[2] = cibleEnCours;
    oldCible[1]=oldCible[0];
    oldCible[0]=cibleEnCours;
}
 else{ 
  //Serial.println("série en cours"); 

    while(cibleEnCours == oldCible[0] || cibleEnCours == oldCible[1])
    {
      cibleEnCours = random(1, 4);
    }
  oldCible[1]=oldCible[0];
  oldCible[0]=cibleEnCours;
 }
}


void resetHistoriqueCibles(){
for(int i=0; i<=1; i++){
oldCible[i] = 0; 
}
}

void couleurAleatoire(){
  R= random(0, 100);
  G= random(0, 255);
  B= random(0, 50);  
    for (int led = 0 ; led < 5 ; led++){
      pixels.setPixelColor(led, pixels.Color(R, G, B));
      pixels.show();  
    }
}

void printBigNum(int number, int startCol, int startRow) {
  // Position cursor to requested position (each char takes 3 cols plus a space col)
  lcd.setCursor(startCol, startRow);
  // Each number split over two lines, 3 chars per line. Retrieve character
  // from the main array to make working with it here a bit easier.
  uint8_t thisNumber[6];
  for (int cnt = 0; cnt < 6; cnt++) {
    thisNumber[cnt] = bigNums[number][cnt];
  }
  // First line (top half) of digit
  for (int cnt = 0; cnt < 3; cnt++) {
    lcd.print((char)thisNumber[cnt]);
  }
  // Now position cursor to next line at same start column for digit
  lcd.setCursor(startCol, startRow + 1);
  // 2nd line (bottom half)
  for (int cnt = 3; cnt < 6; cnt++) {
    lcd.print((char)thisNumber[cnt]);
  }
}



void EcranInitialisation()
{
  if(nbJoueurs == 5){
  lcd.clear();
  lcd.setCursor(0,0);
  lcd.print(F("Arducible Creative- "));
  lcd.setCursor(0,1);
  lcd.print(F("Common BY-SA 4.0    "));
  lcd.setCursor(0,2);
  lcd.print("SOLO TIME ATTACK");
  lcd.setCursor(0,3);
  lcd.print(F("<- NB JOUEURS  OK ->")); 
  }
  else{
  lcd.clear();
  lcd.setCursor(0,0);
  lcd.print(F("Arducible Creative- "));
  lcd.setCursor(0,1);
  lcd.print(F("Common BY-SA 4.0    "));
  lcd.setCursor(0,2);
  lcd.print("Nb joueurs : " + String(nbJoueurs) + "      ");
  lcd.setCursor(0,3);
  lcd.print(F("<- NB JOUEURS  OK ->"));  
  }

}

void EcranTourSuivant()
{
  lcd.clear();
  printBigNum(31, 2, 1);
  printBigNum(26, 5, 1);
  printBigNum(32, 8, 1);
  printBigNum(29, 11, 1); 
  printBigNum(tourEnCours,15,1);
  delay(1000);
}

void EcranJoueurSuivant()
{
  lcd.clear();
  printBigNum(21, 6, 1);
  printBigNum(joueurEnCours,10,1);
  soundChangePlayer();
  delay(2000);  
}


void EcranWait()
{
  pixels.clear();
  pixels.show();
  lcd.clear();
  printBigNum(34, 3, 1);
  printBigNum(12, 7, 1);
  printBigNum(20, 11, 1);
  printBigNum(31, 15, 1);
}

void EcranGo()
{
  lcd.clear();  
  printBigNum(18, 7, 1);
  printBigNum(26, 11, 1); 
}

void EcranHit()
{
  pixels.clear();
  pixels.show();
  lcd.clear();
  printBigNum(18, 3, 1);
  printBigNum(26, 7, 1);
  printBigNum(26, 11, 1);
  printBigNum(15, 15, 1);
}

void EcranMiss()
{
  pixels.clear();
  pixels.show();
  lcd.clear();
  printBigNum(24, 3, 1);
  printBigNum(20, 7, 1);
  printBigNum(30, 11, 1);
  printBigNum(30, 15, 1);
}

void EcranEnJeu()
{
  pixels.setPixelColor(reserveLedCible+cibleEnCours, pixels.Color(0, 0, 255));
  pixels.show();   // Mise a jour de la couleur des leds.  
  lcd.clear();
  lcd.setCursor(0,0);
  lcd.print("Tour  : "+ String(tourEnCours) + "   POINTS");
  lcd.setCursor(0,1);
  lcd.print("Joueur: " + String(joueurEnCours));
  lcd.setCursor(0,2);
  lcd.print("Reste : " +  String(resteEnCours) );
  lcd.setCursor(0,3);
  lcd.print("Pts bonus:" + String(pointBonus[joueurEnCours]) +" CIBLE: " + String(cibleEnCours));
  String scorestring = String(scores[joueurEnCours]);
    if (scorestring.length()==3){
      String centaine = String(scorestring.charAt(0));
      printBigNum(centaine.toInt(), 10, 1);
      String decimale = String(scorestring.charAt(1));
      printBigNum(decimale.toInt(), 13, 1);
      String unite = String(scorestring.charAt(2));
      printBigNum(unite.toInt(), 16, 1);
    }
    else if (scorestring.length()==2){
      String decimale = String(scorestring.charAt(0));
      printBigNum(decimale.toInt(), 12, 1);
      String unite = String(scorestring.charAt(1));
      printBigNum(unite.toInt(), 15, 1);
    }
    else{
      String unite = String(scorestring.charAt(0));
      printBigNum(0, 12, 1);
      printBigNum(unite.toInt(), 15, 1);
    }
   
}
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

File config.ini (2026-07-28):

[TimeSetting]
intro_length = 10
game_length = 60
ending_length = 10
splash_length = 7

[BonusTime]
time = 5
country_change_time = 10

[WorldTour]
hits_per_country = 4

[CamActivation]
webcam = False
camfps = 5

[Screen]
fullscreen = True
crt = False

[Audio]
music = True
effects = True
fadeouttime = 1000

[Resolution]
resolution = 1080

[Debug]
debugline = False
fps = 30
showfps = False
debugcam = True
credit = 0
freeplay = True

[Score]
high_score = 43

[Hardcore]
high_score = 19
hits_per_country = 5

[RoundTheClock]
targets = 7
default_players = 2
min_players = 1
max_players = 6
default_rounds = 3
min_rounds = 3
max_rounds = 12
shots_per_turn = 3
hit_cooldown_ms = 2000
menu_cooldown_ms = 200
banner_duration_s = 5

[Quizz]
high_score = 0

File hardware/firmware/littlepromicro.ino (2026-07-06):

//programme pour jeu Arducible
//auteur Jean-Baptiste GUIRAUD
#include <Keyboard.h>
const int b1 = 10;
const int Cible1 = 15;   
const int Cible2 = 14;   
const int Cible3 = 16;

void setup() {                
  pinMode(b1, INPUT_PULLUP);
  pinMode(Cible1,INPUT);
  pinMode(Cible2,INPUT); 
  pinMode(Cible3,INPUT); 
  Keyboard.begin();
delay(3000);  
}


void loop(){
    if(digitalRead(b1)) {
    Keyboard.release(KEY_RIGHT_ARROW); 
    //delay(100);
    } else {
        Keyboard.press(KEY_RIGHT_ARROW);
    //delay(100);
    }

    if(digitalRead(Cible1)) {
       Keyboard.press('e');  
    //delay(100);  
    } else {
    Keyboard.release('e');
    //delay(100);
    }
    
    if(digitalRead(Cible2)) {
        Keyboard.press('r');
      //  delay(100);
    } else {
        Keyboard.release('r');
       // delay(100); 
    }
    if(digitalRead(Cible3)) {
        Keyboard.press('t');
        //delay(100);
    } else {
        Keyboard.release('t');
        //delay(100);
    }
 
}

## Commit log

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2026-07-06 Ajoute les ressources brutes et la config Claude Code pour reprise multi-poste
    Inclut le dossier ressources/ (CAD FreeCAD, PCB, vidéos sources, archives
    des générations de contrôleur) et .claude/ (config/permissions de session),
    jusqu'ici exclus du suivi, pour permettre de reprendre le projet à
    l'identique depuis un autre poste.
    [ASSEMBLAGEGÉNÉRALv4.FCStd, AssemblageArticulation.FCStd, Boitier-boite.stl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]
2026-07-06 retrait venv
    [pyvenv.cfg]
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2026-07-17 Ajoute la CAD/BOM matérielle et met à jour la nomenclature
    Interface/support RJ45, boîtier, firmware Pro Micro, schémas Fritzing,
    rendus 3D et câblage RJ45, avec le BOM.md mis à jour en conséquence.
    [boitierJeu-facade.stl, boitierJeu-fermeture.stl, boitierJeu-supportws2812.stl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]
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2026-07-17 Ajoute Round the Clock, 2e jeu sur le châssis à 7 cibles
    Portage fidèle du multijoueur au tour par tour (1 à 6 joueurs, 3 à 12
    manches) depuis la version Lua/Defold d'origine
    (ressources/Petanque-challenge-Round-the-clock/), avec ajout du suivi de
    zone par webcam absent de l'original. Chassis à 7 cibles en étoile de
    David (6 boules + cochonet central), touches E R T Y U I O.
    Le code source Defold d'origine est inclus tel quel pour référence
    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
    [boitierV3.FCStd]
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2026-07-17 Documente le tour à 115 pays et la session du 15-16 juillet
    README.md : les mentions "111 pays"/"112 quizz"/"560" étaient restées
    figées après l'ajout du Brésil, d'Israël et du Liban ; passées à 115/115/575.
    COMPTE_RENDU.md : résumé de session pensé pour reprendre le travail sur
    un autre poste sans Claude Code (continent select, police, palette,
    crédits/freeplay, correctif high score, HUD Hardcore, sensibilité
    MediaPipe).
2026-07-17 Ajoute la révision v3 du PCB de détection (connecteur JST-XH)
    Nouveaux fichiers de commande JLCPCB (Gerber/BOM/Pick & Place, générés
    le 2026-07-17) archivés dans ressources/archives/PCB pour détection/last
    pcb/ et copiés dans hardware/pcb/*-v3.* pour l'import direct. Ajoute un
    connecteur JST-XH 3 points (DATA/-/+) par rapport à la version 2022.
    index.html et hardware/BOM.md mis à jour pour pointer vers cette
    nouvelle révision, l'ancienne étant conservée pour référence.
    [BOM_ArducibleSMD_2026-07-17.csv, PickAndPlace_arduciblesmdv3_2026-07-17.csv, bom-jlcpcb-v3.csv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]
2026-07-17 Aligne les écrans de main.py/main_quizz.py sur main_hardcore.py
    "CHOISIS TON MODE" (main.py) et le bloc "GAME START IN" + décompte
    (main.py, main_quizz.py) remontés aux mêmes positions que
    main_hardcore.py (y=2/20 et y=8/20-10/20-12/20), qui n'avaient pas été
    répercutées sur les deux autres jeux lors du dernier ajustement HUD.
    Corrige aussi deux mentions "111/112 pays" restées figées dans les
    docstrings de main_hardcore.py/main_quizz.py après l'ajout du Brésil,
    d'Israël et du Liban (115 pays).
2026-07-17 Documente le fonctionnement des 4 jeux dans le README
    Ajoute un tableau récapitulatif (chassis, principe, touches, modes,
    high score) et une section "Choix du mode" décrivant le flux commun
    accueil -> sélection tour complet/continent -> décompte -> partie,
    jusqu'ici non documenté.
    Corrige au passage : la section Quizz affirmait encore "aucun fichier
    audio pour l'instant" alors que la narration TTS (assets/Sounds/QuizzTTS/,
    Scripts/quiz_audio.py) est bien branchée ; un "560" oublié lors du
    passage à 115 pays (devait être 575) ; ajoute les sections [Quizz] et
    [RoundTheClock] à la table config.ini et les 3 autres jeux à la
    structure du projet (seul main.py y figurait).
2026-07-17 Améliore le référencement Google (SEO) de index.html
    - Structure HTML correcte (<!doctype>/<html lang="fr">/<head>/<body> :
    le fichier n'avait aucun de ces éléments, juste des balises nues.
    - Ajoute un <h1> (absent de toute la page, tout partait de h2),
    visuellement masqué (.sr-only) pour ne pas changer le design.
    - Canonical, Open Graph, Twitter Card, JSON-LD (schema.org/VideoGame).
    - Ajoute robots.txt et sitemap.xml (absents, la page ne les avait jamais
    eus alors qu'elle est bien indexable sur GitHub Pages).
    - Corrige 3 mentions "111 pays" oubliées lors du passage à 115.
    Toutes les URLs pointent vers le dépôt github.com/guiraudjb/
    Arducible_Fanny_Petanque_World_Tour (renom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
2026-07-17 Ajoute des mots-clés multilingues au référencement (SEO)
    Vu les 115 pays représentés dans le tour : alternateName en JSON-LD
    (Petanque, Petanca, Petong/เปตอง, петанк — nommages vérifiés via les
    recherches déjà faites sur l'écosystème pétanque du projet), inLanguage,
    meta keywords, et une phrase visible mentionnant ces noms locaux à côté
    du bloc de stats (le contenu réellement indexé compte plus que les
    balises meta). Corrige aussi "cent onze pays"/stat "111" oubliés lors
    du passage à 115.
    Pas de hreflang / og:locale:alternate : la page n'existe qu'en français,
    en ajouter aurait été incorrect (pas de contenu traduit correspondant).
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2026-07-18 Ajoute les plans cotés des 3 plaques et corrige leurs cartouches
    Chaque plaque (sup/inf/milieu) avait déjà une page TechDraw complète
    dans son .FCStd (vues projetées + cotes), jamais exportée jusqu'ici.
    Ajoute hardware/plans/plaque-{sup,inf,milieu}.pdf et les lie depuis
    index.html et hardware/BOM.md.
    Corrige au passage un copier-coller non renommé dans les cartouches :
    plaque-inf.FCStd affichait "Plaque supérieure", plaque-milieu.FCStd
    affichait "Plaque inférieure" (seul plaque-sup.FCStd était correct).
    Connu et volontairement non touché : plusieurs cotes d'espacement de
    trous sur le plan de plaque-inf affichent 0 au lieu d'une vraie valeur
    (2 références de cote corrompues, in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
    [plaque-inf.FCStd, plaque-milieu.FCStd]
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2026-07-18 Corrige la cote de diamètre cassée sur le plan de plaque-inf
    3 cotes du plan de plaque-inf.FCStd référençaient des arêtes obsolètes
    (2D references corrompues, une pointait vers une ligne au lieu d'un
    cercle) : la cote de diamètre (4e trou du losange central) a été
    recréée en la rattachant au cercle réel, revérifiée par export -
    affiche maintenant Ø4,5 comme les 3 trous identiques déjà corrects.
    Les 2 cotes d'espacement X/Y ont été supprimées plutôt que recréées :
    la première tentative affichait 7,32 mm pour les deux (alors que la
    géométrie du sketch suggère plutôt 14 mm chacune), valeur qui n'a pas
    pu être vérifiée avec confiance - une cote absente vaut mieux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
    [plaque-inf.FCStd]
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2026-07-18 Corrige les 2 dernières cotes cassées sur le plan de plaque-inf
    Trouvé pourquoi la tentative précédente donnait 7,32 mm au lieu de 14 :
    une cote Distance entre deux Edge de cercle mesure l'écart entre leurs
    bords (distance centre-à-centre moins les 2 rayons), pas centre-à-centre
    - vérifié sur une paire de trous alignés (28 mm réels, 23,5 mm mesurés =
    28 - 2×2,25 de rayon).
    Solution : référencer le Vertex du centre de chaque cercle plutôt que
    son Edge (chaque cercle expose 3 vertices dans la vue TechDraw : 2 points
    dupliqués au point le plus à gauche + le centre réel en 3e). Donne
    maintenant 14 mm sur les deux axes, confirmé par export et par une
    réouverture indépendan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
    [plaque-inf.FCStd]
2026-07-19 Met à jour le PCB détection v3, le câblage et les rendus CAD sur index.html
    Connecteur JST-XH replacé en face arrière du PCB (detection-pcb-v3.FCStd),
    carte intégrée dans les assemblages articulation/châssis, nouveau composant
    Fritzing réutilisable (PetanqueDetection_Board_v3.fzpz) câblé en direct sur
    la Pro Micro. Rendus 3D régénérés (articulation, châssis, PCB isométrique)
    et schéma de câblage réexporté depuis Fritzing ; liens cassés par la
    suppression des anciens fichiers PCB corrigés dans index.html et BOM.md.
    [OBJ_arduciblesmdv3.obj, assemblage-articulation.FCStd, cablage-pro-micro.fzz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]
2026-07-19 Réorganise index.html en 5 parties et corrige le sens de la détection
    Nouvel ordre : jeu vidéo, châssis, cible et son articulation, électronique
    (fusion contrôleur + PCB + câblage), puis une partie dédiée à la
    modélisation 3D des pièces sur mesure (boîtier Pro Micro, entretoise,
    interface axe-aimant). Corrige aussi la description du mécanisme de
    détection : au repos l'aimant est aligné face au capteur, un choc désaxe
    le bracket et écarte l'aimant, le tampon ressort le ramène en position
    nominale et le réaligne — ce n'est pas l'impact qui amène l'aimant devant
    le capteur, comme le texte le disait par erreur.
2026-07-19 Ajoute un menu flottant et une section Goodies (cartes postales, jeu de cartes, tenues de Fanny)
    Menu flottant fixe avec ancres vers chaque partie et surlignage de la
    section active au scroll (IntersectionObserver). Nouvelle section en fin
    de page : diaporama des 112 cartes postales du tour, galerie des portraits
    de Fanny en tenue locale, et les deux jeux de cartes (deck_1/deck_2)
    complets. Mentionne les jeux jouables à venir (solitaire, vidéo poker,
    blackjack) sans les implémenter.
    Assets sources (ressources/teaser/postcards, assets/Images/FannyWorldTour,
    ressources/playing_cards) trop volumineux pour le web (246+159+54 Mo) :
    nouveau dossier goodies/ avec versions optimisées (33 Mo au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
2026-07-19 Corrige le rognage de l'image d'en-tête sur les viewports peu hauts
    .hero combine aspect-ratio:16/9 et max-height:92vh ; sur un viewport large
    mais peu haut, la boîte s'aplatit sous ce plafond et object-fit:cover
    rognait le haut/bas de l'image (pourtant déjà en 16:9 pur, 1600x900).
    Passage à object-fit:contain : l'image reste toujours entière.
2026-07-19 Remplace le rendu statique du châssis par un GIF animé (rotation 360°)
    36 frames rendues sous FreeCAD headless (caméra orthographique tournant
    en azimut à élévation fixe, hauteur de vue constante pour un zoom stable
    sur toute la rotation), assemblées en GIF via ffmpeg (palette dédiée,
    640x480, 10 fps, boucle infinie, 520 Ko).
    Contourne un bug de auto-clipping de Coin/FreeCAD : à azimut exactement
    0/90/180/270°, la position caméra tombe pile sur un axe de symétrie de
    l'objet et le calcul automatique des plans near/far part en valeurs
    négatives (image blanche). Décalage de 0.037° à chaque azimut pour éviter
    ces angles dégénérés.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
2026-07-19 Remplace le rendu statique de l'articulation par un GIF animé (rotation 360°)
    Même pipeline que le châssis (turntable 36 frames, caméra orthographique
    en azimut variable / élévation fixe, hauteur de vue constante, décalage
    de 0.037° pour éviter le bug d'auto-clipping FreeCAD/Coin aux azimuts
    0/90/180/270°). 640x480, 10 fps, boucle infinie, 676 Ko.
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2026-07-20 Intègre la rotule GE8 articulée et le tampon ressort déformable dans l'assemblage réel
    La rotule GE8 (chape fixe + bille solidaire de l'axe) et le tampon ressort
    CR60 (profil déformable) remplacent la géométrie figée d'origine dans
    assemblage-articulation.FCStd, sans toucher aux contraintes A2plus
    existantes (RotuleGE8_001/tamponressort_001 conservés mais masqués).
    Renders officiels regénérés (vues face/droite/dessous + turntable 360°) et
    script de rendu sauvegardé pour réutilisation future. BOM.md et index.html
    mis à jour avec les nouveaux fichiers CAD et la correction du matériau du
    tampon (polychloroprène, pas silicone).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
    [assemblage-articulation.FCStd, rotule-ge8-articulee.FCStd, tampon-ressort-cr60-deformable.FCStd]
2026-07-20 Corrige une dernière mention du tampon ressort en silicone (partie châssis)
    Manquée lors de la correction précédente (polychloroprène, pas silicone) —
    repérée en vérifiant le rendu déployé sur GitHub Pages.
2026-07-20 Ajoute la rondelle 8x22x1,5 en CAO, les liens fournisseurs manquants et une réflexion sur les boules perçables/taraudées
    Complète la nomenclature de l'articulation (visserie, rotule GE8C, rondelles,
    tampon ressort) avec les liens Fournisseur qui manquaient, modélise et rend la
    rondelle 8x22x1,5mm jusque-là non modélisée, corrige la mention "boule pleine"
    (simplification CAO, jamais le cas en réalité) et documente le retour
    d'atelier + la recherche infructueuse d'une boule ∅70mm prête à l'emploi.
    [rondelle-8x22x1-5.FCStd]
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2026-07-20 Refond la page d'accueil en deux niveaux de lecture : Vitrine et Laboratoire
    Réécrit l'introduction en accroche grand public (sensations de jeu, tour du
    monde, webcam comme "arbitre numérique", bonus goodies), ajoute une section
    de transition vers la partie technique (licence CC BY 4.0), et une synthèse
    "Le Laboratoire" en 3 domaines d'ingénierie (matériel, électronique,
    logiciel & vision) avant le détail pièce par pièce déjà présent plus bas.
    Corrige la mention imprécise des "boules de pétanque" en Vitrine : ce sont
    des boules souples Al'Comm (Jean-Pierre Albertini), pas des boules acier.
    Ajoute deux illustrations à droite du texte d'introduction (capture des
    Apéros de la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
2026-07-20 Refond le Blackjack en interface état de l'art, zéro scroll, responsive
    Grille CSS en 100dvh (jamais de scroll), cartes en aspect-ratio verrouillé
    (jamais déformées), largeur bornée par min(vw, dvh) pour ne jamais déborder
    même en paysage. Rendu DOM incrémental (au lieu d'un innerHTML='' à chaque
    frame) pour permettre de vraies animations : distribution en cascade depuis
    le sabot, flip 3D de la carte cachée du croupier, ramassage des plis entre
    les manches, tremblement sur bust, flash de victoire/défaite avec confettis
    en Canvas, retour visuel sur chaque bouton/jeton.
    Intègre l'illustration de Fanny en croupière comme bannière (ratio fixe,
    recadrée en JPEG pour rester légè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
2026-07-20 Refond Vidéo Poker et Solitaire en interface état de l'art, zéro scroll ; ajoute la vérification Google Search Console
    Vidéo Poker : même architecture que le Blackjack (grille 100dvh, cartes en
    aspect-ratio verrouillé, bannière Fanny, tapis pétanque). Table des gains
    compactée en badges qui se surlignent sur la combinaison obtenue, cercle de
    lancer au centre, distribution en cascade, animation de "swap" façon flip
    sur les cartes échangées, confettis + flash à la victoire.
    Solitaire : bannière réduite dédiée (nouveau recadrage centré sur le
    visage de Fanny) pour préserver l'espace vertical des 7 colonnes.
    L'espacement des cartes empilées est recalculé dynamiquement à c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
2026-07-21 Agrandit les cartes du Vidéo Poker et exploite toute la largeur du tapis
    Supprime le grand cercle décoratif ("zone de lancer") qui absorbait tout
    l'espace vertical central sans utilité pour ce jeu — cet espace revient
    à la main de cartes, qui passe en léger chevauchement façon éventail
    (même technique que le Blackjack) pour permettre des cartes nettement
    plus grandes sans jamais déborder horizontalement sur petit écran.
    Bannière de Fanny légèrement agrandie pour combler l'espace résiduel.
    Testé en Chrome headless : zéro dépassement (vertical et horizontal) sur
    mobile portrait/paysage, tablette et desktop ; clic individuel sur une
    carte chevauchée vérifié correct.
    Co-A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
2026-07-22 Agrandit les cartes de Blackjack, Vidéo Poker et Solitaire
    Blackjack et Vidéo Poker : bornes de --card-w nettement augmentées (leurs
    mains ne dépassent jamais 5-6 cartes, marge confortable disponible).
    Solitaire : augmentation plus modeste, contrainte par la géométrie fixe
    de ses 7 colonnes (au-delà d'une certaine taille de carte, les colonnes
    se chevaucheraient) ; espacements/paddings resserrés pour maximiser la
    taille malgré cette limite.
    Corrige au passage deux bugs préexistants dans le calcul dynamique de
    l'espacement des piles du Solitaire (révélés, pas causés, par
    l'agrandissement) :
    - Le code lisait le texte brut de la variable CSS --card-w (l'expression
    clamp() elle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
2026-07-23 Belote : partie 2v2 en équipes, IA experte et distribution réaliste
    Passage d'une belote simplifiée 2 joueurs à une vraie partie à 4 en
    équipes (vous + Fanny contre Marcel + Bernard), avec enchères, atout,
    chute, belote-rebelote et dix de der. Distribution animée et temporisée
    (3 puis 2 cartes, coupe visible), plis tenus plus longtemps et rangés
    sur le côté, annonces de tour et cartes qui s'envolent en tournoyant.
    Le paquet n'est plus jamais rebattu après la toute première mène d'une
    partie : on se contente de couper entre deux mènes, comme à la vraie
    belote jouée à la maison. Les bots (moteur cognitif dédié dans ai.js,
    un profil distinct par bot) exploitent cette règl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
2026-07-23 Belote : IA agressive à la prise, défense affûtée, ergonomie de lecture
    Les bots prennent désormais systématiquement sur un bon jeu (seuil bas,
    indépendant de la position de parole) ; en contrepartie, la défense
    épuise plus activement l'atout du preneur pour faire chuter les
    contrats spéculatifs. Corrige aussi une réplique de la croupière qui
    citait encore l'ancienne version à 16 cartes.
    Cartes du pli central et carte retournée agrandies pour rester lisibles.
    L'atout choisi est maintenant affiché en gros, au-dessus du siège qui a
    réellement pris (et non plus à côté du score de son équipe).
2026-07-23 Belote : pause de révélation à la prise, meilleur rythme, corrections texte
    Quand un joueur (humain ou bot) prend l'atout, le plateau marque
    désormais une vraie pause : la carte retournée grossit et brille (ou un
    gros symbole de couleur apparaît au 2e tour), avec une grande
    confirmation textuelle, avant que la main complétée n'apparaisse. Les
    cartes qui arrivent après la prise (talon + retourne) sont animées
    plutôt que de surgir instantanément.
    Rythme général ralenti (délais IA, tenue des plis, distribution) pour
    une partie moins précipitée. Corrige aussi une réplique de la croupière
    qui restait fausse quel que soit le preneur ("à vous d'annoncer
    l'atout" alors que l'ato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
2026-07-24 Corrige les animations de distribution/jeu de la Belote
    Les cartes ne volaient jamais vers le joueur ni Fanny : leurs conteneurs
    n'avaient pas de min-width et s'effondraient à largeur 0 une fois vidés,
    ce qui faisait avorter silencieusement flyCard(). Ajoute aussi une vraie
    animation de distribution pour le complément de main après une prise, et
    un zoom progressif (petit -> grand) pour les cartes jouées au centre.
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2026-07-24 Belote : trie la main du joueur en alternant rouge/noir par enseigne
    Regroupe les cartes par enseigne (atout d'abord une fois connu) mais
    enchaîne les 4 paquets en alternant systématiquement rouge/noir plutôt
    que l'ordre fixe précédent, qui pouvait mettre deux enseignes de même
    couleur côte à côte. Corrige au passage la main initiale de 5 cartes
    (avant l'enchère), jusqu'ici jamais triée du tout.
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2026-07-24 Belote : corrige le rognage de la main à 8 cartes sur mobile
    Sur un écran de téléphone étroit, l'éventail de la main (rotation +
    chevauchement) faisait sortir le coin supérieur gauche de la première
    carte de l'écran, rendant sa valeur illisible - vérifié : la carte se
    retrouvait à une position négative, hors du viewport.
    - Éventail plus serré à mesure que la main grandit (moins de rotation
    par carte, plus de chevauchement) pour 6 à 8 cartes ; aucun changement
    pour les 5 cartes de l'enchère.
    - Filet de sécurité : la largeur réelle de l'éventail (rotation comprise)
    est mesurée sur le DOM après affichage, et réduite d'un coup si besoin
    pour tenir dans le conten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
2026-07-27 Ajoute 10 jeux de cartes aux Goodies, harmonise les dos de carte, corrige index.html
    - Publie les 10 decks restants du sélecteur Casino (Classique, Sexy, Plage/Ville,
    Outfits, Décennies, Haute Couture, Autre, Voyage, Soirée, Sport) dans
    goodies/cards/ et index.html, à côté des decks Fanny World Tour Vol. 1/2
    - Uniformise le dos de tous les decks sur le visuel Fanny World Tour (motif
    losange + médaillon joueur de pétanque), une couleur distincte par deck ;
    corrige un bug de collision de variable qui donnait un dos terne dans les
    exports d'impression (MPC, Print Europe) et régénère deck_1/deck_2
    - Agrandit la police des index de coin (rang/enseigne) sur tous les sprites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
    [BOM_ArducibleSMD_2026-07-17.csv, Boitier-boite.stl, Boitier-couvercle.stl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]
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2026-07-28 Integre les ajustements manuels de la vue eclatee de l'articulation
    L'utilisateur a repositionne 5 pieces a la main dans une copie dediee
    (assemblage-articulation-eclate-manuel.FCStd, prep_manuel_copy.py) :
    la vis centrale n'est plus fixe (elle s'ecarte comme le reste), plaque
    inferieure remontee, ecrou M8/entretoise/interface axe-aimant ajustes.
    Ces positions relevees sont reportees dans render_articulation_eclate.py
    (MANUAL_TARGET_Z) et les 4 rendus + versions numerotees + legende sont
    regeneres en consequence.
    [assemblage-articulation-eclate-manuel.FCStd]
2026-07-29 Ajoute le turntable de la vue eclatee + met a jour SEO et sitemap
    - Nouveau GIF assemblage-articulation-eclate-turntable.gif (camera fixe,
    la vue eclatee tourne a 360°) et son script render_eclate_turntable.py,
    ajoutes dans index.html a cote des autres animations de l'articulation.
    - sitemap.xml : ajoute les 7 jeux de casino manquants (baccara, belote,
    craps, keno, roulette, scrabble, slots) sur les 10 existants, lastmod
    rafraichis.
    - Meta description/OG/Twitter/JSON-LD : mentionnent maintenant Fanny's
    Casino (10 jeux), absent du texte de reference jusqu'ici.
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2026-08-28 Scrabble : service worker network-first sur le code (fin des versions figées)
    Le SW était cache-first strict sans revalidation : une fois main.js /
    engine.js mis en cache sous un CACHE_VERSION, ces octets étaient servis
    indéfiniment, même après déploiement de code neuf. Un cache antérieur à un
    correctif restait donc bloqué dessus (c'est pourquoi la liste des meilleurs
    coups à égalité, livrée dans df94154, n'apparaissait pas malgré le déploiement).
    Désormais :
    - coquille applicative (navigations + .js/.css/.json/.webmanifest même
    origine) : network-first, repli cache hors-ligne -> le code frais gagne
    au prochain chargement en ligne, sans bump de CACHE_VERSION.
    - reste (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
2026-08-31 Complète Brésil/Israël/Liban (cartes, voix, fonds, portraits) et corrige 14 portraits mal cadrés
    - Génère les cartes-pays et lignes de voix manquantes pour les 3 derniers
    pays (jusqu'ici sans carte ni voix, cf. Scripts/dialogues.py)
    - Remplace les placeholders "TODO" de Brésil/Israël/Liban (fonds + portrait
    Fanny) par de vrais visuels générés (Krea 2), tenues traditionnelles
    respectives, style cohérent avec le reste de la collection
    - Corrige 14 portraits Fanny existants au cadrage cassé (vue plongeante/
    fisheye écrasant le corps, jusqu'au simple buste pour la Pologne) :
    Angleterre, Belgique, Estonie, Irlande, Lituanie, Pologne, Roumanie,
    Serbie, Slovénie, Turquie,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
2026-09-01 Scrabble : durcit le service worker (fin des dictionnaires figés) — v6
    L'anomalie « mot valide refusé » venait d'un mots.txt périmé servi par un
    ancien service worker : cache.addAll rejetait en bloc si un seul des ~30
    fichiers pré-cachés échouait (definitions.csv 43 Mo, un .mp3…), l'install
    échouait, skipWaiting n'était jamais appelé, et l'ancien SW gardait la main
    avec son ancien dictionnaire.
    - pré-cache tolérant : Promise.allSettled sur des listes CRITICAL / OPTIONAL,
    skipWaiting inconditionnel — un asset annexe qui tousse ne fige plus le SW.
    - activate : purge des anciens caches seulement si le nouveau est viable
    (index.html + main.js présents), sinon on les gar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
